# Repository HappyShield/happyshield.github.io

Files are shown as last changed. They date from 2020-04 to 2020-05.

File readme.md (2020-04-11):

# HappyShield.GitGub.io Contribution Guide

## Translations

### Introduction

Thank you so much for your help translating the HappyShield website and instructions!

We hope to translate the following files in this website (`XX` is the [ISO 639-1 code](https://en.wikipedia.org/wiki/List_of_ISO_639-1_codes) for the language): 

<pre>
* index_<b>XX</b>.md <i>(Homepage)</i>
* Instructions/HandCreasing/handCreasing_<b>XX</b>.md <i>(Hand creasing method instructions)</i>
* Instructions/LaserCut/laserCut_<b>XX</b>.md <i>(Laser-cut method instructions)</i>
* Instructions/LaserCutAndPressureCreasing/laserCutAndPressureCreasing_<b>XX</b>.md  <i>(Laser-cut and pressure-creasing method instructions) </i>
* Instructions/WaveShield/waveShield_<b>XX</b>.md <i>(WaveShield production method instructions) </i>
</pre>

### Instructions

Here's how to contribute translations!

### 1. Create a Free GitHub Account

1. If you don't have one already, [create a free GitHub account](https://github.com/join). (If you sign up using an academic email address you are eligible for a free 2-year upgrade to GitHub Pro, but this is not necessary for creating and editing translations to happyshield.github.io).
2. Navigate to [this repository](https://github.com/HappyShield/happyshield.github.io), making sure that you are viewing the main version of the repository: "HappyShield/happyshield.github.io" 

To translate (or edit an existing translation):

### 2. Create and Edit Translation Files

Watch [our video explaining how to create and edit translations files for HappyShield.Github.io here!](https://youtu.be/XLiHhSyrW8A)

The instructions are also shown below: 

##### If the translation file already exists:

1. Navigate to the relevant file in this repository.
2. Click "Edit this File"
3. Type any changes you would like to make to the text in the file. 
4. Add a description explaining the changes you have made.
5. Commit the changes ("Propose File Change")

You can also see this process explained nicely here! https://guides.github.com/activities/hello-world/#commit

##### If the translation file does not yet exist:

1. Navigate to the English version of the file (for example: `Instructions/HandCreasing/handCreasing_EN.md`) which you will be translating into another language. 
2. Click the edit button.
3. Select all of the text in the file and copy it.
4. Close the file. You should have made no changes, so no commit is necessary. 
5. Navigate to the folder where the file should exist.
6. Click create new file, and choose the appropriate name: `Instructions/HandCreasing/handCreasing_TR.md` for "Hand Creasing" instructions in Turkish (TR), for example.
7. Paste.
8. Edit this text, replacing English with your translated text.
7. If you want to save your progress at any point, commit the changes, and provide a description of the changes made since the previous commit.  

#### What should I translate? 

Please translate the following files from English (EN), into your language: 

(Please note that the English version of the homepage (`index.md`) has no `_EN` ending. When creating your translation for this page, please name your new, translated copy of the home page `index_XX.md` where `XX` is your languages's [ISO 639-1 code](https://en.wikipedia.org/wiki/List_of_ISO_639-1_codes).)

<pre>
* index_<b>XX</b>.md <i>(Homepage)</i>
* Instructions/HandCreasing/handCreasing_<b>XX</b>.md <i>(Hand creasing method instructions)</i>
* Instructions/LaserCut/laserCut_<b>XX</b>.md <i>(Laser-cut method instructions)</i>
* Instructions/LaserCutAndPressureCreasing/laserCutAndPressureCreasing_<b>XX</b>.md  <i>(Laser-cut and pressure-creasing method instructions) </i>
* Instructions/WaveShield/waveShield_<b>XX</b>.md <i>(WaveShield production method instructions) </i>
</pre>

When translating these files, please also modify the "header" of the file to correspond to your language:

**Translating Instructions Files**

For example, if we are translating `Instructions/HandCreasing/handCreasing_EN.md` the header we would see to begin with would be:

<pre>
---
layout: page
title: <b>Hand Creasing</b>
tagline: &nbsp <span class="instructionsTaglineEmojiLinks"> <a href="https://youtu.be/8RvlrtrebBE"><i class="em em-video_camera" aria-role="presentation" aria-label="VIDEO CAMERA"></i></a> <a href = "https://github.com/HappyShield/HappyShield/tree/master/Templates/HandCreasing" ><i class="em em-triangular_ruler" aria-role="presentation" aria-label="TRIANGULAR RULER"></i></a></span>
permalink: /hand-creasing/<b>en</b>/
language: <b>en</b>
---
</pre>

When translating instructions files please:

1. Translate the `title` field
2. Update the `permalink` field to the [ISO 639-1 code](https://en.wikipedia.org/wiki/List_of_ISO_639-1_codes) of your language.
3. Update the `language` field to the [ISO 639-1 code](https://en.wikipedia.org/wiki/List_of_ISO_639-1_codes) of your language.

For example, for Portguese ([ISO 639-1](https://en.wikipedia.org/wiki/List_of_ISO_639-1_codes)=`PT`), this would result in:

<pre>
---
layout: page
title: <b>Vincar Manualmente</b>
tagline: &nbsp <span class="instructionsTaglineEmojiLinks"> <a href="https://youtu.be/8RvlrtrebBE"><i class="em em-video_camera" aria-role="presentation" aria-label="VIDEO CAMERA"></i></a> <a href = "https://github.com/HappyShield/HappyShield/tree/master/Templates/HandCreasing" ><i class="em em-triangular_ruler" aria-role="presentation" aria-label="TRIANGULAR RULER"></i></a></span>
permalink: /hand-creasing/<b>pt</b>/
language: <b>pt</b>
---
</pre>

**Translating Homepage File**

When translating the header for `index_XX.md`, please:

1. Translate the `tagline` field.
2. Update the `permalink` field to the [ISO 639-1 code](https://en.wikipedia.org/wiki/List_of_ISO_639-1_codes) of your language.
3. Update the `language` field to the [ISO 639-1 code](https://en.wikipedia.org/wiki/List_of_ISO_639-1_codes) of your language.
3. Remove the `redirect_from` field. 

(No need to translate the title "HappyShield"!) : )

So for example, the header in the English version of the homepage (`index.md`) looks like this to begin with: 

<pre>
---
layout: page
title: HappyShield
tagline: <b>Curved Crease Origami Face Shield For Infection Control</b>
permalink: /<b>en</b>/
language: <b>en</b>
redirect_from: /
---
</pre>

After translating to Lithuanian (`LT`) for example, the header should look like this: 

<pre>
---
layout: page
title: HappyShield
tagline: <b>Origami Veido Skydai Infekcijos Kontrolei</b>
permalink: /<b>lt</b>/
language: <b>lt</b>
---
</pre>

### 3. Submit a Pull Request for Your Translation

When you are ready for your work to be incorporated into the main repository, you will submit a **"Pull request"**, which is a request to have these changes incorporated into the live website.

Watch [our video explaining how to submit a pull request for your translations files for HappyShield.Github.io here!](https://youtu.be/eBnob0MgYTU) 

The instructions are also shown below: 

1. Click **Pull Request**. 
2. Click **Create Pull Request**.
3. Add any helpful description along with your Pull Request to explain to others what you have added or changed to the text.
3. **Submit your Pull Request**. 

Auri (or whoever is managing the repository!) will review and approve the pull request, and then merge these into the main repository, where they should be rendered on the live website within 3-5 minutes. : )

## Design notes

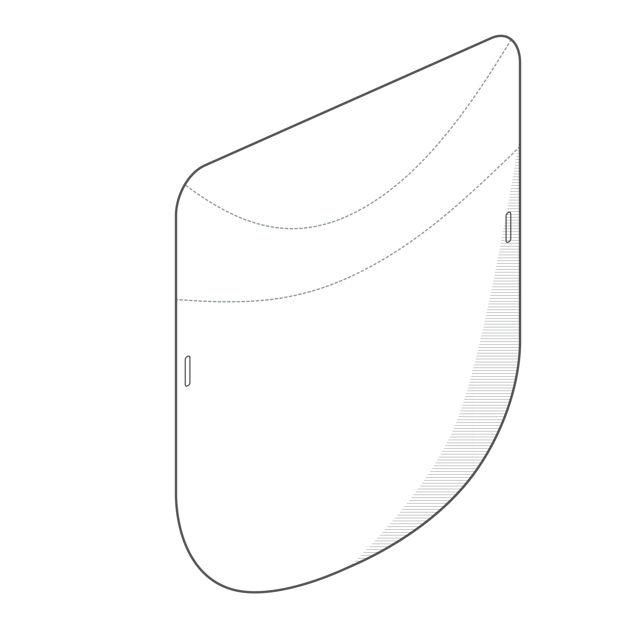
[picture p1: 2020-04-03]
assets/images/HS_Concept_00.gif

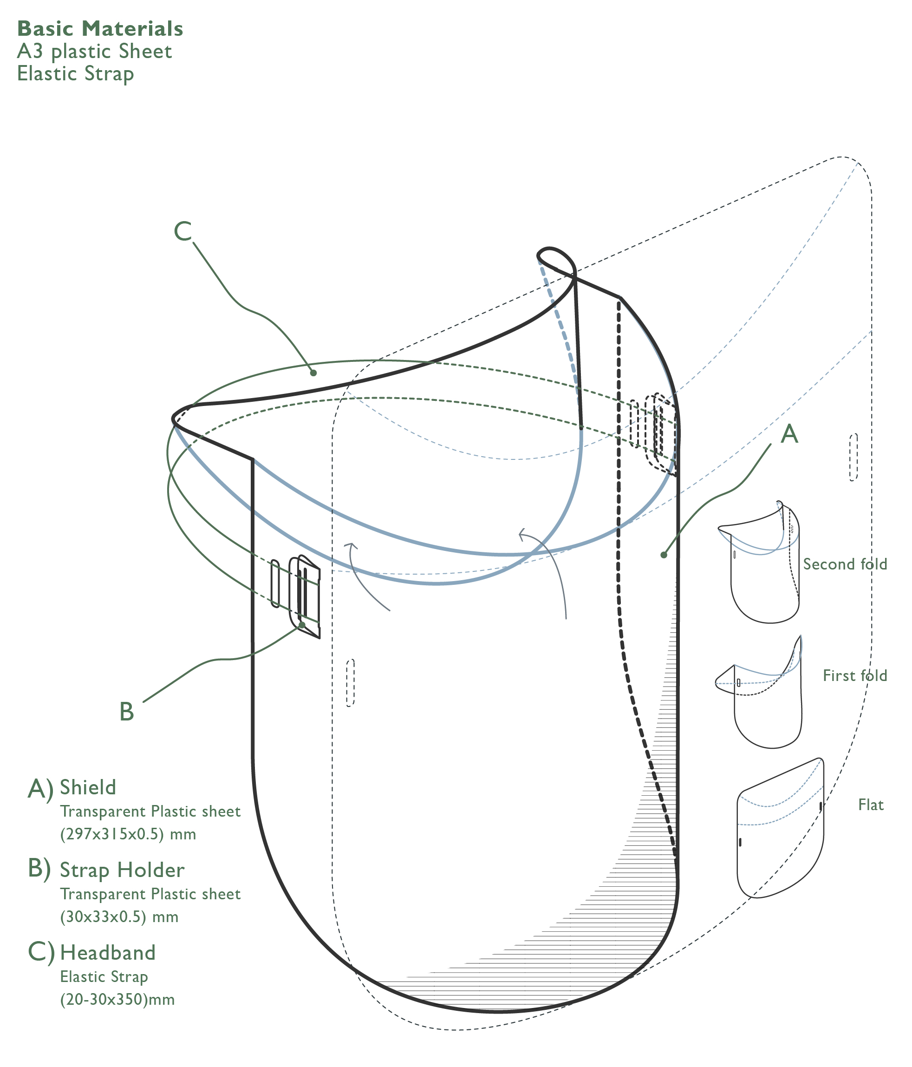
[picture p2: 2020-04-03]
assets/images/SFC_COVER_00.jpg

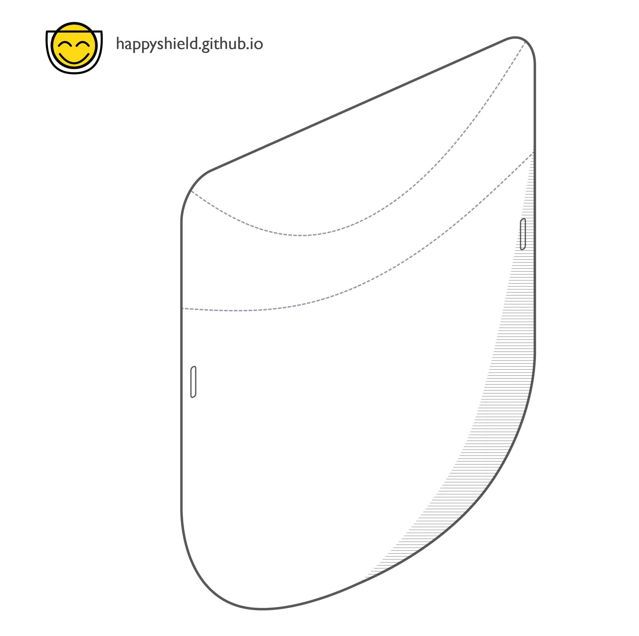
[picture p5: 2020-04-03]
assets/images/HS_GIF_01.gif

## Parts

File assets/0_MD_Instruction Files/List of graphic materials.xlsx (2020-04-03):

Priority Order | Category | Graphics | PDF | Text | Markdown Version | Templates | Video Footage Taken | Video Footage Put into folder | Selected Photos put into folder | Video Edited and Exported
1 | Main Promo Video |  |  |  |  |  | Yes, Auri has taken a fair bit of various movements with the shields, and we have some video and photos of antiopi wearing and doffing and donning the shield | yes auri put into Publicity videos folder | no - working on selecting photos from antiopi's photoshoot and will add these once done | No
2 | Factory Production (AKA laser cutting and pressing) | Done | yes | yes | No | yes | mostly? | auri has added some - apologies for poor quality of video of laser cutting and pressing steps! If completely unusable, could try to film some more today! Let me know @joe! : ) | no | no
3 | DIY (manual creasing) | Yes | Yes | yes | No | yes | yes | yes | no | no
4 | Cardboard and Sandwich Bag Method | No | No | No | No | No | yes | yes | no | no
5 | Laser Cutting - waiting for reply from Tom about fluids through gaps | yes | No | yes | No | No | no - not great, but some exists | yes

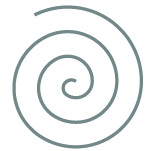
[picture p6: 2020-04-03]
Instructions/UniversalAssets/Materials/HS_FP_MetalWire.jpg

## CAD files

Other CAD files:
assets/0_MD_Instruction Files/HS_FP_Instructions/Template/3PartPressJigTemplate_400x400mm.dwg
assets/0_MD_Instruction Files/HS_FP_Instructions/Template/3PartPressJigTemplate_800x200mm.dwg
assets/0_MD_Instruction Files/HS_FP_Instructions/Template/ShieldsTemplate_620x645mm.dwg
assets/0_MD_Instruction Files/HS_FP_Instructions/Template/ShieldsTemplate_620x340mm.dwg

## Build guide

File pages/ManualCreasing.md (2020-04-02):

---
layout: page
title: "Method: Manual Soft Creasing"
permalink: /manual-soft-creasing/english/
---

## Materials

1. 1x A3 Acetate / PET Sheet
2. 

## Tools 

1. Ballpoint pen
2. Scissors 
3. 

## Instructions

1. Download your tracing template format ([A4 for A3 shields](https://github.com/smileyFaceShield/smileyfaceshield/raw/master/TemplatesAndCNCFilesForScoringFoldingCutting/ShieldScoringFoldingCutting/DIYFromHome/SmileyFaceShield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), Letter for Tabloid shields). If you do not have access to printers, you can draw your own template. Our tracing templates have dimensions!

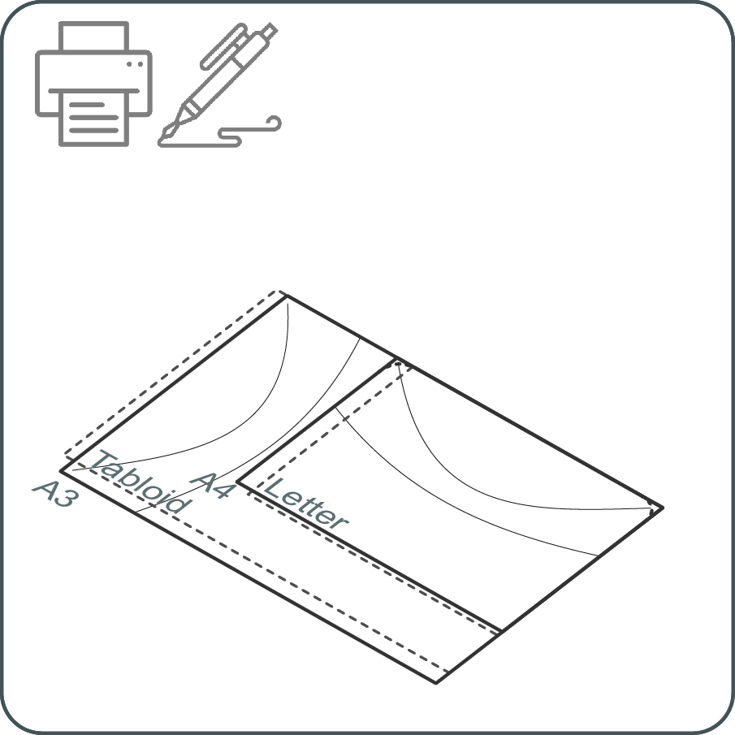
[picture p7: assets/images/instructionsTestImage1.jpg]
Instructions Image Test


2. Place your transparent sheet on the template. Mark the holes location with a ballpoint pen. Don’t worry about the ink, it can be removed with a cloth damped with alcohol.  

3. Mark strap holders and the lower and upper corner rounds for cutting. 

4.

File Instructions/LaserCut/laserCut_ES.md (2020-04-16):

---
layout: page
title: Laser-Cut 
tagline: &nbsp <span class="instructionsTaglineEmojiLinks"><a href = "https://github.com/HappyShield/HappyShield/tree/master/Templates/LaserCut" ><i class="em em-triangular_ruler" aria-role="presentation" aria-label="TRIANGULAR RULER"></i></a></span>
permalink: /laser-cut/es/
language: es
---

<script src="https://snapwidget.com/js/snapwidget.js"></script>
<iframe src="https://snapwidget.com/embed/811086" class="snapwidget-widget" allowtransparency="true" frameborder="0" scrolling="no" style="border:none; overflow:hidden;  width:100%; "></iframe>

---

## Disclaimer

---

The University of Cambridge (UC) and the University of Queensland (UQ) make no warranty of any kind, express or implied, about the design, characteristics, durability, proper use or performance of the HappyShield, including but not limited to implied warranties of merchantability and fitness for any particular purpose. The HappyShield is designed to minimise exposure to fluids and sprays, but UC and UQ do not warrant that HappyShield will protect users from COVID-19 infection or any other infectious disease. Nothing in this material constitutes medical advice, and users should seek their own medical advice about whether HappyShield is suitable for the use they intend, and whether they should use it in conjunction with any other medical or other strategies. To the fullest extent allowed by law, UC and UQ exclude all implied warranties, guarantees, terms and conditions. UC and UQ are not liable for any claims, demands, damages or injuries, including but not limited to property damage, bodily injury or illness, death, indirect, special or consequential damages (“the Claims”) arising out of using the HappyShield, and users of HappyShield release UC and UQ and their officers, employees, contractors and agents from all Claims.

---

--- 

## Tools

---

* Laser-cutter
* Scissors or razor blade

---

## Materials

---

**Shield**

* 0.5 mm thick Polyethylene terephthalate (PET) or Acetate sheet at least 
* 20 mm wide knit elastic strap (70% polyester 30% rubber)

---

---

# Instructions

---

# 1

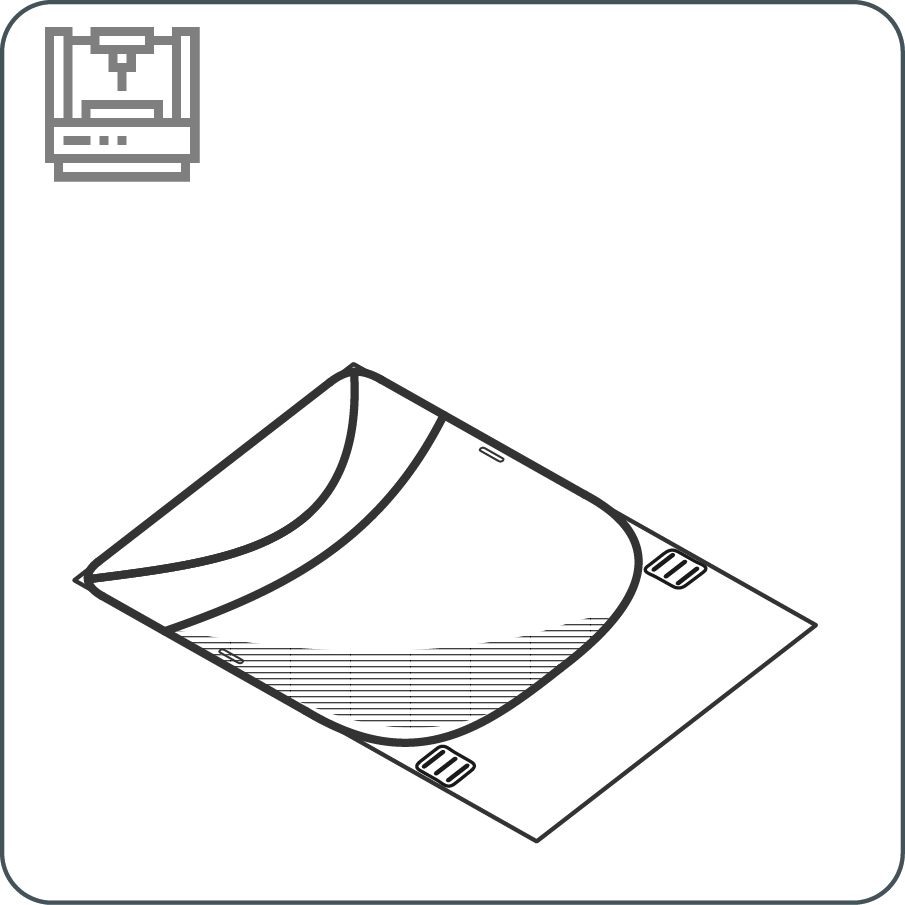
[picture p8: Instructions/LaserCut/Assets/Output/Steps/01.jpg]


Laser-cut the clear plastic sheet material using the template file, ensuring that your laser-cutter power and speed settings ensure a cut completely through the depth of the material.

---

# 2	

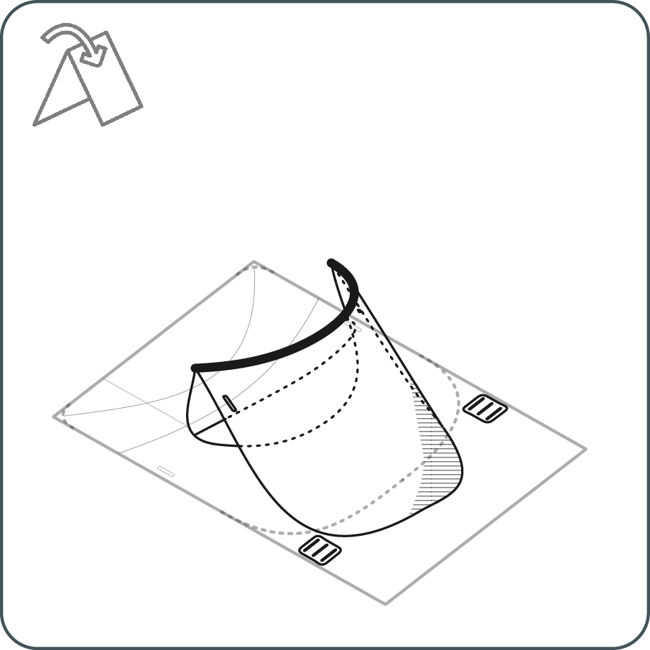
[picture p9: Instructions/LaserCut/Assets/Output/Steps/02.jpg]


Starting on end of one of the crease curves, and working your way to the other end of the curve, gently pinch the sheet to fold it along the curve. 

--- 

# 3 	

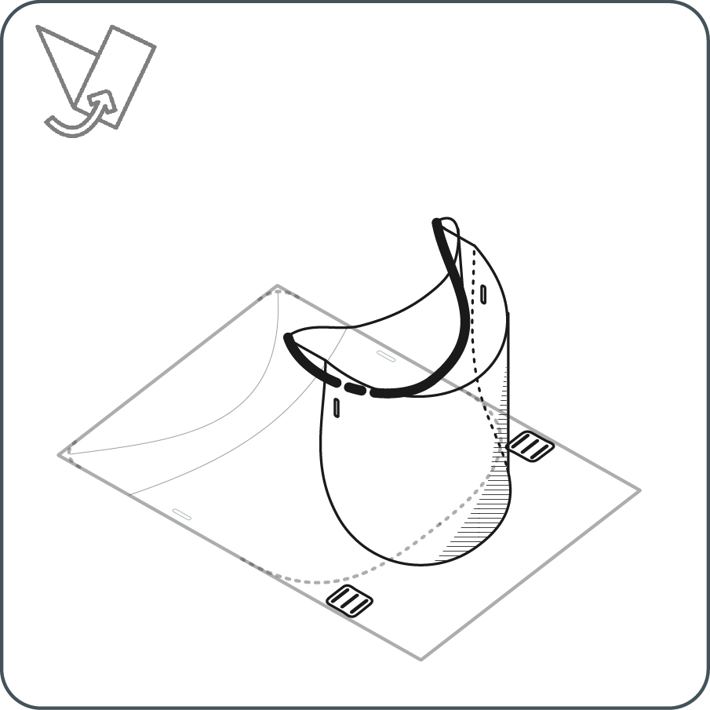
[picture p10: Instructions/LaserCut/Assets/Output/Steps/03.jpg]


Fold the second curve using the same procedure as in Step 2.

---

# 4	

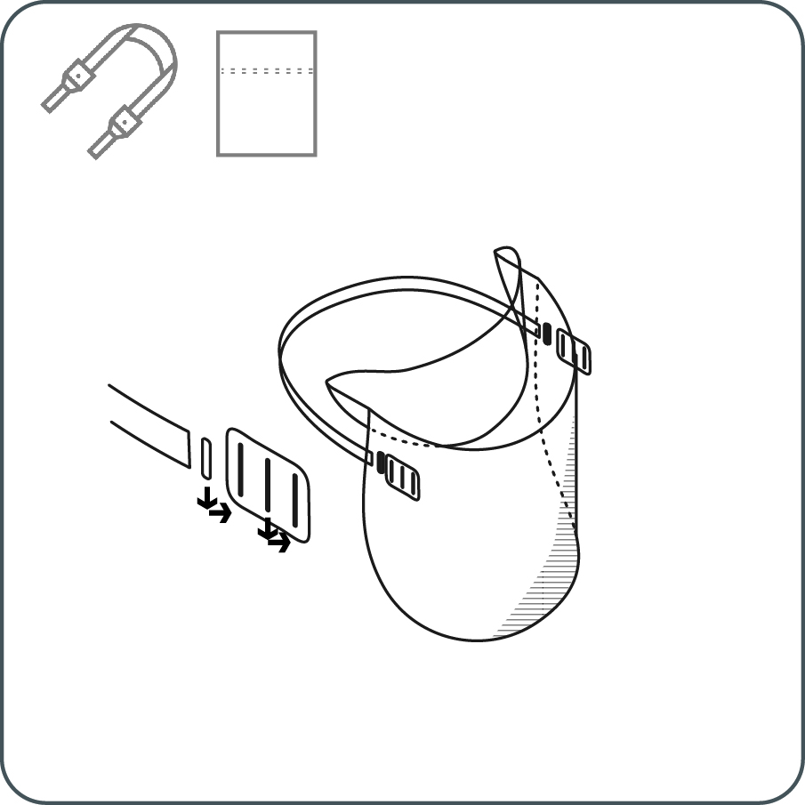
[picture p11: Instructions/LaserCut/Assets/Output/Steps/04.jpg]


Thread the strap through the friction clips. Pass the friction clips through the holes in the shield from the back side of the shield to the front.

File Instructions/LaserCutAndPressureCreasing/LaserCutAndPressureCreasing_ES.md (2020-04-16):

---
layout: page
title: Laser-cut and Pressure Creasing
tagline: &nbsp <span class="instructionsTaglineEmojiLinks"> <a href = "https://youtu.be/IPKiPi-Tne8"><i class="em em-video_camera" aria-role="presentation" aria-label="VIDEO CAMERA"></i></a> <a href = "https://github.com/HappyShield/HappyShield/tree/master/Templates/LaserCutAndPressureCreasing" ><i class="em em-triangular_ruler" aria-role="presentation" aria-label="TRIANGULAR RULER"></i></a></span>
permalink: /pressure-creasing/es/
language: es
---

<script src="https://snapwidget.com/js/snapwidget.js"></script>
<iframe src="https://snapwidget.com/embed/810066" class="snapwidget-widget" allowtransparency="true" frameborder="0" scrolling="no" style="border:none; overflow:hidden;  width:100%; "></iframe>

---

## Disclaimer

---

The University of Cambridge (UC) and the University of Queensland (UQ) make no warranty of any kind, express or implied, about the design, characteristics, durability, proper use or performance of the HappyShield, including but not limited to implied warranties of merchantability and fitness for any particular purpose. The HappyShield is designed to minimise exposure to fluids and sprays, but UC and UQ do not warrant that HappyShield will protect users from COVID-19 infection or any other infectious disease. Nothing in this material constitutes medical advice, and users should seek their own medical advice about whether HappyShield is suitable for the use they intend, and whether they should use it in conjunction with any other medical or other strategies. To the fullest extent allowed by law, UC and UQ exclude all implied warranties, guarantees, terms and conditions. UC and UQ are not liable for any claims, demands, damages or injuries, including but not limited to property damage, bodily injury or illness, death, indirect, special or consequential damages (“the Claims”) arising out of using the HappyShield, and users of HappyShield release UC and UQ and their officers, employees, contractors and agents from all Claims.

---

--- 

## Tools

---

* Laser-cutter
* 10-tonne press
* Pliers capable of cutting 1 mm steel wire rope
* Scissors or razor blade
* Drill or screw-driver

---

## Materials

---

**3-Part Press Jig**

* 4 mm MDF
* 1 mm steel wire rope   
* 6-20 mm wood screws
* Clear plastic tape

**Shield**

* 0.5 mm thick Polyethylene terephthalate (PET) or Acetate sheet
* 20 mm wide knit elastic strap (70% polyester 30% rubber)

---

---

# Instructions

---

## 3-Part Press Jig 

---

# 1 	

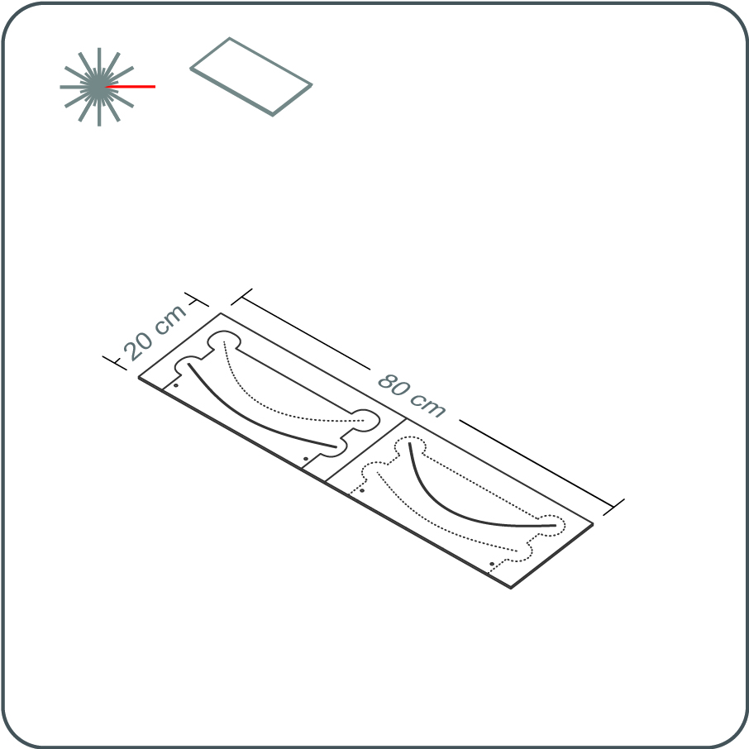
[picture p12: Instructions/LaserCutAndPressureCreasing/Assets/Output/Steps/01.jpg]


Download the laser-cutting template for the 3-part press jig which fits the bed of your laser-cutting machine. (The dimensions of the cutting templates are given in the filenames.) Laser-cut the MDF using the template file.

---

# 2

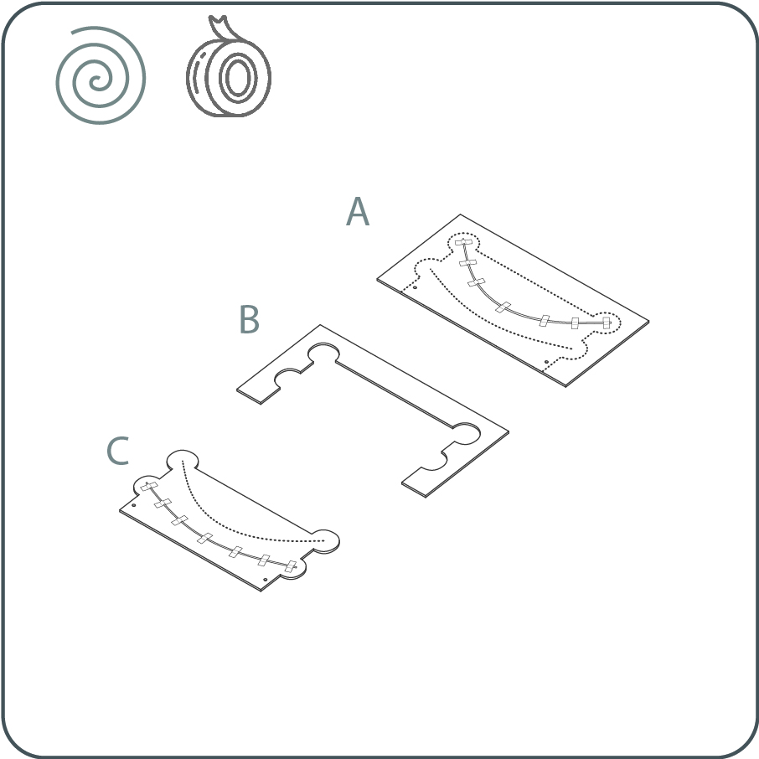
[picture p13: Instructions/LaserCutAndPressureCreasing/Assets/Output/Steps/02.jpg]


Remove the 3 parts of the press jig from the laser-cutter. Cut the wire rope to the length of the dashed curves in parts A and C of the template.
Tape the metal wire onto the dashed curve the groove of the parts A and C of the press jig, being sure not to deviate from the dashed curve, and not to extend beyond the ends of the dashed curve. 

---

# 3

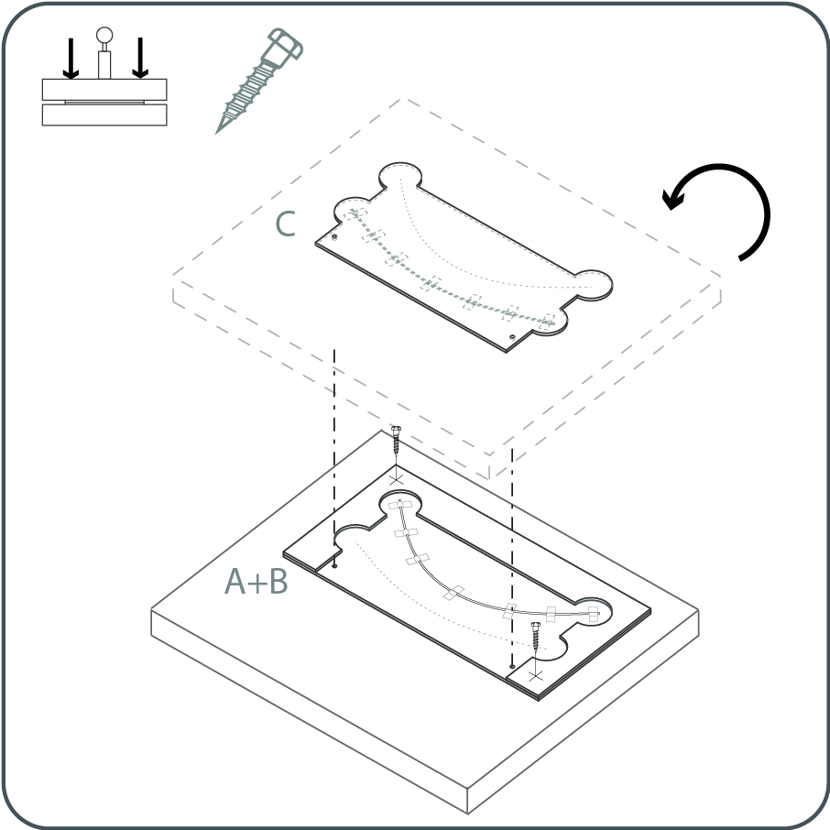
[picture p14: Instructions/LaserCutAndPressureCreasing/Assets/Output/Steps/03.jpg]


Attach Part B to top A using short wood screws. Attach the combined Part A and B to a block as needed to distribute pressure evenly across the jig surface. Do the same for Part C.

--- 

## Shield

---

# 1

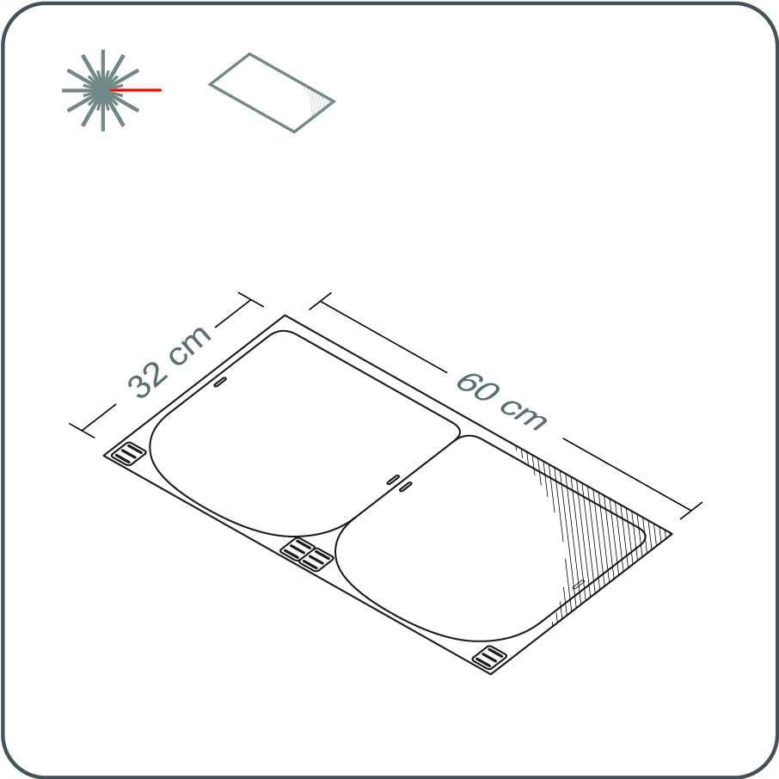
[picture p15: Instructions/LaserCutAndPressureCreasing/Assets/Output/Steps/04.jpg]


Download the HappyShield laser-cutting template which fits in the bed of your laser-cutting machine. (The dimensions of the cutting templates are given in the filenames.)

---

# 2	

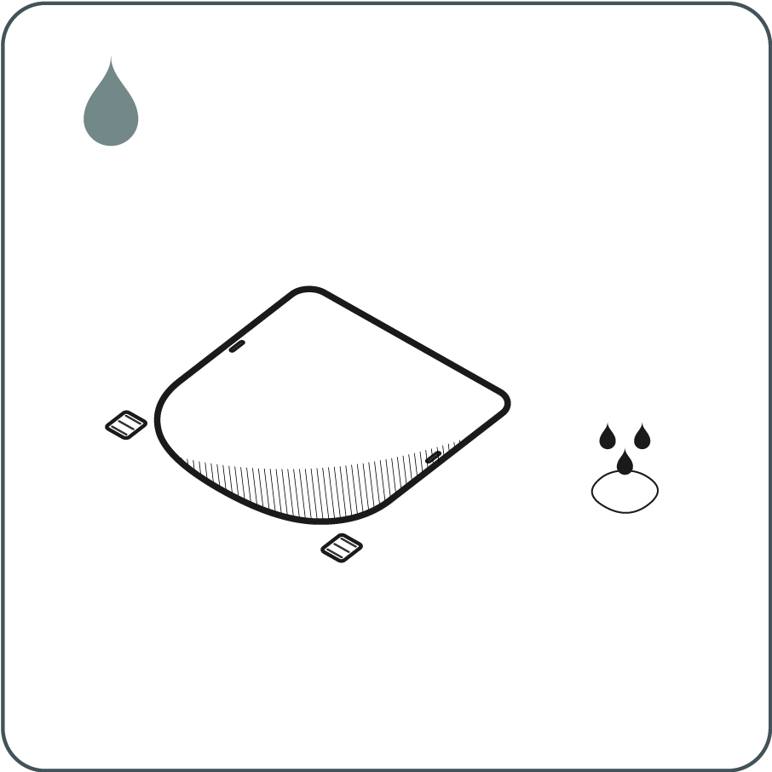
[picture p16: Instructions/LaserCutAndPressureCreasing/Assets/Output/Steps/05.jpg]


Laser-cut the clear plastic sheet material using the template file, ensuring that your laser-cutter power and speed settings ensure a cut completely through the depth of the material.

Once cut, remove the resulting shields and friction clips from the laser-cutter bed. If desired, wipe the edges of the shields and clips with alcohol, or wash with any soap to remove any laser-cutting residues from the sheet. 

--- 

# 3

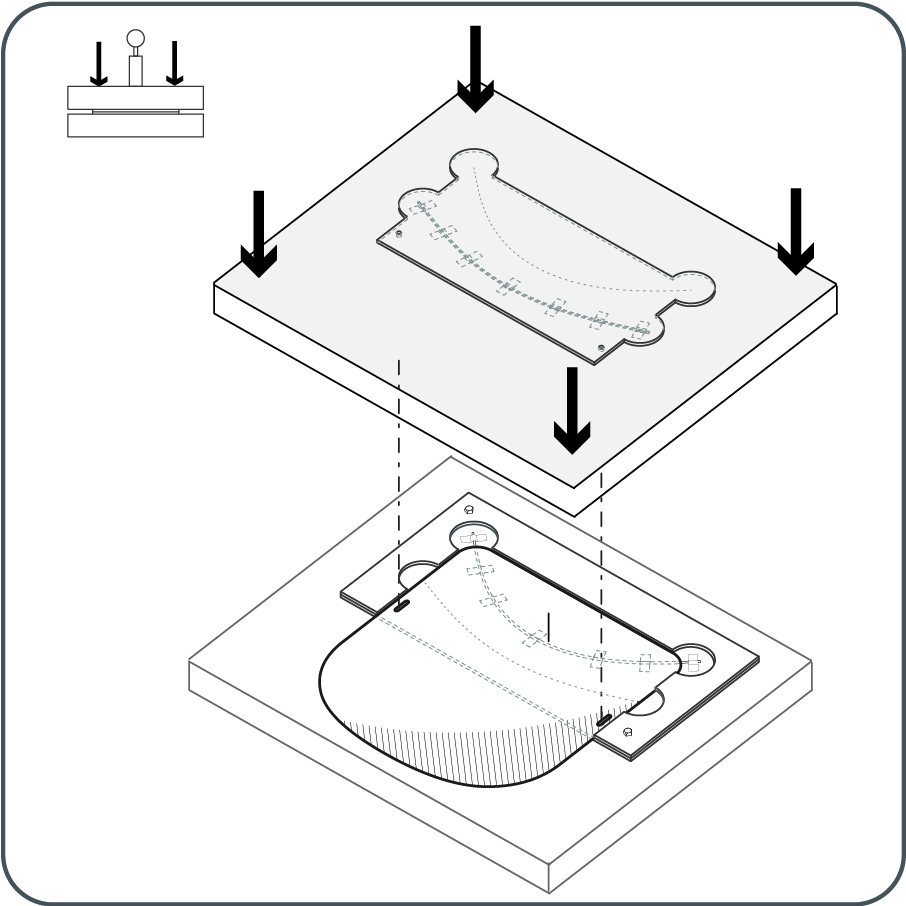
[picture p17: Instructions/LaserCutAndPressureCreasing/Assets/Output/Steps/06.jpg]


Insert shield into the 3-part press jig and press to create the curved creases.

---

# 4	

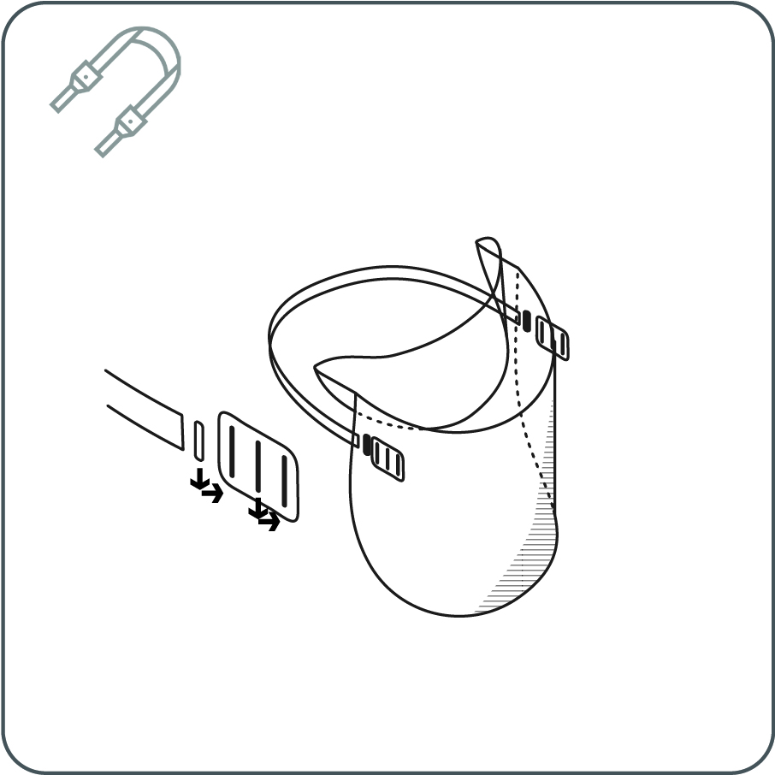
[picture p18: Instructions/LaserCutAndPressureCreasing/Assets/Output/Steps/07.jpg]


Cut a 400 mm length of elastic strap. Thread the strap through the friction clips on both ends.

---

# 5	

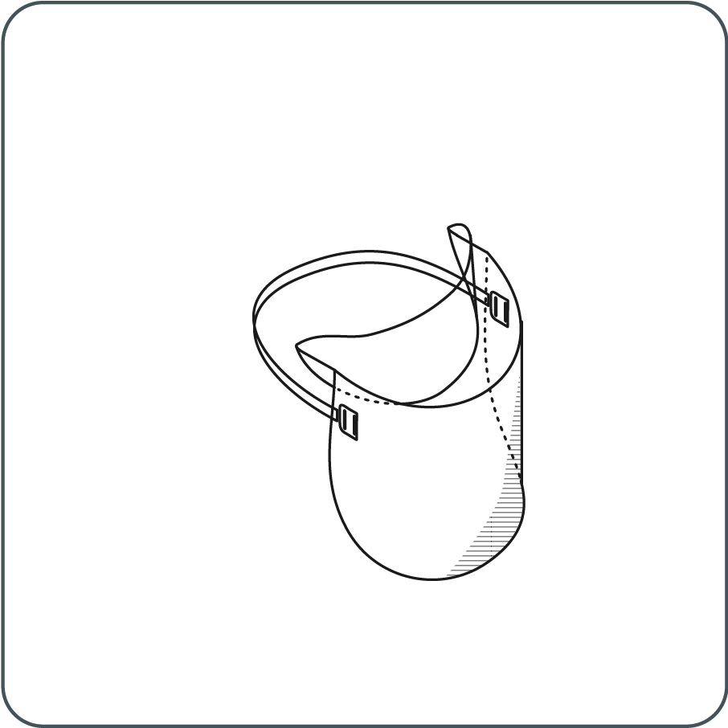
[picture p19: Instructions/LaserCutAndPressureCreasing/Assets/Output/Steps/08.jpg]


Pass the threaded friction clips through the holes in the shield from back to front.

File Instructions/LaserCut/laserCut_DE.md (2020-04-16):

---
layout: page
title: Laser-Cut 
tagline: &nbsp <span class="instructionsTaglineEmojiLinks"><a href = "https://github.com/HappyShield/HappyShield/tree/master/Templates/LaserCut" ><i class="em em-triangular_ruler" aria-role="presentation" aria-label="TRIANGULAR RULER"></i></a></span>
permalink: /laser-cut/de/
language: de
---

<script src="https://snapwidget.com/js/snapwidget.js"></script>
<iframe src="https://snapwidget.com/embed/811086" class="snapwidget-widget" allowtransparency="true" frameborder="0" scrolling="no" style="border:none; overflow:hidden;  width:100%; "></iframe>

---

## Disclaimer

---

Die University of Cambridge (UC) und die University of Queensland (UQ) übernehmen keinerlei ausdrückliche oder stillschweigende Garantie für das Design, die Eigenschaften, die Haltbarkeit, den ordnungsgemäßen Gebrauch oder die Leistung des HappyShield, einschließlich, aber nicht beschränkt auf stillschweigende Garantien der Marktgängigkeit und der Eignung für einen bestimmten Zweck. Das HappyShield ist so konzipiert, dass die Exposition gegenüber Flüssigkeiten und Sprays minimiert wird, aber UC und UQ garantieren nicht, dass das HappyShield die Benutzer vor einer COVID-19-Infektion oder einer anderen Infektionskrankheit schützt. Nichts in diesem Material stellt einen medizinischen Rat dar, und Benutzer sollten ihren eigenen medizinischen Rat darüber einholen, ob HappyShield für die beabsichtigte Anwendung geeignet ist und ob sie es in Verbindung mit anderen medizinischen oder anderen Strategien verwenden sollten. Soweit gesetzlich zulässig, schließen UC und UQ alle stillschweigenden Garantien, Gewährleistungen, Bestimmungen und Bedingungen in vollem Umfang aus. UC und UQ sind nicht haftbar für Ansprüche, Forderungen, Schäden oder Verletzungen, einschließlich, aber nicht beschränkt auf Sachschäden, Körperverletzung oder Krankheit, Tod, indirekte, besondere oder Folgeschäden ("die Ansprüche"), die sich aus der Verwendung von HappyShield ergeben, und die Benutzer von HappyShield entbinden UC und UQ und ihre leitenden Angestellten, Mitarbeiter, Auftragnehmer und Vertreter von allen Ansprüchen.

---

--- 

## Werkzeuge

---

* Laserschneider
* Schere oder Rasierklinge 

---

## Materialien

---

**Schild**

* 0.5 mm dickes Polyethylene terephthalate (PET) oder Acetat Blatt
* 20 mm breites Gummiband (70% Polyester 30% Gummi)

---

---

# Anleitung

---

# 1



Schneiden Sie das durchsichtige Kunststoffplattenmaterial mit Hilfe der Schablonendatei lasergeschnitten. Stellen Sie dabei sicher, dass Ihre Einstellungen für Leistung und Geschwindigkeit des Laserschneiders einen Schnitt durch die gesamte Tiefe des Materials gewährleisten.

---

# 2	



Beginnen Sie am Ende einer der Faltkurven und arbeiten Sie sich zum anderen Ende der Kurve vor, indem Sie das Blatt vorsichtig zusammendrücken, um es entlang der Kurve zu falten. 

--- 

# 3 	



Falten Sie die zweite Kurve nach dem gleichen Verfahren wie in Schritt 2.

---

# 4	



Fädeln Sie das Band durch die Reibungsklammern. Führen Sie die Reibungsklammern durch die Löcher im Schild von der Rückseite des Schildes nach vorne.

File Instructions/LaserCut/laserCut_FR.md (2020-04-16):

---
layout: page
title: Découpe au laser 
tagline: &nbsp <span class="instructionsTaglineEmojiLinks"><a href = "https://github.com/HappyShield/HappyShield/tree/master/Templates/LaserCut" ><i class="em em-triangular_ruler" aria-role="presentation" aria-label="TRIANGULAR RULER"></i></a></span>
permalink: /laser-cut/fr/
language: fr
---

<script src="https://snapwidget.com/js/snapwidget.js"></script>
<iframe src="https://snapwidget.com/embed/811086" class="snapwidget-widget" allowtransparency="true" frameborder="0" scrolling="no" style="border:none; overflow:hidden;  width:100%; "></iframe>

---

## Décharge de responsabilité

---

L'Université de Cambridge (UC) et l'Université du Queensland (UQ) ne donnent aucune garantie d'aucune sorte, expresse ou implicite, sur la conception, les caractéristiques, la durabilité, le bon usage ou les performances du HappyShield, y compris, mais sans s'y limiter, les garanties implicites de qualité marchande et d'adéquation à un usage particulier. Le HappyShield est conçu pour minimiser l'exposition aux liquides et aux sprays, mais l'UC et l'UQ ne garantissent pas que le HappyShield protégera les utilisateurs contre l'infection par COVID-19 ou toute autre maladie infectieuse. Rien dans ce matériel ne constitue un avis médical, et les utilisateurs doivent demander leur propre avis médical pour savoir si HappyShield est adapté à l'usage qu'ils en ont l'intention, et s'ils doivent l'utiliser en conjonction d'autres stratégies médicales ou autres. Dans toute la mesure permise par la loi, l'UC et l'UQ excluent toutes les garanties implicites, les garanties, les termes et les conditions. L'UC et l'UQ ne sont pas responsables des réclamations, demandes, dommages ou blessures, y compris, mais sans s'y limiter, les dommages matériels, les blessures ou maladies corporelles, la mort, les dommages indirects, spéciaux ou consécutifs ("les Réclamations") découlant de l'utilisation de HappyShield, et les utilisateurs de HappyShield libèrent l'UC et l'UQ et leurs dirigeants, employés, entrepreneurs et agents de toutes les Réclamations.

---

--- 

## Outils

---

* Découpeuse laser
* Ciseaux ou lame de rasoir

---

## Matériel

---

**Bouclier**

* Feuille de polyéthylène téréphtalate (PET) ou d'acétate d'au moins 0,5 mm d'épaisseur
* Bande élastique tricotée de 20 mm de large (70% polyester 30% caoutchouc)

---

---

# Instructions

---

# 1



Découpez au laser la feuille de plastique transparent à l'aide du fichier modèle, en vous assurant que les réglages de puissance et de vitesse de votre laser de découpe garantissent une découpe complète au travers du matériau.

---

# 2	



En commençant à l'extrémité de l'une des courbes de pliage, et en vous rendant à l'autre extrémité de la courbe, pincez doucement la feuille pour la plier le long de la courbe. 

--- 

# 3 	



Pliez la deuxième courbe en suivant la même procédure que celle de l'étape 2.

---

# 4	



Faites passer la sangle dans les clips à friction. Faites passer les clips à friction à travers les trous du bouclier, de l'arrière vers l'avant.

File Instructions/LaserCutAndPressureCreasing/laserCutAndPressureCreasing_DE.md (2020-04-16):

---
layout: page
title: Laserschneider und Druckfaltung
tagline: &nbsp <span class="instructionsTaglineEmojiLinks"> <a href = "https://youtu.be/IPKiPi-Tne8"><i class="em em-video_camera" aria-role="presentation" aria-label="VIDEO CAMERA"></i></a> <a href = "https://github.com/HappyShield/HappyShield/tree/master/Templates/LaserCutAndPressureCreasing" ><i class="em em-triangular_ruler" aria-role="presentation" aria-label="TRIANGULAR RULER"></i></a></span>
permalink: /pressure-creasing/de/
language: de
---

<script src="https://snapwidget.com/js/snapwidget.js"></script>
<iframe src="https://snapwidget.com/embed/810066" class="snapwidget-widget" allowtransparency="true" frameborder="0" scrolling="no" style="border:none; overflow:hidden;  width:100%; "></iframe>

---

## Disclaimer

---

Die University of Cambridge (UC) und die University of Queensland (UQ) übernehmen keinerlei ausdrückliche oder stillschweigende Garantie für das Design, die Eigenschaften, die Haltbarkeit, den ordnungsgemäßen Gebrauch oder die Leistung des HappyShield, einschließlich, aber nicht beschränkt auf stillschweigende Garantien der Marktgängigkeit und der Eignung für einen bestimmten Zweck. Das HappyShield ist so konzipiert, dass die Exposition gegenüber Flüssigkeiten und Sprays minimiert wird, aber UC und UQ garantieren nicht, dass das HappyShield die Benutzer vor einer COVID-19-Infektion oder einer anderen Infektionskrankheit schützt. Nichts in diesem Material stellt einen medizinischen Rat dar, und Benutzer sollten ihren eigenen medizinischen Rat darüber einholen, ob HappyShield für die beabsichtigte Anwendung geeignet ist und ob sie es in Verbindung mit anderen medizinischen oder anderen Strategien verwenden sollten. Soweit gesetzlich zulässig, schließen UC und UQ alle stillschweigenden Garantien, Gewährleistungen, Bestimmungen und Bedingungen in vollem Umfang aus. UC und UQ sind nicht haftbar für Ansprüche, Forderungen, Schäden oder Verletzungen, einschließlich, aber nicht beschränkt auf Sachschäden, Körperverletzung oder Krankheit, Tod, indirekte, besondere oder Folgeschäden ("die Ansprüche"), die sich aus der Verwendung von HappyShield ergeben, und die Benutzer von HappyShield entbinden UC und UQ und ihre leitenden Angestellten, Mitarbeiter, Auftragnehmer und Vertreter von allen Ansprüchen.

---

--- 

## Werkzeuge

---

* Laserschneider
* 10-Tonnen Presse
* Zange zum Schneiden von 1 mm Stahldrahtseilen
* Schere oder Rasierklinge
* Bohrer oder Schraubendreher

---

## Materialien

---

**3-teilige Presse-Vorrichtung**

* 4 mm MDF
* 1 mm Stahldrahtseil   
* 6-20 mm Holzschrauben
* Durchsichtiges Klebeband aus Kunststoff

**Schild**

* 0,5 mm dicke Polyethylenterephthalat- (PET) oder Acetat-Folie
* 20 mm breites elastisches Band (70% Polyester 30% Gummi)

---

---

# Anleitung

---

## 3-teilige Presse-Vorrichtung

---

# 1 	



Laden Sie die Laserschneideschablone für die 3-teilige Pressvorrichtung herunter, die auf das Bett Ihrer Laserschneidemaschine passt. (Die Abmessungen der Schneideschablonen sind in den Dateinamen angegeben.) Laserschneiden Sie das MDF mit Hilfe der Schablonendatei.

---

# 2



Entfernen Sie die drei Teile der Pressvorrichtung von der Laserschneidemaschine. Schneiden Sie das Drahtseil auf die Länge der gestrichelten Kurven in den Teilen A und C der Schablone ab.
Kleben Sie den Metalldraht auf die gestrichelte Kurve der Rille der Teile A und C der Pressvorrichtung und achten Sie darauf, dass er nicht von der gestrichelten Kurve abweicht und nicht über die Enden der gestrichelten Kurve hinausragt. 

---

# 3



Befestigen Sie Teil B mit kurzen Holzschrauben oben an Teil A. Befestigen Sie das kombinierte Teil A und B nach Bedarf an einem Block, um den Druck gleichmäßig über die Vorrichtungsfläche zu verteilen. Machen Sie dasselbe für Teil C.

--- 

## Schild

---

# 1



Laden Sie die HappyShield-Laserschneideschablone herunter, die in das Bett Ihrer Laserschneidemaschine passt. (Die Abmessungen der Schneideschablonen sind in den Dateinamen angegeben).

---

# 2	



Schneiden Sie das durchsichtige Kunststoffplattenmaterial mit Hilfe der Schablonendatei lasergeschnitten. Stellen Sie dabei sicher, dass Ihre Einstellungen für Leistung und Geschwindigkeit des Laserschneiders einen Schnitt durch die gesamte Tiefe des Materials gewährleisten.

Nach dem Schnitt entfernen Sie die entstandenen Schilder und Reibungsklammern vom Laserschneidbett. Falls gewünscht, wischen Sie die Ränder der Schilder und Klammern mit Alkohol ab oder waschen Sie sie mit Seife aus, um alle Laserschneidrückstände von der Folie zu entfernen. 
--- 

# 3



Schild in die 3-teilige Pressvorrichtung einlegen und pressen, um die gebogenen Falten zu erzeugen.

---

# 4	



Schneiden Sie ein elastisches Band von 400 mm Länge ab. Fädeln Sie das Band durch die Reibungsklammern an beiden Enden.

---

# 5	



Führen Sie die Reibungsklammern mit Gewinde von hinten nach vorne durch die Löcher in der Abschirmung.

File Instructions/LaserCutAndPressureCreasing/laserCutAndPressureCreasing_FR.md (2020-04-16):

---
layout: page
title: Découpe au laser et pliage sous pression
tagline: &nbsp <span class="instructionsTaglineEmojiLinks"> <a href = "https://youtu.be/IPKiPi-Tne8"><i class="em em-video_camera" aria-role="presentation" aria-label="VIDEO CAMERA"></i></a> <a href = "https://github.com/HappyShield/HappyShield/tree/master/Templates/LaserCutAndPressureCreasing" ><i class="em em-triangular_ruler" aria-role="presentation" aria-label="TRIANGULAR RULER"></i></a></span>
permalink: /pressure-creasing/fr/
language: fr
---

<script src="https://snapwidget.com/js/snapwidget.js"></script>
<iframe src="https://snapwidget.com/embed/810066" class="snapwidget-widget" allowtransparency="true" frameborder="0" scrolling="no" style="border:none; overflow:hidden;  width:100%; "></iframe>

---

## Décharge de responsabilité

---

L'Université de Cambridge (UC) et l'Université du Queensland (UQ) ne donnent aucune garantie d'aucune sorte, expresse ou implicite, sur la conception, les caractéristiques, la durabilité, le bon usage ou les performances du HappyShield, y compris, mais sans s'y limiter, les garanties implicites de qualité marchande et d'adéquation à un usage particulier. Le HappyShield est conçu pour minimiser l'exposition aux liquides et aux sprays, mais l'UC et l'UQ ne garantissent pas que le HappyShield protégera les utilisateurs contre l'infection par COVID-19 ou toute autre maladie infectieuse. Rien dans ce matériel ne constitue un avis médical, et les utilisateurs doivent demander leur propre avis médical pour savoir si HappyShield est adapté à l'usage qu'ils en ont l'intention, et s'ils doivent l'utiliser en conjonction avec d'autres stratégies médicales ou autres. Dans toute la mesure permise par la loi, l'UC et l'UQ excluent toutes les garanties implicites, les garanties, les termes et les conditions. L'UC et l'UQ ne sont pas responsables des réclamations, demandes, dommages ou blessures, y compris, mais sans s'y limiter, les dommages matériels, les blessures ou maladies corporelles, la mort, les dommages indirects, spéciaux ou consécutifs ("les Réclamations") découlant de l'utilisation de HappyShield, et les utilisateurs de HappyShield libèrent l'UC et l'UQ et leurs dirigeants, employés, entrepreneurs et agents de toutes les Réclamations.

---

--- 

## Outils

---

* Découpeuse laser
* Presse de 10 tonnes
* Pince capable de couper un câble d'acier de 1 mm
* Ciseaux ou lame de rasoir
* Perceuse ou tournevis

---

## Matériel

---

**Gabarit de presse en 3 parties**

* MDF (panneau de fibre à densité moyenne) 4 mm
* Câble d'acier de 1 mm   
* Vis à bois de 6-20 mm
* Ruban plastique transparent

**Bouclier**

* Feuille de polyéthylène téréphtalate (PET) ou d'acétate de 0,5 mm d'épaisseur
* Bande élastique tricotée de 20 mm de large (70% polyester 30% caoutchouc)

---

---

# Instructions

---

## Gabarit de presse en 3 parties 

---

# 1 	



Téléchargez le modèle de découpe laser pour le gabarit de presse en trois parties qui s'adapte au lit de votre machine de découpe laser. (Les dimensions des gabarits de découpe sont indiquées dans les noms de fichiers.) Découpez le MDF au laser à l'aide du modèle.

---

# 2



Retirez les 3 parties du gabarit de presse de la découpeuse laser. Coupez le câble métallique à la longueur des courbes en pointillés dans les parties A et C du modèle.
Collez le fil métallique sur la courbe en pointillés dans la rainure des parties A et C du gabarit de presse, en veillant à ne pas dévier de la courbe en pointillés, et à ne pas en dépasser les extrémités. 

---

# 3



Fixez la partie B au sommet A à l'aide de vis à bois courtes. Fixez les parties A et B combinées à un bloc selon les besoins pour répartir la pression de manière uniforme sur la surface du gabarit. Faites de même pour la partie C.

--- 

## Bouclier

---

# 1



Téléchargez le modèle de découpe laser HappyShield qui s'adapte au lit de votre machine de découpe laser. (Les dimensions des modèles de découpe sont indiquées dans les noms de fichiers).

---

# 2	



Découpez au laser la feuille de plastique transparent à l'aide du fichier modèle, en vous assurant que les réglages de puissance et de vitesse de votre laser de découpe garantissent une découpe complète au travers du matériau.

Une fois la découpe effectuée, retirez les boucliers et les clips de friction qui en résultent du lit de la découpeuse laser. Si vous le souhaitez, essuyez les bords des boucliers et des clips avec de l'alcool, ou lavez-les avec du savon pour éliminer les résidus de découpe au laser. 

--- 

# 3



Insérez le bouclier dans le gabarit de presse en trois parties et appuyez pour créer les plis courbés.

---

# 4	



Coupez une bande élastique de 400 mm de long. Faites passer la sangle dans les pinces à friction des deux extrémités.

---

# 5	



Faites passer les clips à friction filetés dans les trous du bouclier, de l'arrière vers l'avant.

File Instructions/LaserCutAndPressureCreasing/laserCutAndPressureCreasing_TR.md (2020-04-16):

---
layout: page
title: Laser Kesim ve Basınçlı Katlama
tagline: &nbsp <span class="instructionsTaglineEmojiLinks"> <a href = "https://youtu.be/IPKiPi-Tne8"><i class="em em-video_camera" aria-role="presentation" aria-label="VIDEO CAMERA"></i></a> <a href = "https://github.com/HappyShield/HappyShield/tree/master/Templates/LaserCutAndPressureCreasing" ><i class="em em-triangular_ruler" aria-role="presentation" aria-label="TRIANGULAR RULER"></i></a></span>
permalink: /pressure-creasing/tr/
---

<script src="https://snapwidget.com/js/snapwidget.js"></script>
<iframe src="https://snapwidget.com/embed/810066" class="snapwidget-widget" allowtransparency="true" frameborder="0" scrolling="no" style="border:none; overflow:hidden;  width:100%; "></iframe>

---

##  Sorumluluk Reddi

---

Cambridge Üniversitesi (UC) ve Queensland Üniversitesi (UQ), HappyShield'ın tasarımı, özellikleri, dayanıklılığı, uygun kullanımı veya performansı hakkında, satılabilirlik ve belirli bir amaca uygunluk hakkındaki zımni garantiyle sınırlı kalmamak üzere, açık veya zımni hiçbir garanti vermemektedir. HappyShield, sıvılara ve spreylere maruz kalmayı en aza indirecek şekilde tasarlanmıştır, ancak UC ve UQ, HappyShield'ın kullanıcıları COVID-19 enfeksiyonundan veya başka bulaşıcı hastalıklardan koruyacağını garanti etmez. Bu materyaldeki hiçbir şey tıbbi tavsiye oluşturmaz ve kullanıcılar HappyShield'in amaçladıkları kullanıma uygun olup olmadığı ve diğer tıbbi veya başka türden stratejilerle birlikte kullanmaları gerekip gerekmediği konusunda kendi tıbbi tavsiyelerini takip etmelidirler. Yasaların izin verdiği azami ölçüde, UC ve UQ tüm zımni garantileri, güvenceleri, şartları ve koşulları hariç tutar. UC ve UQ, HappyShield'ın kullanımından kaynaklanan mülki hasar, bedensel yaralanma veya hastalık, ölüm, dolaylı, özel veya buna bağlı zararlar (“Talepler”) dahil ancak bunlarla sınırlı olmamak üzere herhangi bir hak, talep, hasar veya yaralanmadan sorumlu değildir, ve HappyShield kullanıcıları UC ve UQ'yu ve memurlarını, çalışanlarını, yüklenicilerini ve temsilcilerini tüm taleplerden muaf tutar.

---

--- 

## Aletler

---

* Lazer kesici
* 10 tonluk baskı makinesi
* 1mm'lik çelik tel kabloyu kesebilecek pense
* Makas veya maket bıçağı
* Matkap veya tornavida

---

## Malzemeler

---

**3-Parçalı Baskı Şablonu**

* 4 mm MDF
* 1 mm çelik tel kablo
* 6-20 mm ahşap vida
* Şeffaf plastik bant

**Siperlik**

* 0.5 mm kalınlığında Polyethylene terephthalate (PET) veya Asetat Sayfa
* 20 mm genişliğinde elastik bant (70% polyester 30% lastik)

---

---

# Açıklamalar

---

## 3-Parçalı Baskı Şablonu

---

# 1 	



Lazer kesicinizin yatağına uyacak 3 parçalı baskı şablonunu sitemizden indirin. (Baskı şablonlarının ölçüleri dosya isimlerinde belirtilmiştir.) MDF'yi şablonu kullanarak kesin.

---
# 2



Baskı şablonunun 3 parçasını lazer kesiciden çıkarın. Çelik kabloyu şablonun A ve C kısımlarındaki kesikli çizgili eğrilerin uzunluğunda kesin. Çelik kabloyu baskı şablonunun A ve C kısımlarındaki çizgili eğrilerin olukları boyunca bantlayın. Çizgili eğrinin hizasından taşmadığınızdan ve eğrinin bittiği yerde bitirdiğinizden emin olun.

---
# 3



B parçasını A parçasının üstüne gelecek şekilde ahşap vidalarla birleştirin. Birleştirilmiş A ve B parçalarını şablon yüzeyinde basıncı eşit yayması için bir bloğa ekleyin. C parçası için de aynısını yapın.

--- 
## Siperlik

---

# 1



Lazer kesicinizin yatağına uyacak şablonu sitemizden indirin. (Baskı şablonlarının ölçüleri dosya isimlerinde belirtilmiştir.)

---

# 2	



Şeffaf plastik levhayı şablonu kullanarak lazer kesiciyle kesin. Lazer kesici güç ve hız ayarlarının malzemeyi derinliğince tamamen kesecek şekilde ayarlandığından emin olun. 

Kesilmiş siperlikleri ve sıkıştırma klipslerini lazer kesicinin yatağından çıkarın. Isterseniz, lazer kesim artıklarını gidermek için siperliklerin ve klipslerin köşelerini alkolle silebilir ya da sabunla yıkayabilirsiniz. 

--- 

# 3



Siperliği 3 parçalı baskı şablonuna yerleştirin ve eğrili katlamaları oluşturmak için bastırın.

---

# 4	



400 mm uzunluğunda bir elastik bant kesin. Bantın 2 ucunu sıkıştırma klipslerinden geçirin.

---

# 5	



Dişli klipsleri sperliğin üzerindeki deliklerden arkadan öne doğru geçirin.

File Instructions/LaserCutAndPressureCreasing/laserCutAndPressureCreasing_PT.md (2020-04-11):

---
layout: page
title: Corte a Laser e Prensa
tagline: &nbsp <span class="instructionsTaglineEmojiLinks"> <a href = "https://youtu.be/IPKiPi-Tne8"><i class="em em-video_camera" aria-role="presentation" aria-label="VIDEO CAMERA"></i></a> <a href = "https://github.com/HappyShield/HappyShield/tree/master/Templates/LaserCutAndPressureCreasing" ><i class="em em-triangular_ruler" aria-role="presentation" aria-label="TRIANGULAR RULER"></i></a></span>
permalink: /pressure-creasing/pt/
language: pt
---

<script src="https://snapwidget.com/js/snapwidget.js"></script>
<iframe src="https://snapwidget.com/embed/810066" class="snapwidget-widget" allowtransparency="true" frameborder="0" scrolling="no" style="border:none; overflow:hidden;  width:100%; "></iframe>

---

## Aviso Legal (Disclaimer)

---

The University of Cambridge (UC) and the University of Queensland (UQ) make no warranty of any kind, express or implied, about the design, characteristics, durability, proper use or performance of the HappyShield, including but not limited to implied warranties of merchantability and fitness for any particular purpose. The HappyShield is designed to minimise exposure to fluids and sprays, but UC and UQ do not warrant that HappyShield will protect users from COVID-19 infection or any other infectious disease. Nothing in this material constitutes medical advice, and users should seek their own medical advice about whether HappyShield is suitable for the use they intend, and whether they should use it in conjunction with any other medical or other strategies. To the fullest extent allowed by law, UC and UQ exclude all implied warranties, guarantees, terms and conditions. UC and UQ are not liable for any claims, demands, damages or injuries, including but not limited to property damage, bodily injury or illness, death, indirect, special or consequential damages (“the Claims”) arising out of using the HappyShield, and users of HappyShield release UC and UQ and their officers, employees, contractors and agents from all Claims.

---

--- 

## Ferramentas

---

* Cortador a laser
* Prensa de 10 toneladas
* Alicate capaz de cortar cabo de aço com 1 mm
* Tesoura ou lâmina de corte
* Berbequim ou chave de fendas

---

## Materiais

---

**Estrutura de 3 partes para a prensa**

* MDF de 4 mm
* Cabo de aço com 1 mm   
* Parafusos de madeira de 6-20 mm
* Fita adesiva transparente

**Viseira**

* Polietileno tereftalato (PET) com 0,5 mm de espessura ou como alternativa uma folha de acetato
* Fita elástica larga de 20 mm (70% poliéster 30% borracha)

---

---

# Instruções

---

## Estrutura de 3 peças para a prensa

---

# 1 	



Descarregue o modelo da estrutura de 3 peças para a prensa com as dimensões apropriadas para a o seu cortador a laser. (As dimensões dos modelos de corte estão descritas no nome do ficheiro.) Corte a laser o MDF usando o modelo do ficheiro.

---

# 2



Remova a estrutura de 3 peças para a prensa do cortador a laser. Corte o cabo de aço com o comprimento das curvas dobráveis das partes A e C do modelo.
Com a fita adesiva, prenda o cabo de aço na ranhura da curva dobrável das partes A e C da estrutura da prensa, garantindo que o cabo de aço não se desvia da curva dobrável, nem se estende para além da mesma. 

---

# 3



Junte a parte B ao topo da parte A usando parafusos de madeira curtos. Junte a combinação das partes A e B a um bloco distribuindo a pressão uniformemente pela superfície da estrutura. Faça o mesmo para a parte C.

--- 

## Viseira

---

# 1



Descarregue o modelo da viseira com as dimensões apropriadas para a o seu cortador a laser. (As dimensões dos modelos de corte estão descritas no mome do ficheiro.)

---

# 2	



Corte a laser a folha transparente usando o modelo do ficheiro, assegurando que as configurações da potência e velocidade do cortador a laser são as indicadas para cortar completamente o material na sua profundidade. 

Uma vez cortado, remova a viseira e os clipes de fricção do cortador a laser. Se desejar, limpe as margens da viseira e dos clipes de fricção com álcool, ou lave com água e sabão para remover quaisquer resíduos do cortador a laser. 

--- 

# 3



Insira a viseira na estrutura de três partes da prensa e prense para criar as curvas dobráveis. 

---

# 4	



Corte 400 mm de comprimento de fita elástica. Passe as duas pontas do elástico pelos clipes de fricção.

---

# 5	



Passe os clipes de fricção pelos orifícios na viseira de trás para a frente

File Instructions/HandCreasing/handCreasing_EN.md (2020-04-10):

---
layout: page
title: Hand Creasing
tagline: &nbsp <span class="instructionsTaglineEmojiLinks"> <a href="https://youtu.be/8RvlrtrebBE"><i class="em em-video_camera" aria-role="presentation" aria-label="VIDEO CAMERA"></i></a> <a href = "https://github.com/HappyShield/HappyShield/tree/master/Templates/HandCreasing" ><i class="em em-triangular_ruler" aria-role="presentation" aria-label="TRIANGULAR RULER"></i></a></span>
permalink: /hand-creasing/en/
language: en
---

<i class="em em-timer_clock" aria-role="presentation" aria-label=""></i>: 10-15′

---

<script src="https://snapwidget.com/js/snapwidget.js"></script>
<iframe src="https://snapwidget.com/embed/810064" class="snapwidget-widget" allowtransparency="true" frameborder="0" scrolling="no" style="border:none; overflow:hidden;  width:100%; "></iframe>

---

---

## Disclaimer

---

The University of Cambridge (UC) and the University of Queensland (UQ) make no warranty of any kind, express or implied, about the design, characteristics, durability, proper use or performance of the HappyShield, including but not limited to implied warranties of merchantability and fitness for any particular purpose. The HappyShield is designed to minimise exposure to fluids and sprays, but UC and UQ do not warrant that HappyShield will protect users from COVID-19 infection or any other infectious disease. Nothing in this material constitutes medical advice, and users should seek their own medical advice about whether HappyShield is suitable for the use they intend, and whether they should use it in conjunction with any other medical or other strategies. To the fullest extent allowed by law, UC and UQ exclude all implied warranties, guarantees, terms and conditions. UC and UQ are not liable for any claims, demands, damages or injuries, including but not limited to property damage, bodily injury or illness, death, indirect, special or consequential damages (“the Claims”) arising out of using the HappyShield, and users of HappyShield release UC and UQ and their officers, employees, contractors and agents from all Claims.

---

--- 

## Tools

---

* Scissors or razor blade
* Ballpoint pen
* Ruler
* Butter Knife
* Printer

---

## Materials

---

**Shield**

* 0.5 mm thick Polyethylene terephthalate (PET) or Acetate sheet at least 
* 20 mm wide knit elastic strap (70% polyester 30% rubber)
* Tape

---

---

# Instructions

---

# 1 



Download your tracing template. A4-sized templates are available for A3-sized shields. Letter-sized templates are available for Tabloid-sized shields. If you do not have access to a printer, you can draw your own template using the dimensions shown on the template.

---

# 2

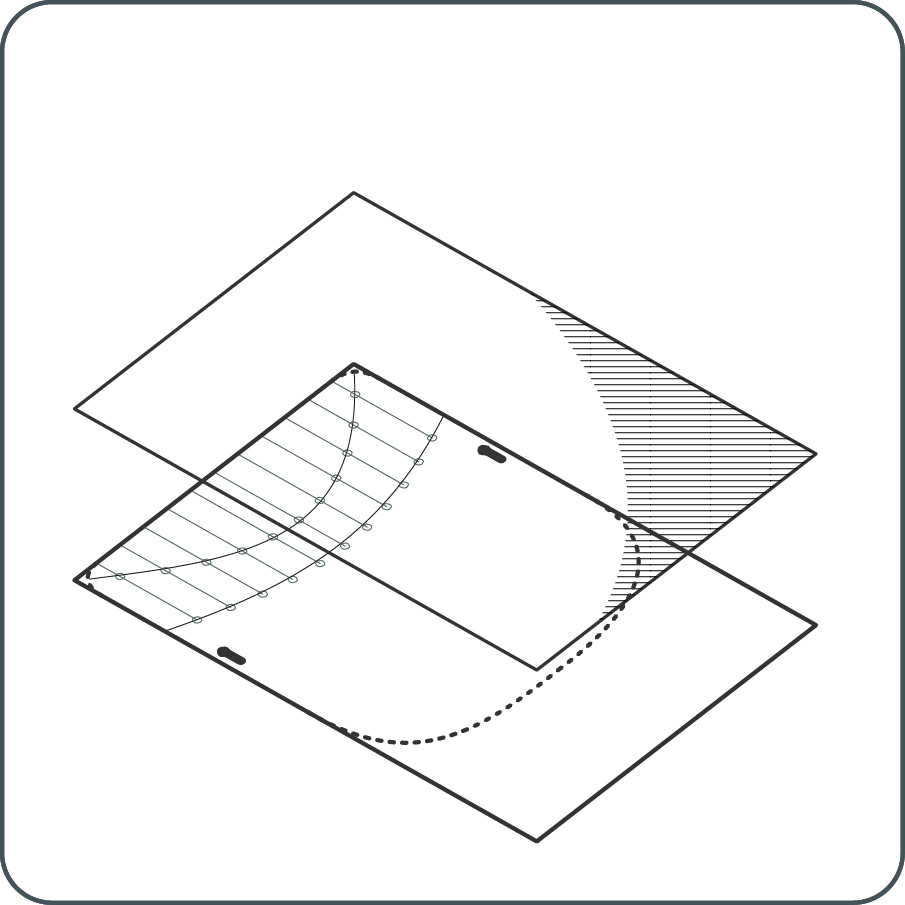
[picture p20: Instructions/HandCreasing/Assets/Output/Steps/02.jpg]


Place your transparent sheet on the template. Mark the location of the strap holes with your pen or marker. Don’t worry about the ink, it can be removed with a cloth damped with alcohol. 

---

# 3

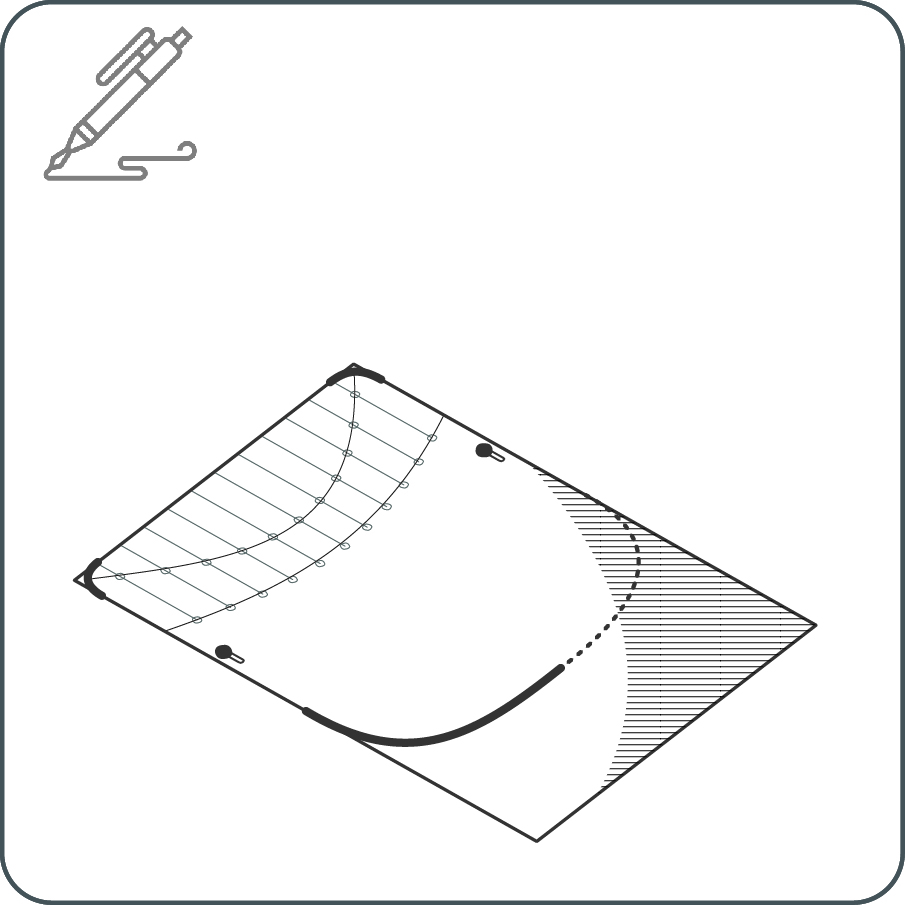
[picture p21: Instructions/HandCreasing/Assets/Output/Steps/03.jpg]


Trace out the boundary of the shield for cutting out. 

---

# 4

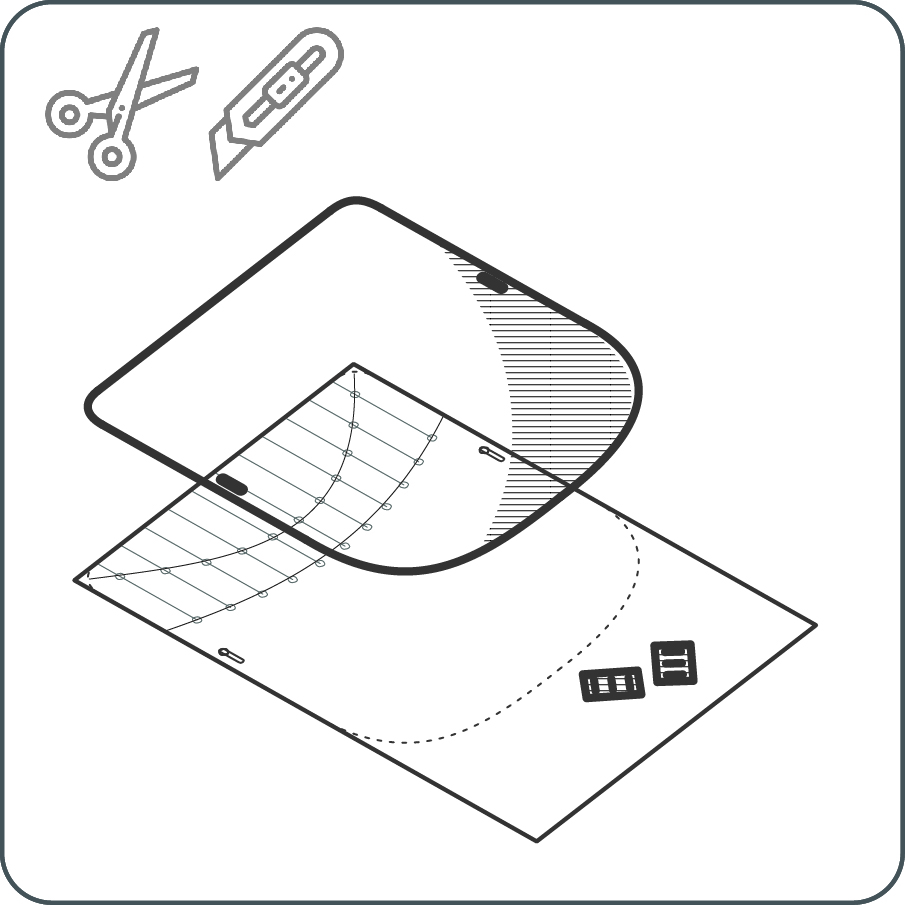
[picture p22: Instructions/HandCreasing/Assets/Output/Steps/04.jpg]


Cut the boundary shape of the shield out using scissors or a razor blade. Cut out the strap holes. You can use a hole-puncher as well to make these holes. 

Next, cut out the friction clips using a razor blade.

Now, let’s score a smile on that face!

---

## Creasing Method A

---

# 5A

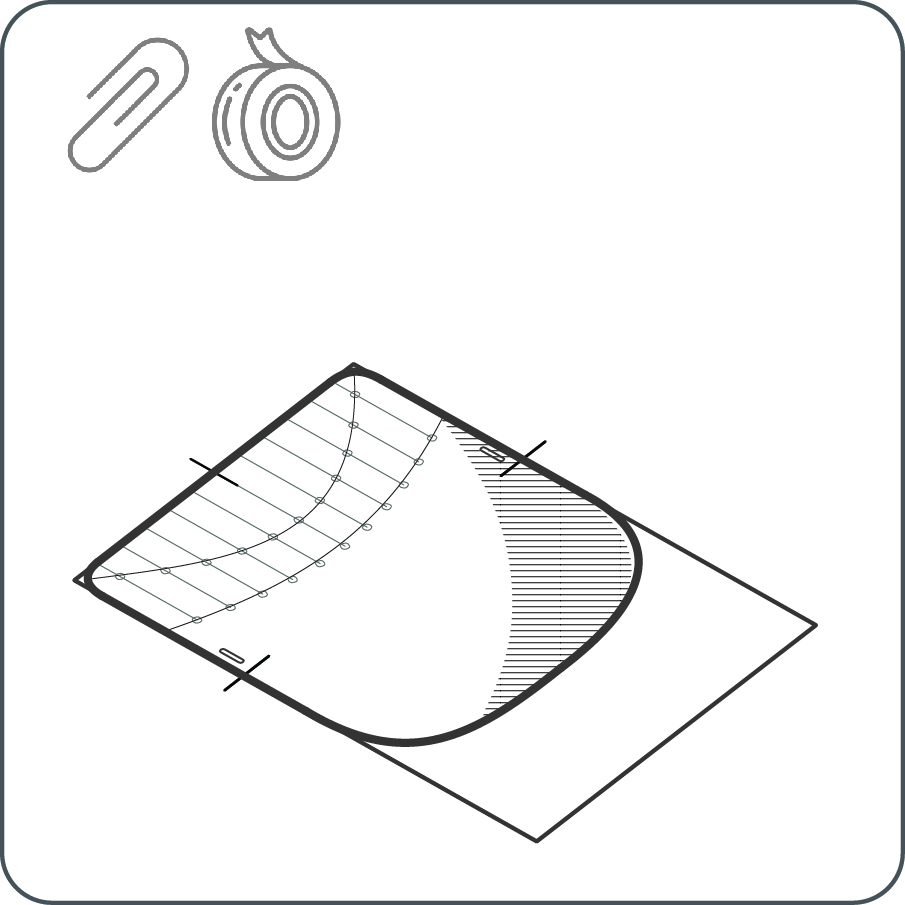
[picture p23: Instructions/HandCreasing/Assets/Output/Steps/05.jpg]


Place your transparent sheet on the template. Fix with clips or tape for precise tracing.

---

# 6A

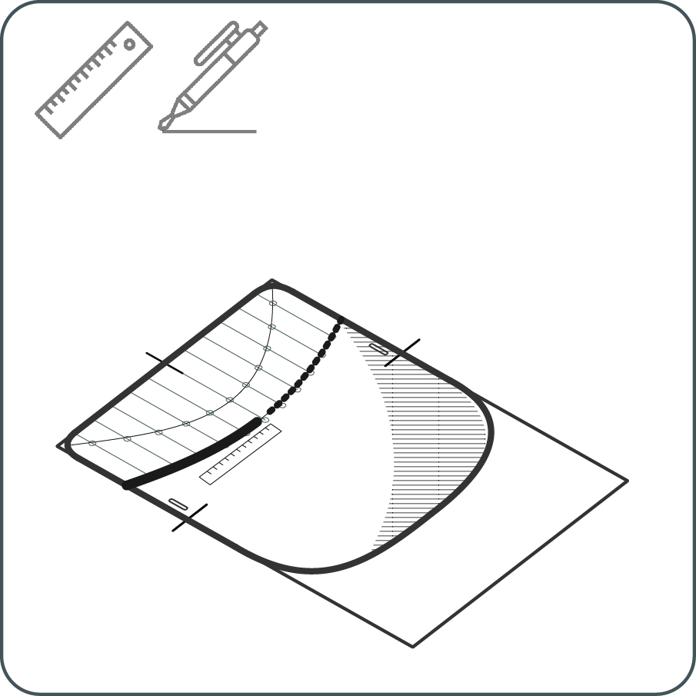
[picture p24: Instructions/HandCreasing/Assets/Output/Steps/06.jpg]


Using a ruler, and applying pressure, trace the straight segments between each consecutive point, using 2-3 strokes as needed until you see a visible indentation in the sheet.

---

# 7A

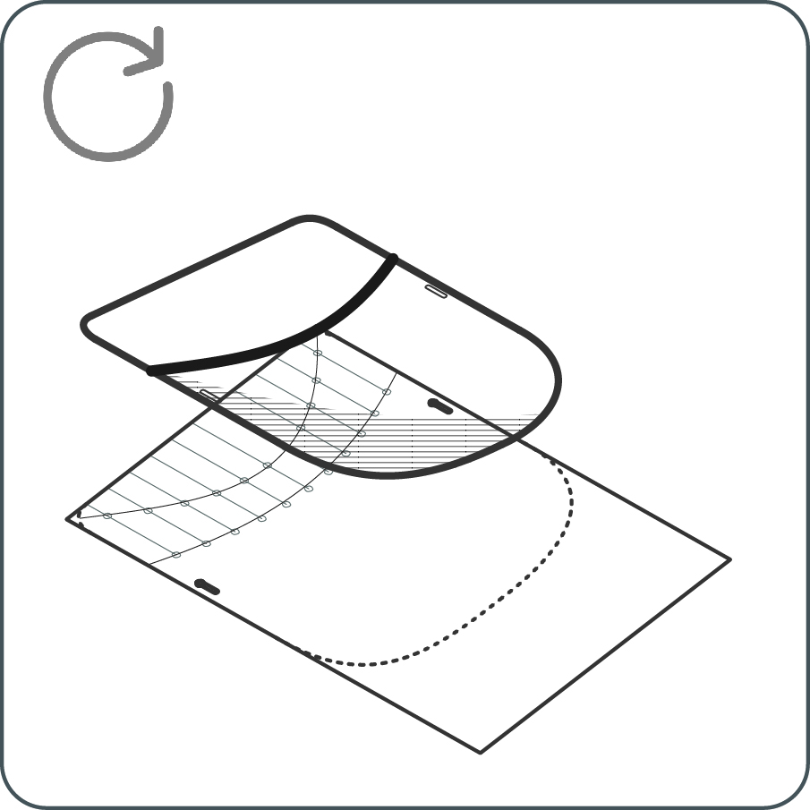
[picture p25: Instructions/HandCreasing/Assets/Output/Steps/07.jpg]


Flip the transparent sheet.  Fix the sheet and the template again.

---

# 8A

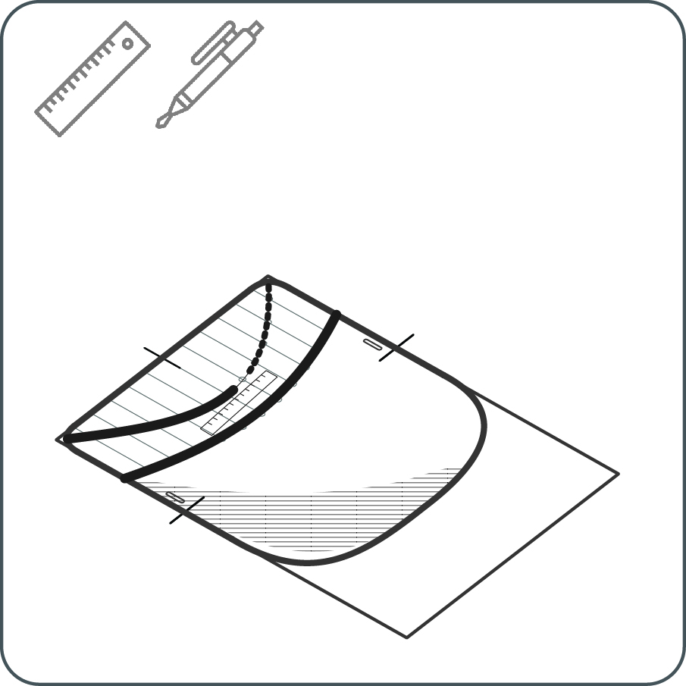
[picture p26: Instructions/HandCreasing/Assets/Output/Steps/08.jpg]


Trace the second curve in the same way as in step **6A**.

---

## Creasing Method B

---

# 5B	

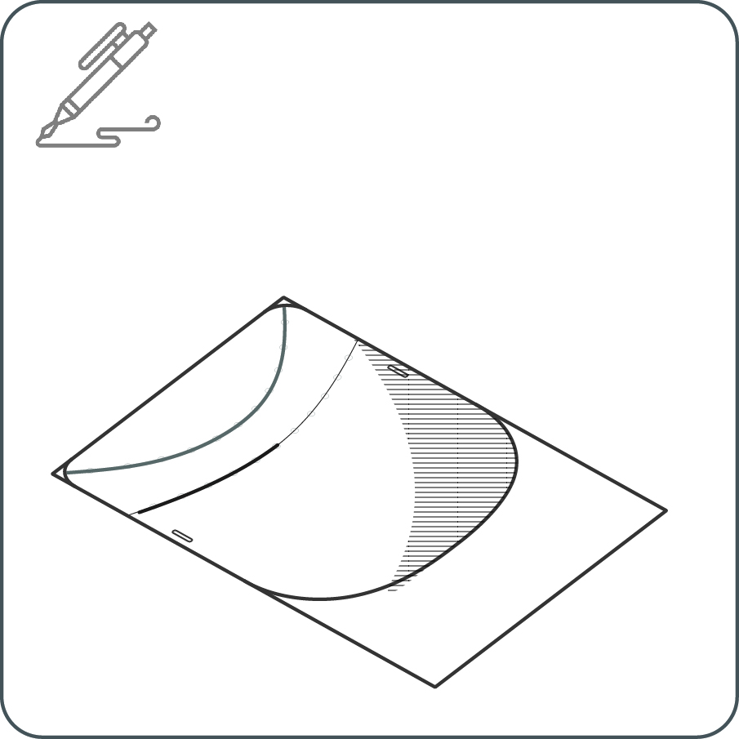
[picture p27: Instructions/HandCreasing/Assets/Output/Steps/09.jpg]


Trace the folding curves with a pen (no additional pressure is required here). If desired, fix the sheet to the template with clips or tape for more precise tracing.

---

# 6B

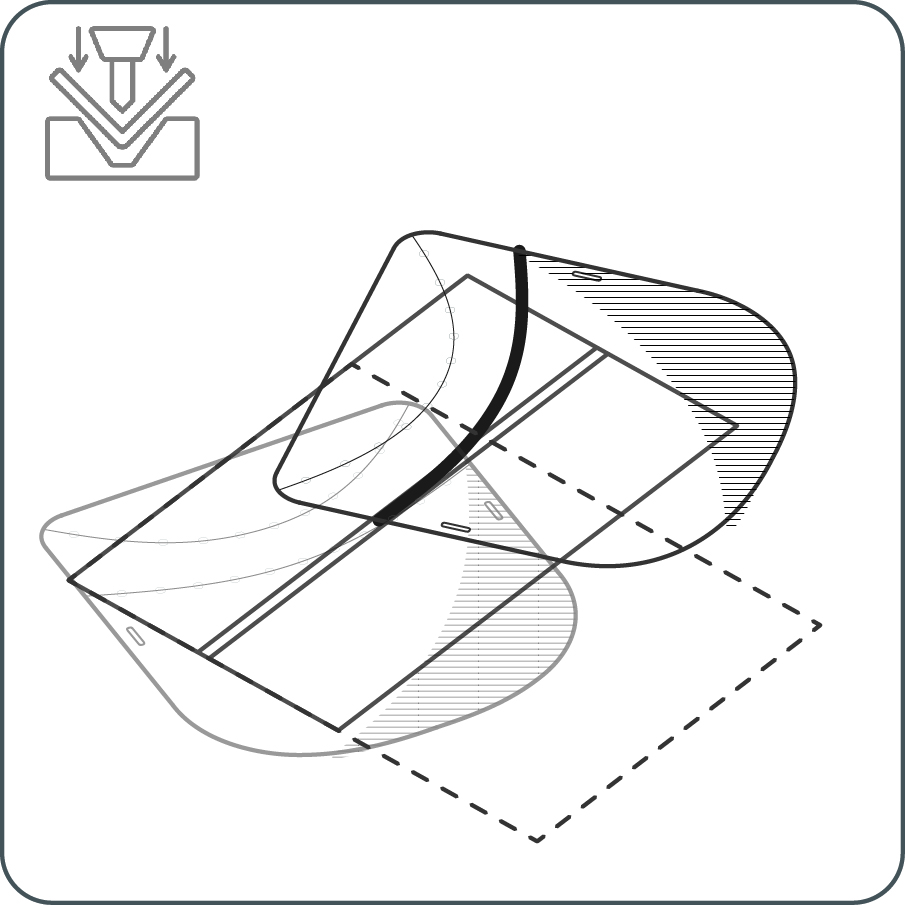
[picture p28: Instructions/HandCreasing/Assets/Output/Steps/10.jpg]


Find a 2-5 mm wide 2-3 mm deep channel at least 5 cm long on an immobile work surface or workpiece. Gaps between floorboards, segments of a dining table or kitchen countertop work well for this. Alternatively, make your own channel in a piece of wood or other material. Next, find a ballpoint pen or any other tool with a relatively dull end (any dull part of a butter knife, spoon, or chopstick can work here as well). 

Using one hand to move the sheet as you might a piece of fabric through a sewing machine, use the other hand to repeatedly run the tool over the surface of the material over the channel, following one of the crease curves you have traced.

---

# 7B

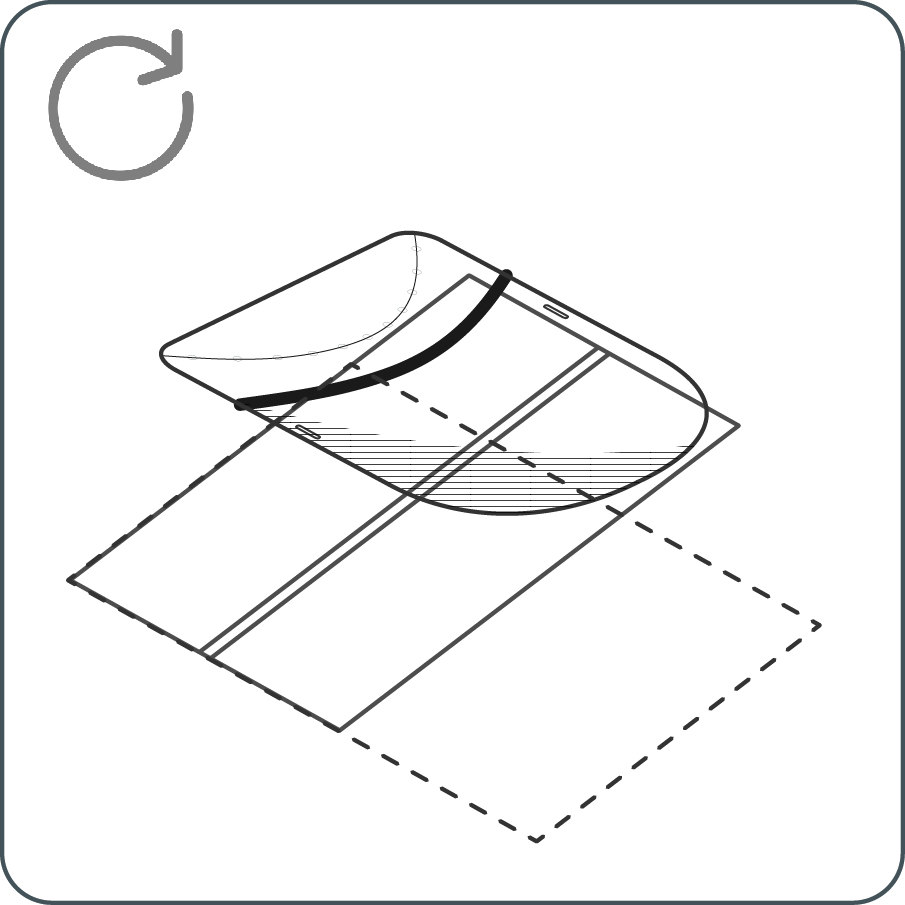
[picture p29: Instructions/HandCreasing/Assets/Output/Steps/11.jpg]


Flip the shield over.

---

# 8B

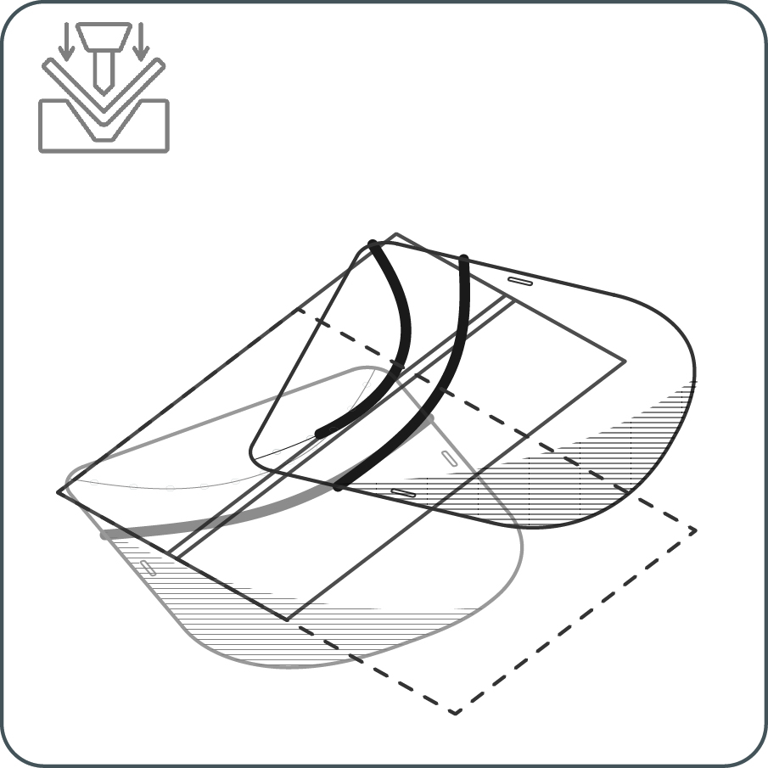
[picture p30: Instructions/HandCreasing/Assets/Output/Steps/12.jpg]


Repeat step 6B for the other crease curve.

---

# 9

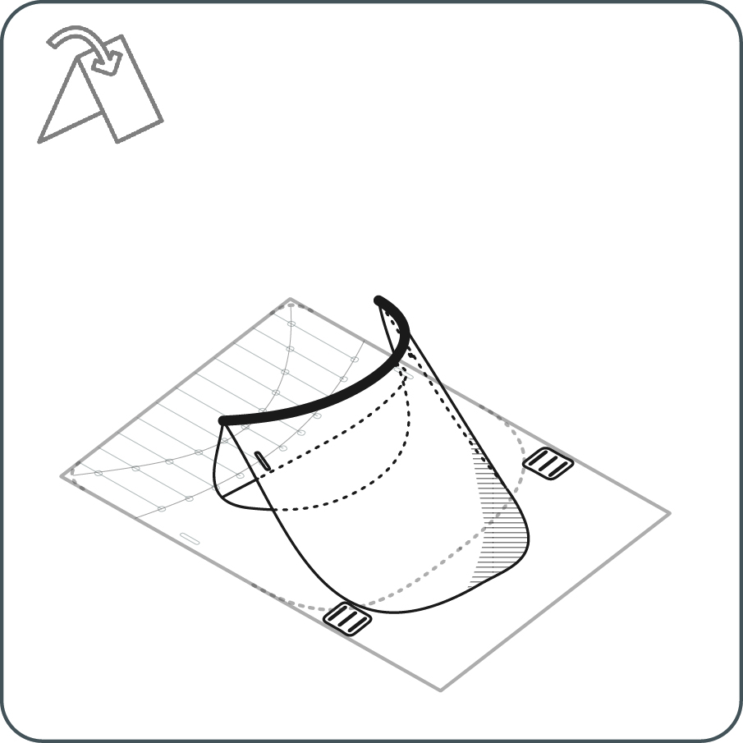
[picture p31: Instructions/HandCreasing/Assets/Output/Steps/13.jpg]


Starting on end of the crease curve, and working your way to the other end of the curve, gently pinch the sheet to fold it along the curve. If some segments do not fold easily, repeat the creasing procedure. 

---

# 10

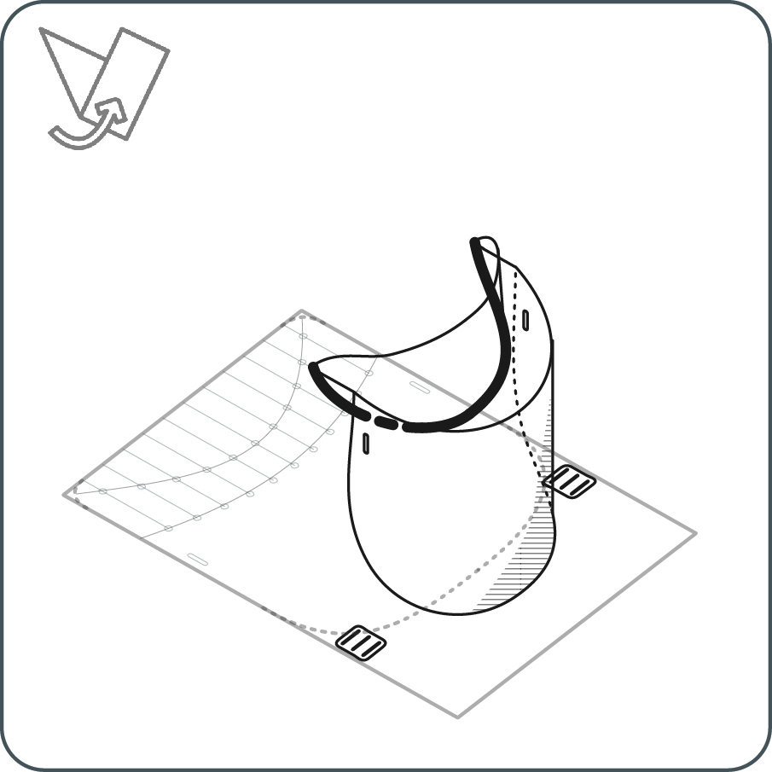
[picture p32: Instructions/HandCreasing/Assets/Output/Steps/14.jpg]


Repeat step 9 for the other curve, but this time, fold the sheet in the other direction. 

---

# 11	

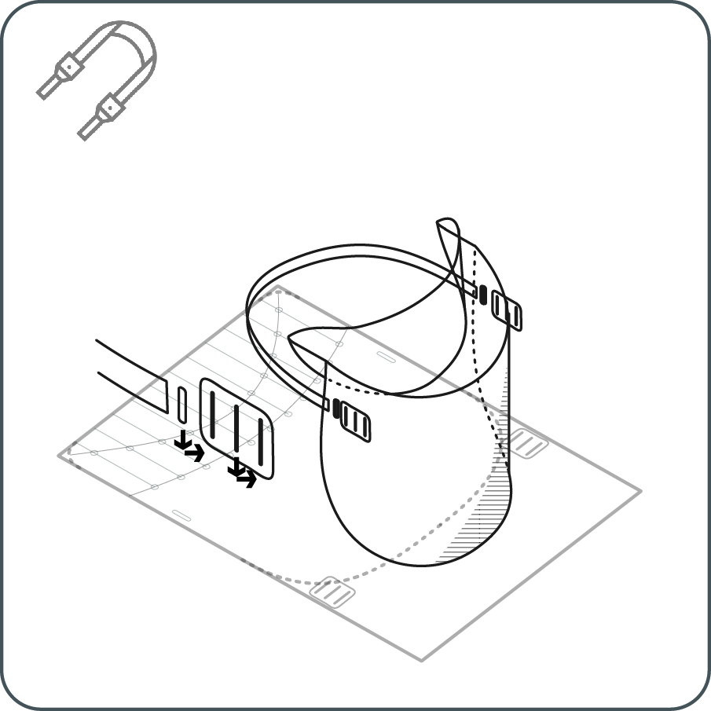
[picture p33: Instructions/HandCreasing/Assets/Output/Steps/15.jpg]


Thread the strap through the friction clips. Pass the friction clips through the holes in the shield from the back side of the shield to the front.

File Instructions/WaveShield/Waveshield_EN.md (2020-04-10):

---
layout: page
title: WaveSHIELD
tagline: &nbsp <span class="instructionsTaglineEmojiLinks"> <a href = "https://github.com/HappyShield/HappyShield/tree/master/Templates/Waveshield" ><i class="em em-triangular_ruler" aria-role="presentation" aria-label="TRIANGULAR RULER"></i></a></span>
permalink: /wave-shield/en/
language: en
---

<i class="em em-timer_clock" aria-role="presentation" aria-label=""></i>: 10-15′

---

<script src="https://snapwidget.com/js/snapwidget.js"></script>
<iframe src="https://snapwidget.com/embed/812110" class="snapwidget-widget" allowtransparency="true" frameborder="0" scrolling="no" style="border:none; overflow:hidden;  width:100%; "></iframe>

---

---

## Disclaimer

---

The University of Cambridge (UC) and the University of Queensland (UQ) make no warranty of any kind, express or implied, about the design, characteristics, durability, proper use or performance of the HappyShield, including but not limited to implied warranties of merchantability and fitness for any particular purpose. The HappyShield is designed to minimise exposure to fluids and sprays, but UC and UQ do not warrant that HappyShield will protect users from COVID-19 infection or any other infectious disease. Nothing in this material constitutes medical advice, and users should seek their own medical advice about whether HappyShield is suitable for the use they intend, and whether they should use it in conjunction with any other medical or other strategies. To the fullest extent allowed by law, UC and UQ exclude all implied warranties, guarantees, terms and conditions. UC and UQ are not liable for any claims, demands, damages or injuries, including but not limited to property damage, bodily injury or illness, death, indirect, special or consequential damages (“the Claims”) arising out of using the HappyShield, and users of HappyShield release UC and UQ and their officers, employees, contractors and agents from all Claims.

---

--- 

## Tools

---

* Scissors or razor blade
* Ballpoint pen

---

## Materials

---

**Shield**

* 0.5 mm thick Polyethylene terephthalate (PET) or Acetate sheet at least 
* 20 mm wide knit elastic strap (70% polyester 30% rubber)
* Tape

---

---

# Instructions

---

# 1 

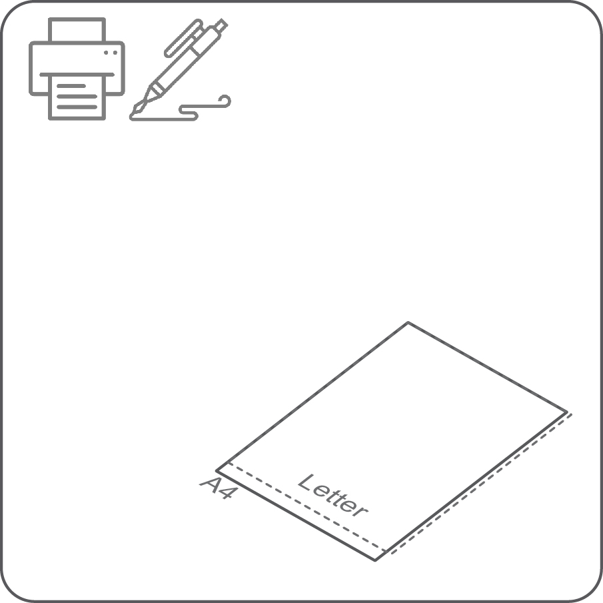
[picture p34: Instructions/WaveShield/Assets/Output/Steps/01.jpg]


Download your tracing template format (A4 for A3 shields, Letter for Tabloid shields). If you do not have access to printers, you can draw your own template. Our tracing templates have dimensions!

---

# 2

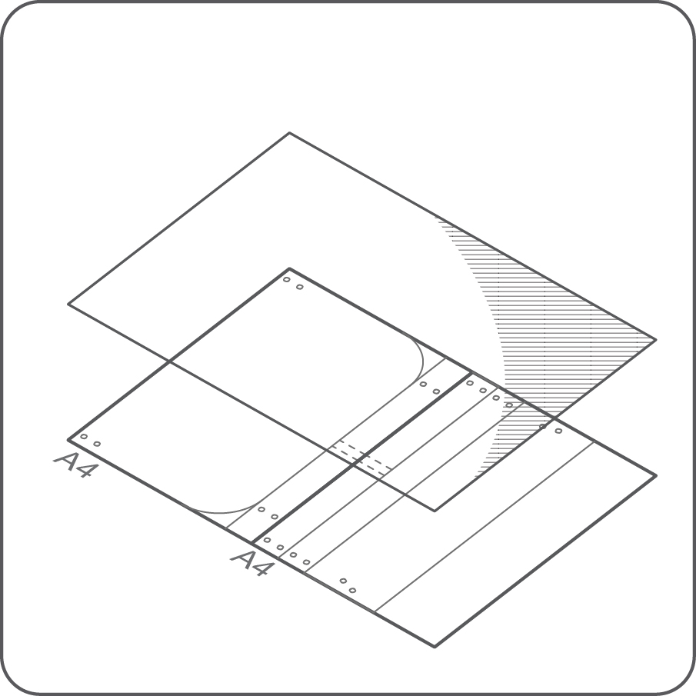
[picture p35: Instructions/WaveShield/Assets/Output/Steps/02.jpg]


Place your transparent sheet on the template. 

---

# 3

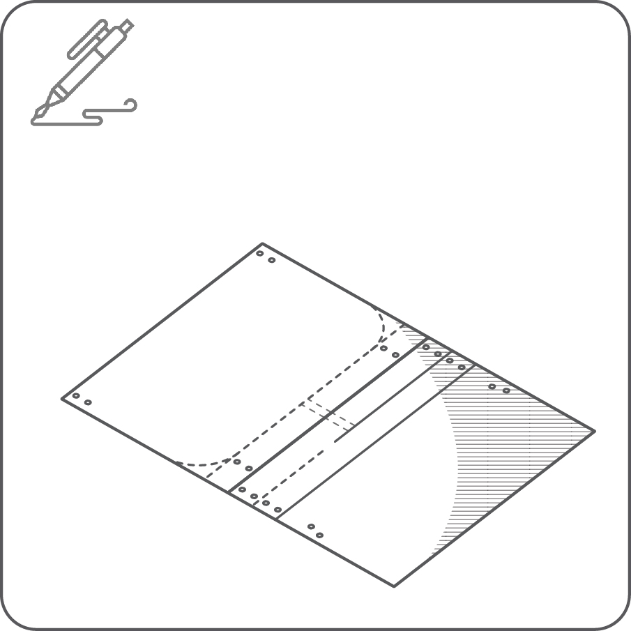
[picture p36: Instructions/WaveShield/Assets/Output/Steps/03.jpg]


Mark the holes’ location with a ballpoint pen. Don’t worry about the ink, it can be removed with a cloth damped with alcohol. Mark the lines and the lower round corners for cutting. 

---

# 4

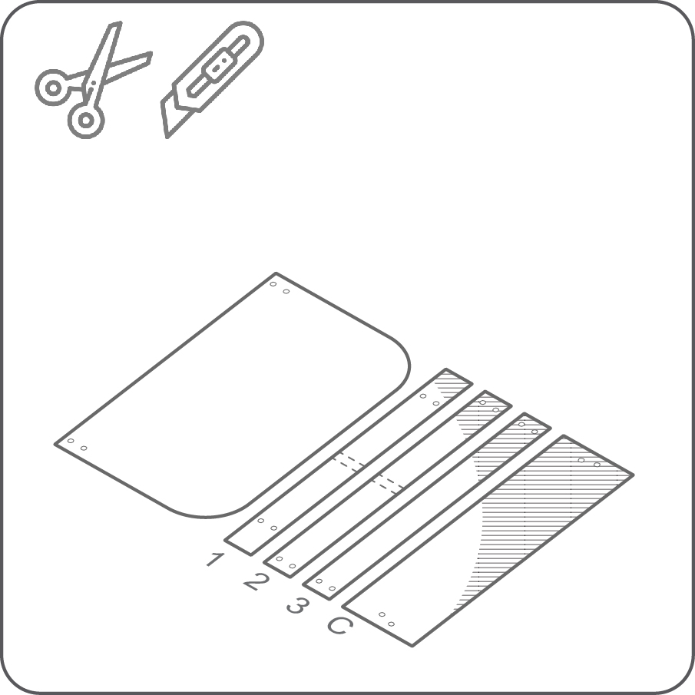
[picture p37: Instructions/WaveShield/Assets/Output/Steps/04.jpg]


With scissors or a cutter cut the sheets and trim the corners of the shield.

---

# 5

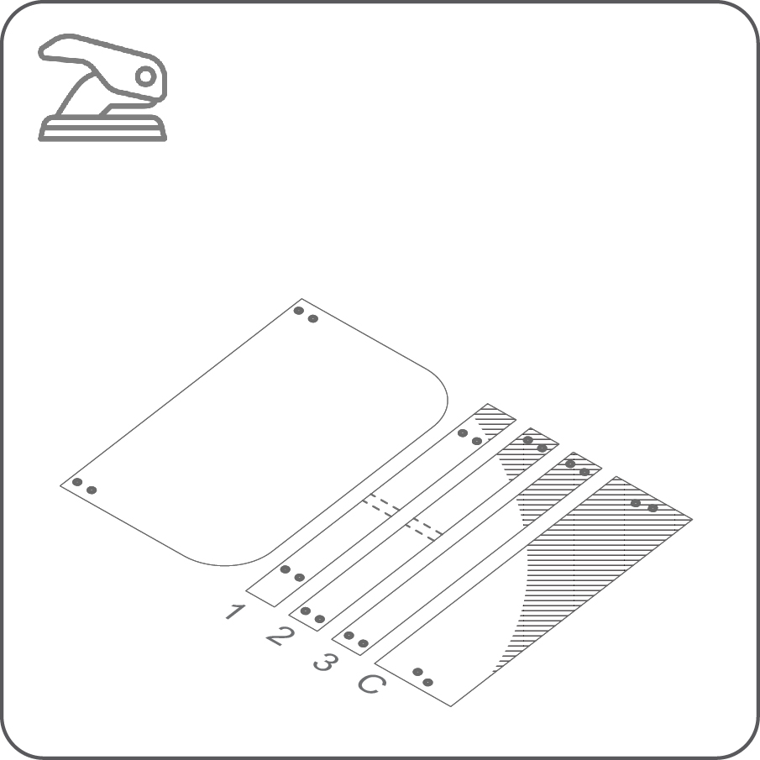
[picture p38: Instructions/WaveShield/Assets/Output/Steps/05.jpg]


Cut the holes. You can use a paper or leather punch¬er if you have.

---

# 6

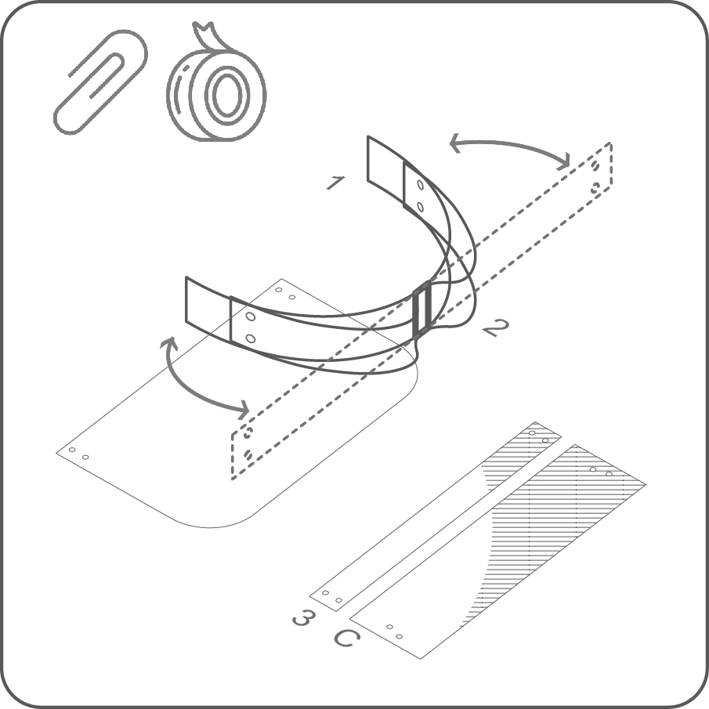
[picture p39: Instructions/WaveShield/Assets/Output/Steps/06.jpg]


Tape the middle of strip 1 and 2, check the M shape the two strips made when the holes are aligned. It should be symmetrical.

---

# 7

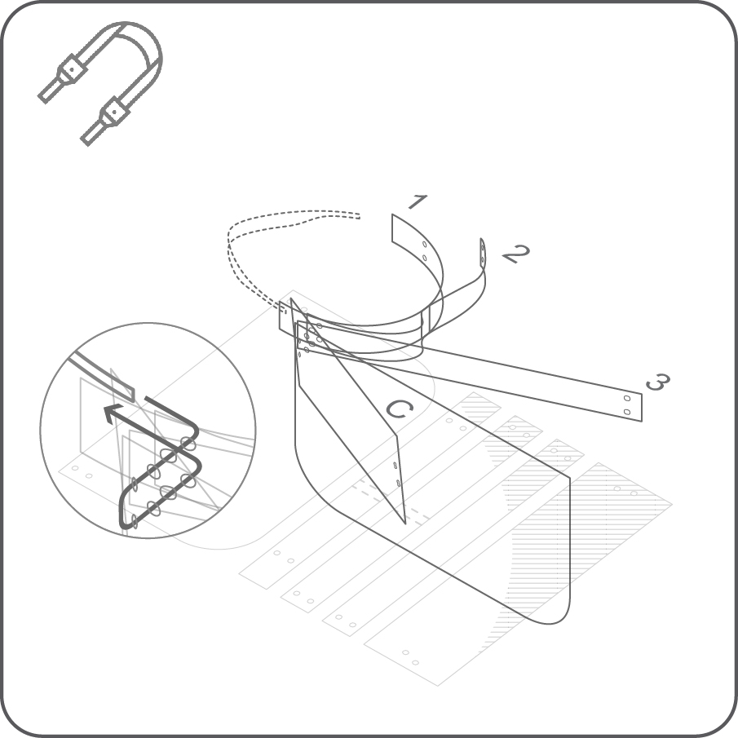
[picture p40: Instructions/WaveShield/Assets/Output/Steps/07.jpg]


Align the holes together strips. The order from inside to outside is: 1,2,3, face-shield, and top cover. Tie the sheets with the elastic band. It should come out from upper hole and go in the lower hole.

---

# 8

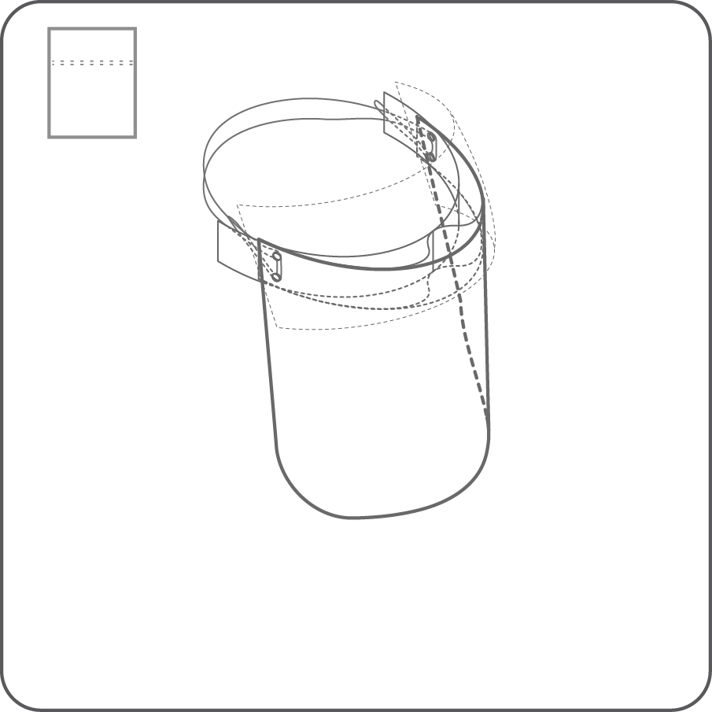
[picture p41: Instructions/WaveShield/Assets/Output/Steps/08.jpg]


Your mask is ready now.

---

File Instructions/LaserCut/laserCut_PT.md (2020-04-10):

---
layout: page
title: Corte a Laser
tagline: &nbsp <span class="instructionsTaglineEmojiLinks"><a href = "https://github.com/HappyShield/HappyShield/tree/master/Templates/LaserCut" ><i class="em em-triangular_ruler" aria-role="presentation" aria-label="TRIANGULAR RULER"></i></a></span>
permalink: /laser-cut/pt/
language: pt
---

<script src="https://snapwidget.com/js/snapwidget.js"></script>
<iframe src="https://snapwidget.com/embed/811086" class="snapwidget-widget" allowtransparency="true" frameborder="0" scrolling="no" style="border:none; overflow:hidden;  width:100%; "></iframe>

---

## Aviso Legal (Disclaimer)

---

The University of Cambridge (UC) and the University of Queensland (UQ) make no warranty of any kind, express or implied, about the design, characteristics, durability, proper use or performance of the HappyShield, including but not limited to implied warranties of merchantability and fitness for any particular purpose. The HappyShield is designed to minimise exposure to fluids and sprays, but UC and UQ do not warrant that HappyShield will protect users from COVID-19 infection or any other infectious disease. Nothing in this material constitutes medical advice, and users should seek their own medical advice about whether HappyShield is suitable for the use they intend, and whether they should use it in conjunction with any other medical or other strategies. To the fullest extent allowed by law, UC and UQ exclude all implied warranties, guarantees, terms and conditions. UC and UQ are not liable for any claims, demands, damages or injuries, including but not limited to property damage, bodily injury or illness, death, indirect, special or consequential damages (“the Claims”) arising out of using the HappyShield, and users of HappyShield release UC and UQ and their officers, employees, contractors and agents from all Claims.

---

--- 

## Ferramentas

---

* Cortador a laser
* Tesoura ou lâmina de corte

---

## Materiais

---

**Viseira**

* Polietileno tereftalato (PET) com 0,5 mm de espessura ou como alternativa uma folha de acetato 
* Fita elástica larga de 20 mm (70% poliéster 30% borracha)

---

---

# Instruções

---

# 1



Corte a laser a folha de plástico transparente usando o modelo, assegurando que as configurações do cortador a laser proporcionam a potência e velocidade necessárias para cortar o material na totalidade da sua espessura.

---

# 2	



Começando numa ponta da curva dobrável, e lentamente até à outra ponta, aperte gentilmente a folha para a dobrar ao longo da curva. 

--- 

# 3 	



Dobre a segunda curva usando o mesmo procedimento que no passo 2.

---

# 4	



Passe o elástico pelos clipes de fricção. Passe os clipes de fricção pelos orifícios na viseira de trás para a frente.

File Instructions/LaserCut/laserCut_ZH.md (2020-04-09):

---
layout: page
title: Laser-Cut 
tagline: &nbsp <span class="instructionsTaglineEmojiLinks"><a href = "https://github.com/HappyShield/HappyShield/tree/master/Templates/LaserCut" ><i class="em em-triangular_ruler" aria-role="presentation" aria-label="TRIANGULAR RULER"></i></a></span>
permalink: /laser-cut/zh/
language: zh
---

<script src="https://snapwidget.com/js/snapwidget.js"></script>
<iframe src="https://snapwidget.com/embed/811086" class="snapwidget-widget" allowtransparency="true" frameborder="0" scrolling="no" style="border:none; overflow:hidden;  width:100%; "></iframe>

---

## 免责声明（Disclaimer）

---

The University of Cambridge (UC) and the University of Queensland (UQ) make no warranty of any kind, express or implied, about the design, characteristics, durability, proper use or performance of the HappyShield, including but not limited to implied warranties of merchantability and fitness for any particular purpose. The HappyShield is designed to minimise exposure to fluids and sprays, but UC and UQ do not warrant that HappyShield will protect users from COVID-19 infection or any other infectious disease. Nothing in this material constitutes medical advice, and users should seek their own medical advice about whether HappyShield is suitable for the use they intend, and whether they should use it in conjunction with any other medical or other strategies. To the fullest extent allowed by law, UC and UQ exclude all implied warranties, guarantees, terms and conditions. UC and UQ are not liable for any claims, demands, damages or injuries, including but not limited to property damage, bodily injury or illness, death, indirect, special or consequential damages (“the Claims”) arising out of using the HappyShield, and users of HappyShield release UC and UQ and their officers, employees, contractors and agents from all Claims.

---

--- 

## 工具

---

* 激光切割机
* 剪刀 或 刻刀

---

## 材料

---

**护罩**

* 0.5 毫米厚的PET聚酯塑片 或者至少是 醋酸纤维塑片 (Acetate sheet) 
* 20 毫米宽的针织松紧带(70%聚酯，30%橡胶)

---

---

# 制作步骤

---

# 1



按照模板文件激光切割透明塑片。注意调整激光切割机的功率和速度设定，确保其能够切穿整个塑片材料。

---

# 2	



沿褶线从一边向另一边轻轻地捏折直到塑片完全弯折到一侧。

--- 

# 3 	



沿另外一条褶线重复步骤2，不过这次是将它向相反方向弯折。

---

# 4	



将松紧带与两个防滑固定夹连接。将连接好的防滑夹从护罩带孔向前穿出。

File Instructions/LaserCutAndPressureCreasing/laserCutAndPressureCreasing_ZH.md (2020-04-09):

---
layout: page
title: Laser-cut and Pressure Creasing
tagline: &nbsp <span class="instructionsTaglineEmojiLinks"> <a href = "https://youtu.be/IPKiPi-Tne8"><i class="em em-video_camera" aria-role="presentation" aria-label="VIDEO CAMERA"></i></a> <a href = "https://github.com/HappyShield/HappyShield/tree/master/Templates/LaserCutAndPressureCreasing" ><i class="em em-triangular_ruler" aria-role="presentation" aria-label="TRIANGULAR RULER"></i></a></span>
permalink: /pressure-creasing/zh/
language: zh
---

<script src="https://snapwidget.com/js/snapwidget.js"></script>
<iframe src="https://snapwidget.com/embed/810066" class="snapwidget-widget" allowtransparency="true" frameborder="0" scrolling="no" style="border:none; overflow:hidden;  width:100%; "></iframe>

---

## 免责声明（Disclaimer）

---

The University of Cambridge (UC) and the University of Queensland (UQ) make no warranty of any kind, express or implied, about the design, characteristics, durability, proper use or performance of the HappyShield, including but not limited to implied warranties of merchantability and fitness for any particular purpose. The HappyShield is designed to minimise exposure to fluids and sprays, but UC and UQ do not warrant that HappyShield will protect users from COVID-19 infection or any other infectious disease. Nothing in this material constitutes medical advice, and users should seek their own medical advice about whether HappyShield is suitable for the use they intend, and whether they should use it in conjunction with any other medical or other strategies. To the fullest extent allowed by law, UC and UQ exclude all implied warranties, guarantees, terms and conditions. UC and UQ are not liable for any claims, demands, damages or injuries, including but not limited to property damage, bodily injury or illness, death, indirect, special or consequential damages (“the Claims”) arising out of using the HappyShield, and users of HappyShield release UC and UQ and their officers, employees, contractors and agents from all Claims.

---

--- 

## 工具

---

* 激光切割机
* 10吨压机
* 能够切割1毫米钢丝绳的钳子
* 剪刀 或 刻刀
* 钻头 或 螺丝刀

---

## 材料

---

**三件式冲压夹具**

* 4毫米 中密度纤维板（MDF）
* 1毫米 钢丝绳   
* 6-20毫米 木螺钉
* 透明胶带

**护罩**

* 0.5 毫米厚的PET聚酯塑片 或者至少是 醋酸纤维塑片 (Acetate sheet) 
* 20 毫米宽的针织松紧带(70%聚酯，30%橡胶)

---

---

# 制作步骤

---

## 三件式冲压夹具 

---

# 1 	



下载适用于您的激光切割机底座的三件式压模夹具的激光切割模板。（切割模板的尺寸显示在文件名中。）根据模板文件对MDF进行激光切割。

---

# 2



从激光切割机上卸下冲压夹具的3个部分。将钢丝绳切成模板A和C部分中虚线的长度。将金属线用胶带贴压力夹具A和C凹槽中的虚线上，确保不要偏离虚线，也不要超出虚线的两端。

---

# 3



用短木螺钉将B部分装到顶部A上。将组合起来的A和B部分连接到一个基板上，以保证压力均匀分配在夹具表面上。对C部分执行相同的操作。

--- 

## 护罩

---

# 1



下载适合您激光切割机床身的HappyShield激光切割模板。 （切割模板的尺寸显示在文件名中。）

---

# 2	



按照模板文件激光切割透明塑片。注意调整激光切割机的功率和速度设定，确保其能够切穿整个塑片材料。

切割后，从激光切割机上卸下得到的防护罩和防滑夹。如果需要，用酒精擦拭护罩和夹子的边缘，或用任何肥皂清洗，以除去塑片上的激光切割残留物。

--- 

# 3



将塑片插入三件式冲压夹具中，按压形成弯曲的褶痕。
Insert shield into the 3-part press jig and press to create the curved creases.

---

# 4	



切下400毫米长的松紧带。将穿过两端的摩擦夹。将松紧带两边与两个防滑固定夹连接。

---

# 5	



将连接好的防滑夹从护罩带孔向前穿出。

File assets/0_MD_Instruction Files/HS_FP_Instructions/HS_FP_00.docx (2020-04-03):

1. Download the laser-cutting template for the shield that fits in the bed of your laser-cutting machine – dimensions are described in the file names! Use a flexible transparent material.
2. Wipe the edges of the shields and clips with alcohol.
3. Download the laser-cutting template for the 3-part press jig according to the bed-size of your laser-cutting machine – dimensions are described in the file names! Use a hard material, such as mdf or plywood.
4. Tape the metal wire along the groove of the parts A and C of the press jig.
5. Attach part A on the bottom surface of the press and place the transparent shield on it, using the band slots for alignment. Interlock parts B+C and attach them on the top surface of the press. Use the slots again to make sure it is aligned to part A!
6. Press the shield between the 3-part press jig to create the curved creases.
7. Fix the strap using the laser-cut clips.
8. Insert the clips in the slots of the curved shield.

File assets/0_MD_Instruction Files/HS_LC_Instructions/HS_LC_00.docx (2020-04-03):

1. Download and use our laser cutting template. Place the plastic sheet and laser cut. The mask cutting area is 297x320mm, You can use A3 sheets if large plastic sheets are not available.
2. To fold the first curve, start with one corner, if some segments does not fold, score again with a pen and ruler.
3. Fold the second curve.
4. Fix the strap using the holders you cut from the template. Clean and use or clean and place in a ziploc bag for shipping.

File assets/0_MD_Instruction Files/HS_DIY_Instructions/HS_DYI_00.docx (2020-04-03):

1. Download your tracing template format (A4 for A3 shields, Letter for Tabloid shields). If you do not have access to printers, you can draw your own template. Our tracing templates have dimensions!
2. Place your transparent sheet on the template. Mark the holes’ location with a ballpoint pen. Don’t worry about the ink, it can be removed with a cloth damped with alcohol.
3. Mark the strap holders and the lower and upper round corners for cutting.
4. With scissors or a cutter trim the corners. Cut the strap holders and make the holes, you can use a paper puncher if you have. Now, let’s score a smile on that face!

SCORING OPTION 1

5. Place your transparent sheet on the template. Fix with clips or tape for precise tracing.
6. With a ruler and the ballpoint pen, trace the straight segments of the first curve with multiple strokes until scored.
7. Flip the transparent sheet. Fix the sheet and the template again
8. Trace the second curve with the ruler and the pen

SCORING OPTION 2

9. Trace the folding curves with a pen
10. Make a 2-5 mm gap in a wooden piece. You can also use the gaps between floorboards, kitchen top, dining table. Use the gap as a channel and crease with the dull side of a butter knife.
11. Flip the mask
12. Do the second curve on the other side.
13. To fold the first curve, start with one corner, if some segments does not fold, score again with the pen and ruler.
14. Fold the second curve.
15. Fix the strap using the holders you cut from the template.
16. Clean and use, clean and place in zip bag for shipping

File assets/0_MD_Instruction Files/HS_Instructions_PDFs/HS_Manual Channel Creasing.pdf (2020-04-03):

# HAPPYSHIELD

## Manual Channel Creasing

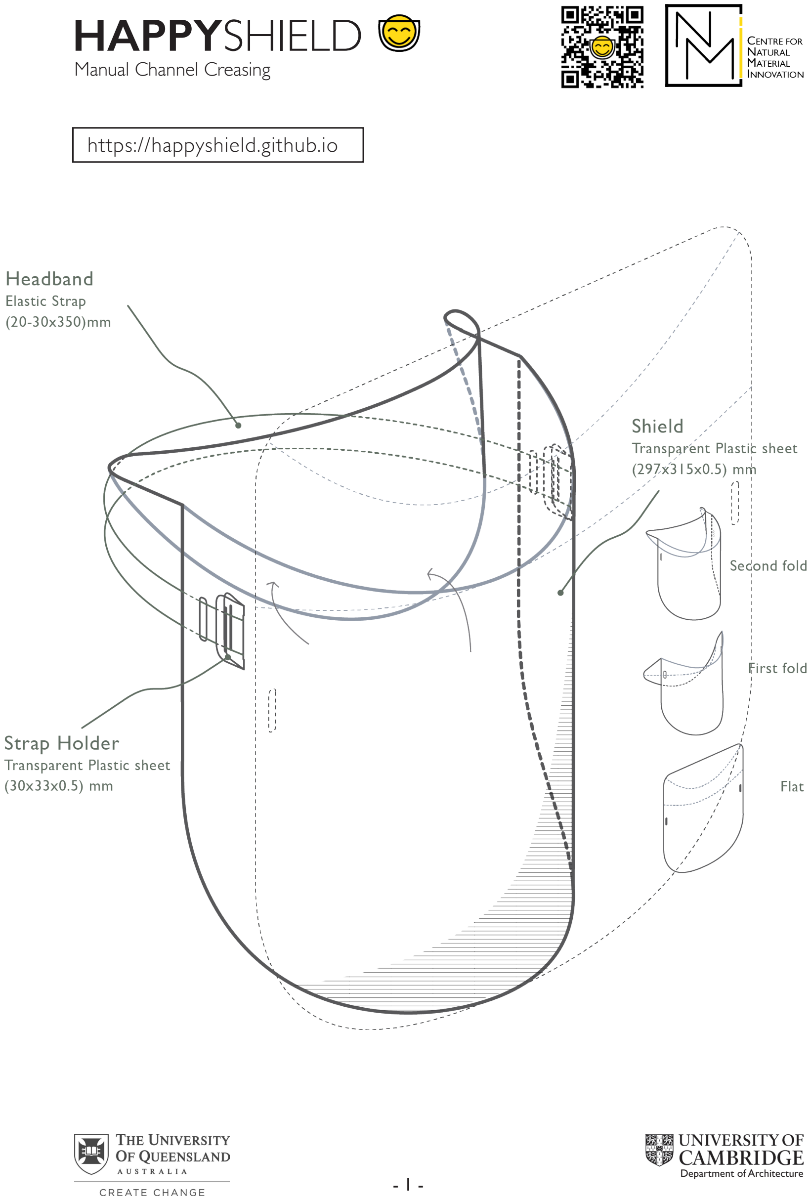
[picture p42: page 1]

Department of Architecture
- 1 -

# https://happyshield.github.io

# HAPPYSHIELD

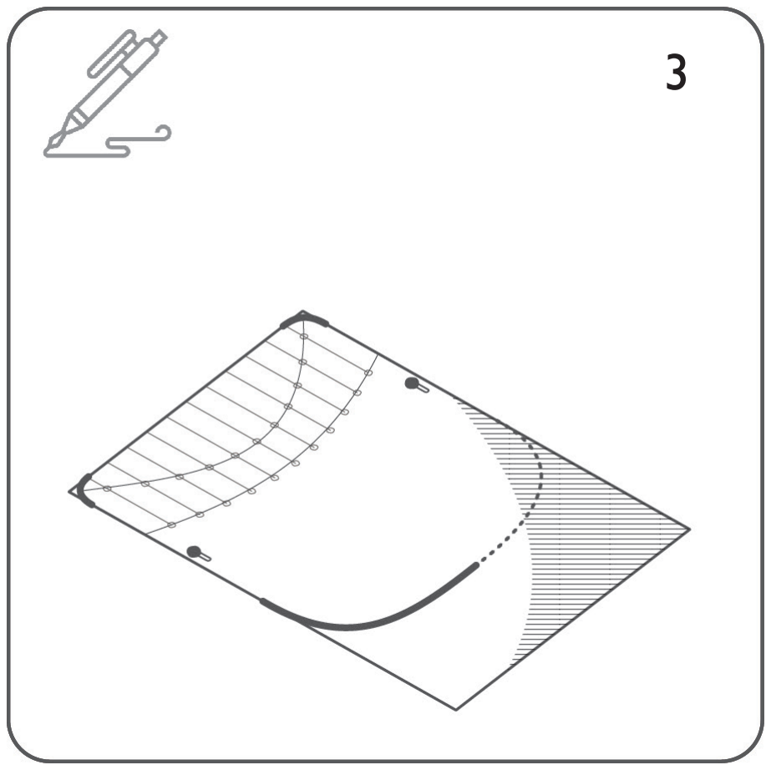
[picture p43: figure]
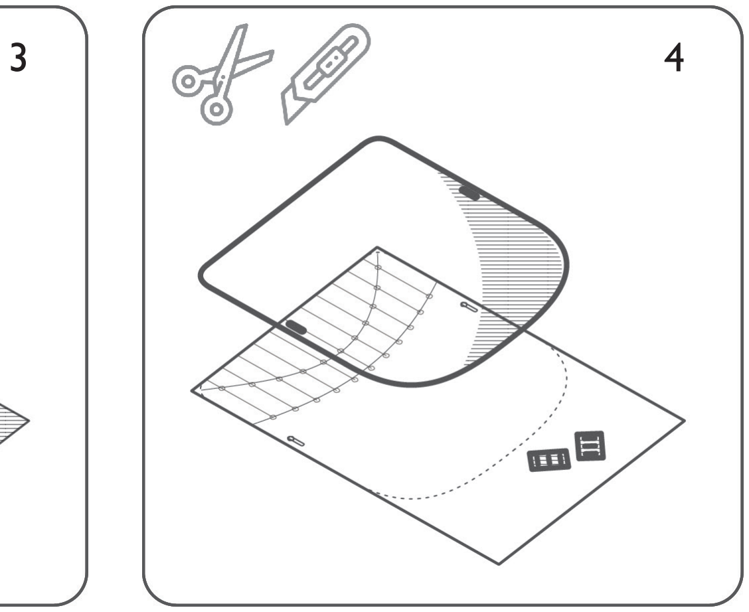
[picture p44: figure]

- 2 -

## Manual Channel Creasing

# https://happyshield.github.io

Download your tracing template format (A4 for A3 shields, Letter for Tabloid shields). If you do not have access to printers, you can draw your own template. Our tracing templates have dimensions!

Mark the strap holders and the lower and upper round corners for cutting.

Place your transparent sheet on the template. Mark the holes’ location with a ballpoint pen. Don’t worry about the ink, it can be removed with a cloth damped with alcohol.

With scissors or a cutter trim the corners. Cut the strap holders and make the holes. You can use a paper puncher if you have.

Now, let’s score a smile on that face!

1 | 2

# HAPPYSHIELD

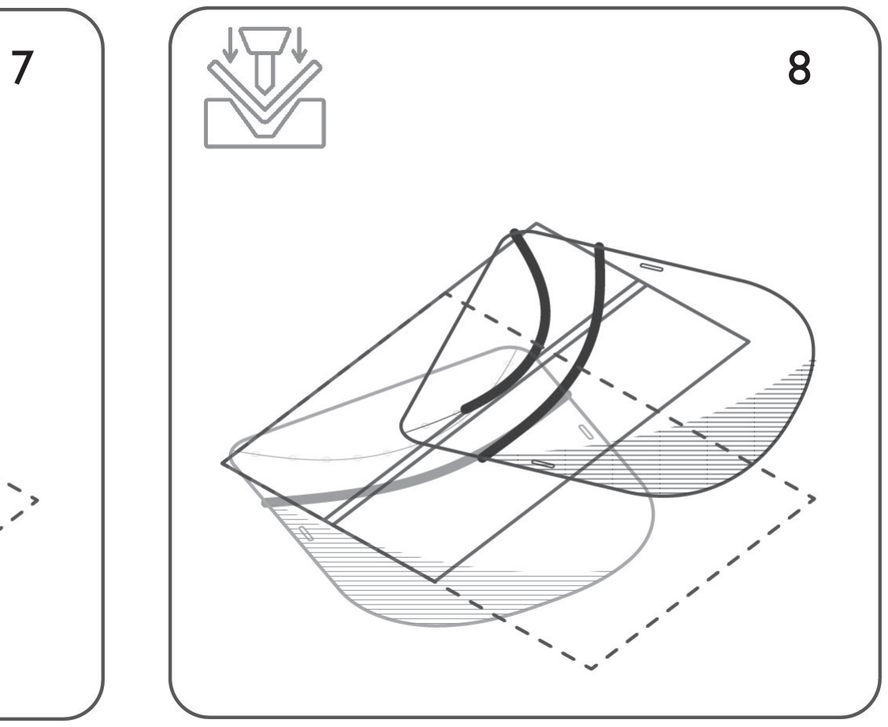
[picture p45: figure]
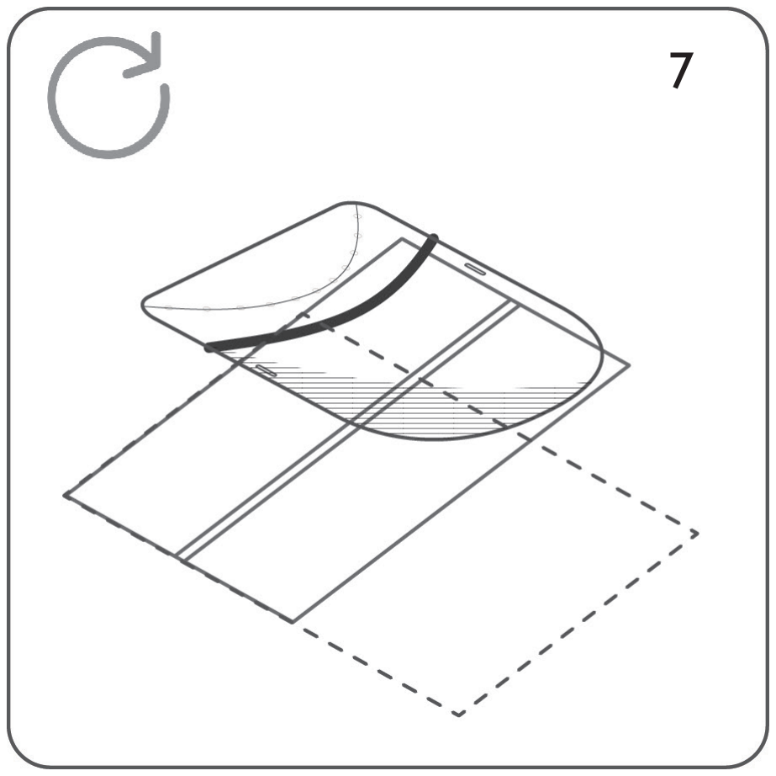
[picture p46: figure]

- 3 -

## Manual Channel Creasing

# https://happyshield.github.io

Trace the folding curves with a pen

Flip the mask

Make a 2-5 mm gap in a wooden piece. You can also use the gaps between floorboards, kitchen top, dining table. Use the gap as a channel and crease with the dull side of a butter knife.

Do the second curve on the other side

5 | 6

# HAPPYSHIELD


- 4 -

## Manual Channel Creasing

# https://happyshield.github.io

To fold the first curve, start with one corner, if some segments do not fold, score again with the pen and ruler.

Fix the strap using the holders you cut from the template.

Fold the second curve.

Clean and use. Clean and place in zip bag for shipping

9 | 10

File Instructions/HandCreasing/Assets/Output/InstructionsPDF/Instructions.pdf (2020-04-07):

# HAPPYSHIELD

Materials:; Acetate sheet at least; Tape; Tools: Pen Printer Ruler Scissors or cutter; Disclaimer:

- 1 -

# Hand Creasing

## https://happyshield.github.io

## 0.5 mm thick Polyethylene terephthalate (PET) or 20 mm wide Knit elastic strap (70% polyester 30% rubber)

The University of Cambridge (UC) and the University of Queensland (UQ) make no warranty of any kind, express or implied, about the design, characteristics, durability, proper use or performance of the HappyShield, including but not limited to implied warranties of merchantability and fitness for any particular purpose. The HappyShield is designed to minimise exposure to fluids and sprays, but UC and UQ do not warrant that HappyShield will protect users from COVID-19 infection or any other infectious disease. Nothing in this material constitutes medical advice, and users should seek their own medical advice about whether HappyShield is suitable for the use they intend, and whether they should use it in conjunction with any other medical or other strategies. To the fullest extent allowed by law, UC and UQ exclude all implied warranties, guarantees, terms and conditions. UC and UQ are not liable for any claims, demands, damages or injuries, including but not limited to property damage, bodily injury or illness, death, indirect, special or consequential damages (“the Claims”) arising out of using the HappyShield, and users of HappyShield release UC and UQ and their officers, employees, contractors and agents from all Claims.

This document is current as of 2020 04 07 13:00. Please refer to the latest version of the documentation at happyshield.github.io.

# HAPPYSHIELD


- 2 -

# Hand Creasing

## https://happyshield.github.io

Download your tracing template. A4-sized templates are available for A3-sized shields. Letter-sized templates are available for Tabloid-sized shields. If you do not have access to a printer, you can draw your own template using the dimensions shown on the template.

Trace out the boundary of the shield for cutting out.

Place your transparent sheet on the template. Mark the location of the strap holes with your pen or marker. Don’t worry about the ink, it can be removed with a cloth damped with alcohol.

Cut the boundary shape of the shield out using scissors or a razor blade. Cut out the strap holes. You can use a hole-puncher as well to make these holes. Next, cut out the friction clips using a razor blade. Now, let’s score a smile on that face!

# HAPPYSHIELD

# Hand Creasing


- 3 -

## https://happyshield.github.io

Place your transparent sheet on the template. Fix with clips or tape for precise tracing.

Flip the transparent sheet. Fix the sheet and the template again.

Using a ruler, and applying pressure, trace the straight segments between each consecutive point, using 2-3 strokes as needed until you see a visible indentation in the sheet.

Trace the second curve in the same way as in step 6A.

5A | 6A
7A | 8A

## CREASING METHOD A With pen and a ruller

# HAPPYSHIELD


- 4 -

# Hand Creasing

## https://happyshield.github.io

Trace the folding curves with a pen (no additional pressure is required here). If desired, fix the sheet to the template with clips or tape for more precise tracing.

Flip the shield over.

Find a 2-5 mm wide 2-3 mm deep channel at least 5 cm long on an immobile work surface or workpiece. Gaps between floorboards, segments of a dining table or kitchen countertop work well for this. Alternatively, make your own channel in a piece of wood or other material. Next, find a ballpoint pen or any other tool with a relatively dull end (any dull part of a butter knife, spoon, or chopstick can work here as well).
Using one hand to move the sheet as you might a piece of fabric through a sewing machine, use the other hand to repeatedly run the tool over the surface of the material over the channel, following one of the crease curves you have traced.

Repeat step 6B for the other crease curve.

## CREASING METHOD B With channel

# HAPPYSHIELD


- 5 -

# Hand Creasing

## https://happyshield.github.io

Starting on end of the crease curve, and working your way to the other end of the curve, gently pinch the sheet to fold it along the curve. If some segments do not fold easily, repeat the creasing procedure.

Thread the strap through the friction clips. Pass the friction clips through the holes in the shield from the back side of the shield to the front.

Repeat step 9 for the other curve, but this time, fold the sheet in the other direction.

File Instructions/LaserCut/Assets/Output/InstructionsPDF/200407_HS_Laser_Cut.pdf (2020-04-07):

# HAPPYSHIELD

Materials:; Acetate sheet at least; Tools: Laser-cutter Scissors or razor blade; Disclaimer:

- 1 -

## Laser-Cut

## https://happyshield.github.io

### 0.5 mm thick Polyethylene terephthalate (PET) or 20 mm wide knit elastic strap (70% polyester 30% rubber)

The University of Cambridge (UC) and the University of Queensland (UQ) make no warranty of any kind, express or implied, about the design, characteristics, durability, proper use or performance of the HappyShield, including but not limited to implied warranties of merchantability and fitness for any particular purpose. The HappyShield is designed to minimise exposure to fluids and sprays, but UC and UQ do not warrant that HappyShield will protect users from COVID-19 infection or any other infectious disease. Nothing in this material constitutes medical advice, and users should seek their own medical advice about whether HappyShield is suitable for the use they intend, and whether they should use it in conjunction with any other medical or other strategies. To the fullest extent allowed by law, UC and UQ exclude all implied warranties, guarantees, terms and conditions. UC and UQ are not liable for any claims, demands, damages or injuries, including but not limited to property damage, bodily injury or illness, death, indirect, special or consequential damages (“the Claims”) arising out of using the HappyShield, and users of HappyShield release UC and UQ and their officers, employees, contractors and agents from all Claims.

This document is current as of 2020 04 07 13:00. Please refer to the latest version of the documentation at happyshield.github.io.

# HAPPYSHIELD


- 2 -

## Laser-Cut

## https://happyshield.github.io

Laser-cut the clear plastic sheet material using the template file, ensuring that your laser-cutter power and speed settings ensure a cut completely through the depth of the material.

Fold the second curve using the same procedure as in
Step 2.

Starting on end of one of the crease curves, and working your way to the other end of the curve, gently pinch the sheet to fold it along the curve.

Thread the strap through the friction clips. Pass the friction clips through the holes in the shield from the back side of the shield to the front.

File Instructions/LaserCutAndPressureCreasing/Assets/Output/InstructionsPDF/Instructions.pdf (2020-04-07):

# HAPPYSHIELD

Materials: 3-Part Press Jig 4 mm MDF 1 mm steel wire rope 6-20 mm wood screws Clear plastic tape Shield; Tools: Laser-cutter 10-tonne press Pliers capable of cutting 1 mm steel wire rope Scissors or razor blade Drill or screw-driver; Disclaimer:

- 1 -

# Laser-cut and Pressure Creasing

## https://happyshield.github.io

## 0.5 mm thick Polyethylene terephthalate (PET) or Acetate sheet 20 mm wide knit elastic strap (70% polyester 30% rubber)

The University of Cambridge (UC) and the University of Queensland (UQ) make no warranty of any kind, express or implied, about the design, characteristics, durability, proper use or performance of the HappyShield, including but not limited to implied warranties of merchantability and fitness for any particular purpose. The HappyShield is designed to minimise exposure to fluids and sprays, but UC and UQ do not warrant that HappyShield will protect users from COVID-19 infection or any other infectious disease. Nothing in this material constitutes medical advice, and users should seek their own medical advice about whether HappyShield is suitable for the use they intend, and whether they should use it in conjunction with any other medical or other strategies. To the fullest extent allowed by law, UC and UQ exclude all implied warranties, guarantees, terms and conditions. UC and UQ are not liable for any claims, demands, damages or injuries, including but not limited to property damage, bodily injury or illness, death, indirect, special or consequential damages (“the Claims”) arising out of using the HappyShield, and users of HappyShield release UC and UQ and their officers, employees, contractors and agents from all Claims.

This document is current as of 2020 04 07 13:00. Please refer to the latest version of the documentation at happyshield.github.io.

# HAPPYSHIELD


- 2 -

# Laser-cut and Pressure Creasing

## https://happyshield.github.io

Download the laser-cutting template for the 3-part press jig which fits the bed of your laser-cutting machine. (The dimensions of the cutting templates are given in the filenames.) Laser-cut the MDF using the template file.

Attach Part B to top A using short wood screws. Attach the combined Part A and B to a block as needed to distribute pressure evenly across the jig surface. Do the same for Part C.

Remove the 3 parts of the press jig from the la-ser-cutter. Cut the wire rope to the length of the dashed curves in parts A and C of the template. Tape the metal wire onto the dashed curve the groove of the parts A and C of the press jig, being sure not to deviate from the dashed curve, and not to extend beyond the ends of the dashed curve.

Download the HappyShield laser-cutting template which fits in the bed of your laser-cutting machine. (The dimensions of the cutting templates are given in the filenames.)

# 3-PART PRESS JIG

# SHIELD

# HAPPYSHIELD


- 3 -

# Laser-cut and Pressure Creasing

## https://happyshield.github.io

Laser-cut the clear plastic sheet material using the template file, ensuring that your laser-cutter power and speed settings ensure a cut completely through the depth of the material.

Once cut, remove the resulting shields and friction clips from the laser-cutter bed. If desired, wipe the edges of the shields and clips with alcohol, or wash with any soap to remove any laser-cutting residues from the sheet.

Cut a 400 mm length of elastic strap. Thread the strap through the friction clips on both ends.

Insert shield into the 3-part press jig and press to create the curved creases.

Pass the threaded friction clips through the holes in the shield from back to front.

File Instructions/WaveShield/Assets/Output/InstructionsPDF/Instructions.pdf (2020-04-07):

# WAVESHIELD


- 1 -

## DIY Shield

## https://happyshield.github.io

Disclaimer:
The University of Cambridge (UC) and the University of Queensland (UQ) make no warranty of any kind, express or implied, about the design, characteristics, durability, proper use or performance of the HappyShield, including but not limited to implied warranties of merchantability and fitness for any particular purpose. The HappyShield is designed to minimise exposure to fluids and sprays, but UC and UQ do not warrant that HappyShield will protect users from COVID-19 infection or any other infectious disease. Nothing in this material constitutes medical advice, and users should seek their own medical advice about whether HappyShield is suitable for the use they intend, and whether they should use it in conjunction with any other medical or other strategies. To the fullest extent allowed by law, UC and UQ exclude all implied warranties, guarantees, terms and conditions. UC and UQ are not liable for any claims, demands, damages or injuries, including but not limited to property damage, bodily injury or illness, death, indirect, special or consequential damages (“the Claims”) arising out of using the HappyShield, and users of HappyShield release UC and UQ and their officers, employees, contractors and agents from all Claims.

This document is current as of 2020 04 07 13:00. Please refer to the latest version of the documentation at happyshield.github.io.

# WAVESHIELD

## DIY Shield


- 2 -

## https://happyshield.github.io

Download your tracing template format (A4 for A3 shields, Letter for Tabloid shields). If you do not have access to printers, you can draw your own template. Our tracing templates have dimensions!

Mark the holes’ location with a ballpoint pen. Don’t worry about the ink, it can be removed with a cloth damped with alcohol. Mark the lines and the lower round corners for cutting.

Place your transparent sheet on the template.

With scissors or a cutter cut the sheets and trim the corners of the shield.

# WAVESHIELD

## DIY Shield


- 3 -

## https://happyshield.github.io

Cut the holes. You can use a paper or leather puncher if you have.

Align the holes together strips. The order from inside to outside is: 1,2,3, face-shield, and top cover. Tie the sheets with the elastic band. It should come out from upper hole and go in the lower hole.

Tape the middle of strip 1 and 2, check the M shape the two strips made when the holes are aligned. It should be symmetrical.

Clean and use. Clean and place in ziploc bag for shipping

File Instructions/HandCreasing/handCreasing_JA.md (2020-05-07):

---
layout: page
title: 手で折る方法
tagline: &nbsp <span class="instructionsTaglineEmojiLinks"> <a href="https://youtu.be/8RvlrtrebBE"><i class="em em-video_camera" aria-role="presentation" aria-label="VIDEO CAMERA"></i></a> <a href = "https://github.com/HappyShield/HappyShield/tree/master/Templates/HandCreasing" ><i class="em em-triangular_ruler" aria-role="presentation" aria-label="TRIANGULAR RULER"></i></a></span>
permalink: /hand-creasing/ja/
language: ja
---

<i class="em em-timer_clock" aria-role="presentation" aria-label=""></i>: 10-15′

---

<script src="https://snapwidget.com/js/snapwidget.js"></script>
<iframe src="https://snapwidget.com/embed/810064" class="snapwidget-widget" allowtransparency="true" frameborder="0" scrolling="no" style="border:none; overflow:hidden;  width:100%; "></iframe>

---

---

## 免責事項 (Disclaimer)

---

The University of Cambridge (UC) and the University of Queensland (UQ) make no warranty of any kind, express or implied, about the design, characteristics, durability, proper use or performance of the HappyShield, including but not limited to implied warranties of merchantability and fitness for any particular purpose. The HappyShield is designed to minimise exposure to fluids and sprays, but UC and UQ do not warrant that HappyShield will protect users from COVID-19 infection or any other infectious disease. Nothing in this material constitutes medical advice, and users should seek their own medical advice about whether HappyShield is suitable for the use they intend, and whether they should use it in conjunction with any other medical or other strategies. To the fullest extent allowed by law, UC and UQ exclude all implied warranties, guarantees, terms and conditions. UC and UQ are not liable for any claims, demands, damages or injuries, including but not limited to property damage, bodily injury or illness, death, indirect, special or consequential damages (“the Claims”) arising out of using the HappyShield, and users of HappyShield release UC and UQ and their officers, employees, contractors and agents from all Claims.

---

--- 

## ツール

---

* ハサミまたはカッター
* ボールペン
* 定規
* バターナイフ
* プリンター

---

## 材料

---

**シールド**

* 厚さ0.5 mmのPETまたはアセテートの板
* 幅20 mmのゴムバンド (70% ポリエステル 30% ゴム)
* 接着用のテープ

---

---

# 制作手順

---

# 1 



テンプレートをプラ板に書き写すために、まず紙にパターンを印刷します。はじめにテンプレートをダウンロードしましょう。A3サイズのシールドを作りたいときはA4のテンプレート、タブロイドサイズのシールドを作りたいときはレターサイズのテンプレートを使います（日本で作る場合はA4のテンプレートをおすすめします）。プリンターがなければ、テンプレートに記載された通りにパターンを手描きします。

---

# 2



透明なプラ板をパターンの描かれた紙の上に置きます。ストラップホールになる部分を油性マジックペンなどで塗っておきましょう。インクは後でアルコールで拭き取ることができます。

---

# 3



パターンをプラ板に書き写します。

---

# 4



ハサミかカッターを使い、書き写したパターンに沿ってシールドのふちを切り出していきます。また、ストラップホールも切り抜きます。切り抜き部分には穴あけパンチなどを使っても大丈夫です。

次に、バンドを固定するためのクリップをカッターで切り出します。

---

## 折り目をつける方法 (A)

---

# 5A



正確に折り目のパターンを書き写すために、切り出したプラバンをテンプレートの上に置き、クリップやテープで正確に固定します。
---

# 6A



まず、2つの線のうちどちらか1つに折り目をつけます。1つの折り線の中に点がたくさんあるので、点と点を定規で結んで、ボールペンなどを強く押し当てて折り目をつけましょう。はっきりとした折り線が見えるようになるまで、1つの折り目につき2,3回線を引くのがいいでしょう。

---

# 7A



シートをテンプレートから取り外して裏返します。裏返した状態でまたテンプレートに固定します。

---

# 8A



ステップ**6A**と同じ用にして2つ目の線にも折り目をつけます。

---

## 折り目をつける方法 (B)

---

# 5B	



ペンでプラ板に折り線を書き写します（力を書けて折り線をつける必要はありません）。この時、必要であればクリップやテープを使ってプラ板をテンプレートの紙に固定しておくと書き写すのが簡単です。

---

# 6B



幅2~5 mm、深さ2~3 mm、長さが最低で5 cmくらいの溝がついた動かない台や安定した板の上を探します。床板の隙間やテーブルの切れ目、キッチンカウンターの上にそのような溝があることが多いです。もちろん、木材や他の材料に自分で切れ目を入れて使ってもいいです。次に、ボールペンのように先が丸い道具を準備します（バターナイフやスプーン、お箸でもいいです）。

まず、2つの折り線のうち1つに折り目をつけます。ミシンで布を動かしていくように、片方の手でシートをずらしていきます。もう一方の手で先の丸い道具を持って、書き写したパターンにそってシートを溝に押し付けます。

---

# 7B



シールドをひっくり返します。

---

# 8B



ステップ6Bと同じようにして、もう1つの折り目をつけていきます。

---

# 9



折り目の端からプラ板をつまんでいき、丁寧に反対側まで折っていきます。もしもある場所がうまく折れないようなら、前のステップに戻って折り目をつけ直しましょう。

---

# 10



もう1つの折り目を折りましょう。ただし、最初の線と山・谷が逆なことに注意しましょう。

---

# 11	



長さ400 mmのゴムバンドを切り、クリップに装着します。シールドの穴に対して後ろから前にクリップを通します。

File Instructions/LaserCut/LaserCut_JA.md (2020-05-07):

---
layout: page
title: レーザーカッターを使う方法
tagline: &nbsp <span class="instructionsTaglineEmojiLinks"><a href = "https://github.com/HappyShield/HappyShield/tree/master/Templates/LaserCut" ><i class="em em-triangular_ruler" aria-role="presentation" aria-label="TRIANGULAR RULER"></i></a></span>
permalink: /laser-cut/ja/
language: ja
---

<script src="https://snapwidget.com/js/snapwidget.js"></script>
<iframe src="https://snapwidget.com/embed/811086" class="snapwidget-widget" allowtransparency="true" frameborder="0" scrolling="no" style="border:none; overflow:hidden;  width:100%; "></iframe>

---

## 免責事項 (Disclaimer)

---

The University of Cambridge (UC) and the University of Queensland (UQ) make no warranty of any kind, express or implied, about the design, characteristics, durability, proper use or performance of the HappyShield, including but not limited to implied warranties of merchantability and fitness for any particular purpose. The HappyShield is designed to minimise exposure to fluids and sprays, but UC and UQ do not warrant that HappyShield will protect users from COVID-19 infection or any other infectious disease. Nothing in this material constitutes medical advice, and users should seek their own medical advice about whether HappyShield is suitable for the use they intend, and whether they should use it in conjunction with any other medical or other strategies. To the fullest extent allowed by law, UC and UQ exclude all implied warranties, guarantees, terms and conditions. UC and UQ are not liable for any claims, demands, damages or injuries, including but not limited to property damage, bodily injury or illness, death, indirect, special or consequential damages (“the Claims”) arising out of using the HappyShield, and users of HappyShield release UC and UQ and their officers, employees, contractors and agents from all Claims.

---

--- 

## ツール

---

* レーザーカッター
* ハサミまたはカッター

---

## 材料

---

**シールド**

* 厚さ0.5 mmのPETまたはアセテートの板
* 幅20 mmのゴムバンド (70% ポリエステル 30% ゴム)

---

---

# 制作手順

---

# 1



テンプレートファイルを使って透明なプラ板をレーザーカットします。この時、レーザーカッターのパワーとスピードが、板をきっちりと切れるような値になるように気をつけましょう。

---

# 2	



折り線を手で折ります。線の端から丁寧につまんでいき、折り目にそって反対側まで進んでいきます。

--- 

# 3 	



ステップ2と同様に、2つめの折り線を折ります。

---

# 4	



長さ400 mmのゴムバンドを切り、クリップに装着します。シールドの穴に対して後ろから前にクリップを通します。

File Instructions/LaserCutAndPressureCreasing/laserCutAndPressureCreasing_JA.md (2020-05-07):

---
layout: page
title: レーザーカットとプレス整形を使う方法
tagline: &nbsp <span class="instructionsTaglineEmojiLinks"> <a href = "https://youtu.be/IPKiPi-Tne8"><i class="em em-video_camera" aria-role="presentation" aria-label="VIDEO CAMERA"></i></a> <a href = "https://github.com/HappyShield/HappyShield/tree/master/Templates/LaserCutAndPressureCreasing" ><i class="em em-triangular_ruler" aria-role="presentation" aria-label="TRIANGULAR RULER"></i></a></span>
permalink: /pressure-creasing/ja/
language: ja
---

<script src="https://snapwidget.com/js/snapwidget.js"></script>
<iframe src="https://snapwidget.com/embed/810066" class="snapwidget-widget" allowtransparency="true" frameborder="0" scrolling="no" style="border:none; overflow:hidden;  width:100%; "></iframe>

---

## 免責事項 (Disclaimer)

---

The University of Cambridge (UC) and the University of Queensland (UQ) make no warranty of any kind, express or implied, about the design, characteristics, durability, proper use or performance of the HappyShield, including but not limited to implied warranties of merchantability and fitness for any particular purpose. The HappyShield is designed to minimise exposure to fluids and sprays, but UC and UQ do not warrant that HappyShield will protect users from COVID-19 infection or any other infectious disease. Nothing in this material constitutes medical advice, and users should seek their own medical advice about whether HappyShield is suitable for the use they intend, and whether they should use it in conjunction with any other medical or other strategies. To the fullest extent allowed by law, UC and UQ exclude all implied warranties, guarantees, terms and conditions. UC and UQ are not liable for any claims, demands, damages or injuries, including but not limited to property damage, bodily injury or illness, death, indirect, special or consequential damages (“the Claims”) arising out of using the HappyShield, and users of HappyShield release UC and UQ and their officers, employees, contractors and agents from all Claims.

---

--- 

## ツール

---

* レーザーカッター
* 10トンのプレス機
* 直径1 mmのワイヤーを切れるペンチ
* ハサミまたはカッター
* ドリルまたはドライバー

---

## 材料

---

**プレス整形に使う3つのパーツ**

* 厚さ4 mmのMDF板
* 直径1 mmのワイヤー 
* 長さ6~20 mmの木ネジ
* 透明なテープ（セロテープなど）

**シールド**

* 厚さ0.5 mmのPETまたはアセテートの板
* 幅20 mmのゴムバンド (70% ポリエステル 30% ゴム)

---

---

# 制作手順

---

## プレス整形に使う3つのパーツ

---

# 1 	



プレス機で押す「型」のパーツを3つ作るために、テンプレートをダウンロードします。使っているレーザーカッターに入るサイズのテンプレートを選びましょう（ファイル名にテンプレートのサイズが書いてあります）。このテンプレートを使ってMDF板を切ります。

---

# 2



レーザーカッターから3つのパーツを取り出します。次に、パーツAとパーツCの点線部の長さになるようにワイヤーを切断します。ワイヤーを点線部に沿うように配置して、テープで固定します。ワイヤーが点線からズレたりはみ出したりしないように気をつけましょう。

---

# 3



パーツAの上にパーツBを乗せて、短い木ネジで固定します。必要であればパーツAとパーツBの下に大きな板などを敷いておきます。これは、プレス成形の圧力を均一に伝えるためのものです。パーツCの上にも必要であれば大きめの板を入れましょう。

--- 

## シールド

---

# 1



HappyShield laser-cutting templateをダウンロードします。使っているレーザーカッターに入るサイズのテンプレートを選びましょう（ファイル名にテンプレートのサイズが書いてあります）。

---

# 2	



テンプレートを使って透明なプラ板をレーザーカットします。この時、レーザーカッターのパワーとスピードが、板をきっちりと切れるような値になるように気をつけましょう。

レーザーカットしたシールド本体と、バンドを固定するためのクリップを取り出します。必要であればシールドとクリップの端をアルコールや石鹸で磨いて、汚れを取り除きます。

--- 

# 3



シールドをプレス整形のためのパーツに挟んで押し、曲線を折ります。

---

# 4	



長さ400 mmのゴムバンドを切り、クリップに装着します。

---

# 5	



シールドの穴に対して後ろから前にクリップを通します。

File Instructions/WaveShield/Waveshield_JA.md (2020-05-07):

---
layout: page
title: なみなみシールド
tagline: &nbsp <span class="instructionsTaglineEmojiLinks"> <a href = "https://github.com/HappyShield/HappyShield/tree/master/Templates/Waveshield" ><i class="em em-triangular_ruler" aria-role="presentation" aria-label="TRIANGULAR RULER"></i></a></span>
permalink: /wave-shield/ja/
language: ja
---

<i class="em em-timer_clock" aria-role="presentation" aria-label=""></i>: 10-15′

---

<script src="https://snapwidget.com/js/snapwidget.js"></script>
<iframe src="https://snapwidget.com/embed/812110" class="snapwidget-widget" allowtransparency="true" frameborder="0" scrolling="no" style="border:none; overflow:hidden;  width:100%; "></iframe>

---

---

## Disclaimer

---

The University of Cambridge (UC) and the University of Queensland (UQ) make no warranty of any kind, express or implied, about the design, characteristics, durability, proper use or performance of the HappyShield, including but not limited to implied warranties of merchantability and fitness for any particular purpose. The HappyShield is designed to minimise exposure to fluids and sprays, but UC and UQ do not warrant that HappyShield will protect users from COVID-19 infection or any other infectious disease. Nothing in this material constitutes medical advice, and users should seek their own medical advice about whether HappyShield is suitable for the use they intend, and whether they should use it in conjunction with any other medical or other strategies. To the fullest extent allowed by law, UC and UQ exclude all implied warranties, guarantees, terms and conditions. UC and UQ are not liable for any claims, demands, damages or injuries, including but not limited to property damage, bodily injury or illness, death, indirect, special or consequential damages (“the Claims”) arising out of using the HappyShield, and users of HappyShield release UC and UQ and their officers, employees, contractors and agents from all Claims.

---

--- 

## ツール

---

* ハサミまたはカッター
* ボールペン

---

## 材料

---

**シールド**

* 厚さ0.5 mmのPETまたはアセテートの板
* 幅20 mmのゴムバンド (70% ポリエステル 30% ゴム)
* 接着用のテープ

---

---

# 制作手順

---

# 1 



テンプレートをプラ板に書き写すために、まず紙にパターンを印刷します。はじめにテンプレートをダウンロードしましょう。A3サイズのシールドを作りたいときはA4のテンプレート、タブロイドサイズのシールドを作りたいときはレターサイズのテンプレートを使います（日本で作る場合はA4のテンプレートをおすすめします）。プリンターがなければ、テンプレートに記載された通りにパターンを手描きします（テンプレートには各部の長さが記入されています）。

---

# 2



透明なプラ板をパターンの描かれた紙の上に置きます。

---

# 3



ボールペンで穴の場所を書き写していきましょう。インクは最後にアルコールで拭けば消せるので、木にしなくて大丈夫です。ハサミを入れるために直線とまるいコーナーも書き写します。

---

# 4



ハサミかカッターを使ってシールドのふちを切り出していきます。

---

# 5



穴を開けます。穴あけパンチを使うと簡単ですが、カッターでもできます。

---

# 6



短冊型のパーツ1と2の真ん中をテープでとめます。うまくできていれば、2つのパーツの穴を同じ位置に揃えた時に、全体が左右対称のM字に曲がります。

---

# 7



短冊型のパーツ1,2,3,大きなフェイスシールドのパーツ、Cが内側から外側に並ぶように配置します。穴の中にゴムバンドを通して固定します。上の穴からゴムバンドが外に出て、下の穴からゴムバンドが内側に戻るようにします。

---

# 8



シールドの完成です！

---

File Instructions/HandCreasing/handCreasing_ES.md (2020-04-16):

---
layout: page
title: Hand Creasing
tagline: &nbsp <span class="instructionsTaglineEmojiLinks"> <a href="https://youtu.be/8RvlrtrebBE"><i class="em em-video_camera" aria-role="presentation" aria-label="VIDEO CAMERA"></i></a> <a href = "https://github.com/HappyShield/HappyShield/tree/master/Templates/HandCreasing" ><i class="em em-triangular_ruler" aria-role="presentation" aria-label="TRIANGULAR RULER"></i></a></span>
permalink: /hand-creasing/es/
language: es
---

<i class="em em-timer_clock" aria-role="presentation" aria-label=""></i>: 10-15′

---

<script src="https://snapwidget.com/js/snapwidget.js"></script>
<iframe src="https://snapwidget.com/embed/810064" class="snapwidget-widget" allowtransparency="true" frameborder="0" scrolling="no" style="border:none; overflow:hidden;  width:100%; "></iframe>

---

---

## Aviso Legal

---

La Universidad de Cambridge (UC) y la Universidad de Queensland (UQ) no ofrecen garantía de ningún tipo, de manera explícita o implícita, sobre el diseño, características y durabilidad, uso o desempeño apropiado del HappyShield, incluido, pero no limitado a las garantías tácitas de comercialización y adaptabilidad para cualquier propósito particular. El HappyShield fue diseñado para minimizar la exposición a fluidos y aerosoles, pero la UC y la UQ no garantizan que el HappyShield proteja a los usuarios frente a infecciones por COVID-19 o cualquier otra enfermedad infecciosa. Este texto no constituye asesoramiento médico, y los usuarios deberán obtener asesoramiento médico por sus propios medios para definir si el uso del HappyShield es apropiado para sus fines, y, o si es necesario utilizarlo conjuntamente con otras estrategias médicas o de cualquier tipo. En la máxima medida permitida por la ley, la UC y la UQ excluyen todas las garantías, términos y condiciones, ya sean explícitos o implícitos. La UC y la UQ no se responsabilizan por reclamaciones, demandas, daños o perjuicios, incluyendo, pero no limitando a daños a la propiedad, lesiones corporales o enfermedad, muerte, daños indirectos, especiales o resultantes (“las Reclamaciones”) que surjan por el uso del HappyShield, y los usuarios del HappyShield liberan a la UC, a la UQ y a sus oficiales, empleados, proveedores y agentes de cualquier Reclamación.

---

--- 

## Herramientas

---

* Tijeras o cuchilla
* Bolígrafo
* Regla
* Cuchillo de mantequilla
* Impresora

---

## Materiales

---

**Escudo**

* Hoja de 0.5mm de grosor de Tereftalato de Polietileno (PET) o, por lo menos, Acetato
* Banda de tejido elástico de 20 mm (70% poliéster 30% goma)
* Cinta adhesiva

---

---

# Instrucciones

---

# 1 



Descarga la plantilla de trazado. Las plantillas en formato A4 están disponibles para escudos tamaño A3. Las plantillas en tamaño Carta están disponibles para escudos tamaño Tabloide. Si no tienes acceso a una impresora, puedes dibujar tu propia platilla usando las dimensiones mostradas en la plantilla.

---

# 2



Coloca la hoja transparente sobre la plantilla. Marca la posición de los orificios donde irá la correa con un bolígrafo o marcador. No te preocupes por la tinta, puede ser eliminada con un paño empapado en alcohol. 

---

# 3



Delinea el perímetro del escudo para cortarlo. 

---

# 4



Corta a lo largo del perímetro del escudo usando tijeras o una cuchilla. Corta los orificios de la correa. También puedes usar una perforadora de papel para hacer estos orificios. 

Posteriormente, corta los clips de fricción usando una cuchilla.

¡Ahora, dibujemos una sonrisa en esa cara!

---

## Método de Plegado A

---

# 5A



Coloca la hoja transparente sobre la plantilla. Fíjala con clips o cinta adhesiva para un trazado preciso.

---

# 6A



Usando una regla y aplicando presión, traza los segmentos rectos entre cada punto consecutivo, usando 2-3 trazos según sea necesario hasta que perciba una hendidura en la hoja.

---

# 7A



Dale la vuelta a la hoja transparente. Fija la hoja y la plantilla de nuevo.

---

# 8A



Traza la segunda curva del mismo modo que hiciste en el paso **6A**.

---

## Creasing Method B

---

# 5B	



Traza las curvas de plegado con un bolígrafo (no precisa presión adicional en este paso). Si lo deseas, fija la hoja a la plantilla con clips o cinta adhesiva para un trazado más preciso.

---

# 6B



Encuentra una hendidura de 2-5 mm de ancho y al menos 5 cm de largo en una superficie o pieza de trabajo fija. El espacio entre las tarimas del suelo, los segmentos de una mesa de comedor o la encimera de la cocina son buenas opciones. Como alternativa haz tu propia hendidura en una pieza de madera u otro material. Posteriormente toma un bolígrafo o cualquier otra herramienta con una punta relativamente redondeada (cualquier parte redondeada de un cuchillo de mantequilla, cuchara o palillo pueden funcionar).

Usando una mano para mover la hoja como lo harías con una pieza de tela a través de una máquina de coser, usa la otra mano para pasar de manera repetida la herramienta sobre la superficie del material sobre la hendidura, siguiendo una de las curvas de plegado que has trazado.

---

# 7B



Dale la vuelta al escudo.

---

# 8B



Repite el paso 6B para la otra curva de plegado.

---

# 9



Comenzando por un extremo de la curva de plegado, y trabajando hacia el otro extremo de la curva, dobla cuidadosamente la hoja para plegarla a lo largo de la curva. Si alguno de los segmentos no se pliega fácilmente, repite el procedimiento de plegado. 

---

# 10



Repite el paso 9 para la otra curva, pero en esta ocasión, dobla la hoja en la dirección opuesta. 

---

# 11	



Entrelaza la correa a través de los clips de fricción. Pasa los clips de fricción a través de los orificios en el escudo por la parte trasera del escudo hacia la parte delantera.

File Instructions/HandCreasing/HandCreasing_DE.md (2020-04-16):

---
layout: page
title: Faltung per Hand
tagline: &nbsp <span class="instructionsTaglineEmojiLinks"> <a href="https://youtu.be/8RvlrtrebBE"><i class="em em-video_camera" aria-role="presentation" aria-label="VIDEO CAMERA"></i></a> <a href = "https://github.com/HappyShield/HappyShield/tree/master/Templates/HandCreasing" ><i class="em em-triangular_ruler" aria-role="presentation" aria-label="TRIANGULAR RULER"></i></a></span>
permalink: /hand-creasing/de/
language: de
---

<i class="em em-timer_clock" aria-role="presentation" aria-label=""></i>: 10-15′

---

<script src="https://snapwidget.com/js/snapwidget.js"></script>
<iframe src="https://snapwidget.com/embed/810064" class="snapwidget-widget" allowtransparency="true" frameborder="0" scrolling="no" style="border:none; overflow:hidden;  width:100%; "></iframe>

---

---

## Disclaimer

---

Die University of Cambridge (UC) und die University of Queensland (UQ) übernehmen keinerlei ausdrückliche oder stillschweigende Garantie für das Design, die Eigenschaften, die Haltbarkeit, den ordnungsgemäßen Gebrauch oder die Leistung des HappyShield, einschließlich, aber nicht beschränkt auf stillschweigende Garantien der Marktgängigkeit und der Eignung für einen bestimmten Zweck. Das HappyShield ist so konzipiert, dass die Exposition gegenüber Flüssigkeiten und Sprays minimiert wird, aber UC und UQ garantieren nicht, dass das HappyShield die Benutzer vor einer COVID-19-Infektion oder einer anderen Infektionskrankheit schützt. Nichts in diesem Material stellt einen medizinischen Rat dar, und Benutzer sollten ihren eigenen medizinischen Rat darüber einholen, ob HappyShield für die beabsichtigte Anwendung geeignet ist und ob sie es in Verbindung mit anderen medizinischen oder anderen Strategien verwenden sollten. Soweit gesetzlich zulässig, schließen UC und UQ alle stillschweigenden Garantien, Gewährleistungen, Bestimmungen und Bedingungen in vollem Umfang aus. UC und UQ sind nicht haftbar für Ansprüche, Forderungen, Schäden oder Verletzungen, einschließlich, aber nicht beschränkt auf Sachschäden, Körperverletzung oder Krankheit, Tod, indirekte, besondere oder Folgeschäden ("die Ansprüche"), die sich aus der Verwendung von HappyShield ergeben, und die Benutzer von HappyShield entbinden UC und UQ und ihre leitenden Angestellten, Mitarbeiter, Auftragnehmer und Vertreter von allen Ansprüchen.

---

--- 

## Werkzeuge

---

* Schere oder Rasierklinge
* Kugelschreiber
* Lineal
* Brotmesser 
* Drucker

---

## Materalien

---

**Schild**

* 0,5 mm dickes Polyethylene terephthalate (PET) oder ein Acetat Blatt 
* 20 mm breites Gummiband (70% Polyester 30% Gummi)
* Klebeband

---

---

# Anleitung

---

# 1 



Laden Sie Ihre Suchvorlage herunter. Für Schilder im A3-Format stehen A4-Vorlagen zur Verfügung. Für Schilder im Tabloid-Format sind Vorlagen in Letter-Größe verfügbar. Wenn Sie keinen Zugang zu einem Drucker haben, können Sie Ihre eigene Vorlage mit den auf der Vorlage angegebenen Abmessungen zeichnen.

---

# 2



Legen Sie Ihr transparentes Blatt auf die Schablone. Markieren Sie die Position der Riemenlöcher mit Ihrem Stift oder Marker. Machen Sie sich keine Sorgen wegen der Tinte, sie kann mit einem mit Alkohol befeuchteten Tuch entfernt werden. 

---

# 3



Zeichnen Sie die Grenze des Schildes zum Ausschneiden nach. 

---

# 4



Schneiden Sie die Umrissform des Schildes mit einer Schere oder einer Rasierklinge aus. Schneiden Sie die Riemenlöcher aus. Sie können auch einen Locher verwenden, um diese Löcher zu stanzen. 

Schneiden Sie als nächstes die Reibungsklammern mit einer Rasierklinge aus.

Jetzt wollen wir ein Lächeln auf das Gesicht zaubern!

---

## Faltmethode A

---

# 5A



Legen Sie Ihr transparentes Blatt auf die Vorlage. Fixieren Sie es mit Klammern oder Klebeband für eine präzise Nachzeichnung.

---

# 6A



Zeichnen Sie mit einem Lineal und unter Anwendung von Druck die geraden Segmente zwischen jedem aufeinanderfolgenden Punkt nach und verwenden Sie dabei je nach Bedarf 2-3 Striche, bis Sie eine sichtbare Einbuchtung im Blatt sehen.

---

# 7A



Drehen Sie das transparente Blatt um.  Fixieren Sie das Blatt und die Schablone wieder.

---

# 8A



Zeichnen Sie die zweite Kurve auf die gleiche Weise wie in Schritt **6A** nach.

---

## Faltmethode B

---

# 5B	



Zeichnen Sie die Faltkurven mit einem Stift nach (hier ist kein zusätzlicher Druck erforderlich). Falls erwünscht, befestigen Sie das Blatt mit Klammern oder Klebeband an der Schablone, um ein genaueres Nachzeichnen zu ermöglichen.

---

# 6B



Suchen Sie einen 2-5 mm breiten und 2-3 mm tiefen Kanal von mindestens 5 cm Länge auf einer unbeweglichen Arbeitsfläche oder einem Werkstück. Lücken zwischen Dielenbrettern, Segmenten eines Esstisches oder einer Küchenarbeitsplatte eignen sich hierfür gut. Alternativ können Sie Ihre eigene Rinne aus einem Stück Holz oder einem anderen Material herstellen. Suchen Sie als nächstes einen Kugelschreiber oder ein anderes Werkzeug mit einem relativ stumpfen Ende (jeder stumpfe Teil eines Buttermessers, Löffels oder Stäbchens kann hier ebenfalls funktionieren). 

Benutzen Sie eine Hand, um das Blatt wie ein Stück Stoff durch eine Nähmaschine zu bewegen, und fahren Sie mit der anderen Hand wiederholt mit dem Werkzeug über die Oberfläche des Materials über den Kanal und folgen Sie dabei einer der Knickkurven, die Sie nachgezeichnet haben.

---

# 7B



Drehen Sie den Schild um.

---

# 8B



Wiederholen Sie Schritt 6B für die andere Falzkurve.

---

# 9



Beginnen Sie am Ende der Faltkurve und arbeiten Sie sich zum anderen Ende der Kurve vor, indem Sie das Blatt vorsichtig zusammendrücken, um es entlang der Kurve zu falten. Wenn sich einige Segmente nicht leicht falten lassen, wiederholen Sie den Faltvorgang. 

---

# 10



Wiederholen Sie Schritt 9 für die andere Kurve, aber falten Sie das Blatt diesmal in die andere Richtung. 

---

# 11	



Fädeln Sie das Band durch die Reibungsklammern. Führen Sie die Reibungsklammern durch die Löcher im Schild von der Rückseite des Schildes nach vorne.

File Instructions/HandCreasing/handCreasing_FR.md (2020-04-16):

---
layout: page
title: Pliage à main
tagline: &nbsp <span class="instructionsTaglineEmojiLinks"> <a href="https://youtu.be/8RvlrtrebBE"><i class="em em-video_camera" aria-role="presentation" aria-label="VIDEO CAMERA"></i></a> <a href = "https://github.com/HappyShield/HappyShield/tree/master/Templates/HandCreasing" ><i class="em em-triangular_ruler" aria-role="presentation" aria-label="TRIANGULAR RULER"></i></a></span>
permalink: /hand-creasing/fr/
language: fr
---

<i class="em em-timer_clock" aria-role="presentation" aria-label=""></i>: 10-15′

---

<script src="https://snapwidget.com/js/snapwidget.js"></script>
<iframe src="https://snapwidget.com/embed/810064" class="snapwidget-widget" allowtransparency="true" frameborder="0" scrolling="no" style="border:none; overflow:hidden;  width:100%; "></iframe>

---

---

## Clause de non-responsabilité

---

L'Université de Cambridge (UC) et l'Université du Queensland (UQ) ne donnent aucune garantie d'aucune sorte, expresse ou implicite, sur la conception, les caractéristiques, la durabilité, le bon usage ou les performances du HappyShield, y compris, mais sans s'y limiter, les garanties implicites de qualité marchande et d'adéquation à un usage particulier. Le HappyShield est conçu pour minimiser l'exposition aux liquides et aux sprays, mais l'UC et l'UQ ne garantissent pas que le HappyShield protégera les utilisateurs contre l'infection par COVID-19 ou toute autre maladie infectieuse. Rien dans ce matériel ne constitue un avis médical, et les utilisateurs doivent demander leur propre avis médical pour savoir si HappyShield est adapté à l'usage qu'ils en ont l'intention, et s'ils doivent l'utiliser en conjonction d'autres stratégies médicales ou autres. Dans toute la mesure permise par la loi, l'UC et l'UQ excluent toutes les garanties implicites, les garanties, les termes et les conditions. L'UC et l'UQ ne sont pas responsables des réclamations, demandes, dommages ou blessures, y compris, mais sans s'y limiter, les dommages matériels, les blessures ou maladies corporelles, la mort, les dommages indirects, spéciaux ou consécutifs ("les Réclamations") découlant de l'utilisation de HappyShield, et les utilisateurs de HappyShield libèrent l'UC et l'UQ et leurs dirigeants, employés, entrepreneurs et agents de toutes les Réclamations.

---

--- 

## Outils

---

* Ciseaux ou lame de rasoir
* Stylo à bille
* Règle
* Couteau à beurre
* Imprimante

---

## Matériel

---

**Bouclier**

* 0,5 mm d'épaisseur de Feuille de polyéthylène téréphtalate (PET) ou d'acétate au moins 
* Bande élastique tricotée de 20 mm de large (70% polyester 30% caoutchouc)
* Scotch

---

---

# Instructions

---

# 1 



Téléchargez votre modèle de traçage. Des gabarits au format A4 sont disponibles pour les boucliers au format A3. Des modèles au format lettre sont disponibles pour les boucliers au format tabloïd. Si vous n'avez pas accès à une imprimante, vous pouvez dessiner votre propre modèle en utilisant les dimensions indiquées sur le modèle.

---

# 2



Placez votre feuille transparente sur le modèle. Marquez l'emplacement des trous de sangle avec votre stylo ou votre marqueur. Ne vous inquiétez pas pour l'encre, elle peut être enlevée avec un chiffon imbibé d'alcool. 

---

# 3



Tracez les contours du bouclier pour le découpage.  

---

# 4



Découpez la forme des contours du bouclier à l'aide de ciseaux ou d'une lame de rasoir. Découpez les trous des sangles. Vous pouvez également utiliser un perforateur pour faire ces trous. 

Ensuite, découpez les clips de friction à l'aide d'une lame de rasoir.

Et maintenant, souriez!

---

## Méthode de pliage A

---

# 5A



Placez votre feuille transparente sur le modèle. Fixez avec des clips ou du ruban adhésif pour un traçage précis.

---

# 6A



À l'aide d'une règle, et en exerçant une pression, tracez les segments droits entre chaque point consécutif, en utilisant 2 ou 3 coups au besoin jusqu'à ce que vous voyiez une indentation visible sur la feuille.

---

# 7A



Retournez la feuille transparente.  Fixez à nouveau la feuille et le modèle.

---

# 8A



Tracez la deuxième courbe de la même manière qu'à l'étape **6A**.

---

## Méthode de pliage B

---

# 5B	



Tracez les courbes de pliage avec un stylo (aucune pression supplémentaire n'est nécessaire ici). Si vous le souhaitez, fixez la feuille au gabarit à l'aide de clips ou de ruban adhésif pour un traçage plus précis.

---

# 6B



Trouvez un canal de 2-5 mm de large et 2-3 mm de profondeur d'au moins 5 cm de long sur une surface de travail ou une pièce immobile. Les espaces entre les lames de plancher, les segments d'une table à manger ou d'un plan de travail de cuisine conviennent bien pour cela. Vous pouvez également fabriquer votre propre canal dans un morceau de bois ou un autre matériau. Ensuite, trouvez un stylo à bille ou tout autre outil dont le bout est relativement émoussé (toute partie émoussée d'un couteau à beurre, d'une cuillère ou d'une baguette peut également fonctionner ici). 

D'une main, déplacez la feuille comme vous le feriez avec un morceau de tissu dans une machine à coudre, de l'autre main, faites passer l'outil à plusieurs reprises sur la surface du matériau dans le canal, en suivant l'une des courbes de pliage que vous avez tracées.

---

# 7B



Retournez le bouclier.

---

# 8B



Répétez l'étape 6B pour l'autre courbe de pliage.

---

# 9



En commençant à l'extrémité de la courbe de pliage, et en vous rendant vers l'autre extrémité de la courbe, pincez doucement la feuille pour la plier le long de la courbe. Si certains segments ne se plient pas facilement, répétez la procédure de pliage. 

---

# 10



Répétez l'étape 9 pour l'autre courbe, mais cette fois, pliez la feuille dans l'autre sens. 

---

# 11	



Faites passer la sangle dans les clips à friction. Faites passer les clips à friction à travers les trous du bouclier, de l'arrière vers l'avant.

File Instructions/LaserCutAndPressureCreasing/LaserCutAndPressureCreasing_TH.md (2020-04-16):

---
layout: page
title: การตัดด้วยเลเซอร์และการกดเพื่อให้เกิดรอยพับ
tagline: &nbsp <span class="instructionsTaglineEmojiLinks"> <a href = "https://youtu.be/IPKiPi-Tne8"><i class="em em-video_camera" aria-role="presentation" aria-label="VIDEO CAMERA"></i></a> <a href = "https://github.com/HappyShield/HappyShield/tree/master/Templates/LaserCutAndPressureCreasing" ><i class="em em-triangular_ruler" aria-role="presentation" aria-label="TRIANGULAR RULER"></i></a></span>
permalink: /pressure-creasing/th/
language: th
---

<script src="https://snapwidget.com/js/snapwidget.js"></script>
<iframe src="https://snapwidget.com/embed/810066" class="snapwidget-widget" allowtransparency="true" frameborder="0" scrolling="no" style="border:none; overflow:hidden;  width:100%; "></iframe>

---

## Disclaimer

---

The University of Cambridge (UC) and the University of Queensland (UQ) make no warranty of any kind, express or implied, about the design, characteristics, durability, proper use or performance of the HappyShield, including but not limited to implied warranties of merchantability and fitness for any particular purpose. The HappyShield is designed to minimise exposure to fluids and sprays, but UC and UQ do not warrant that HappyShield will protect users from COVID-19 infection or any other infectious disease. Nothing in this material constitutes medical advice, and users should seek their own medical advice about whether HappyShield is suitable for the use they intend, and whether they should use it in conjunction with any other medical or other strategies. To the fullest extent allowed by law, UC and UQ exclude all implied warranties, guarantees, terms and conditions. UC and UQ are not liable for any claims, demands, damages or injuries, including but not limited to property damage, bodily injury or illness, death, indirect, special or consequential damages (“the Claims”) arising out of using the HappyShield, and users of HappyShield release UC and UQ and their officers, employees, contractors and agents from all Claims.

---

--- 

## เครื่องมือ

---

* เครื่องตัดเลเซอร์
* เครื่องกดขนาด 10 ตัน
* คีมสามารถตัดลวดสลิงเหล็กขนาด 1 มม.
* กรรไกรหรือใบมีดโกน
* สว่านหรือไขควง

---

## วัสดุ

---

**จิ๊กกด 3 ส่วน**

* 4 มม. MDF
* เชือกลวดเหล็กขนาด 1 มม
* สกรูไม้ขนาด 6-20 มม
* เทปพลาสติกใส

**หน้ากาก**

* แผ่นพลาสติกใส Polyethylene terephthalate (PET) หรือแผ่นอะซิเตท หนาอย่างน้อย 0.5 มิลลิเมตร
* สายยางยืดถักกว้าง 20 มม. (70% โพลีเอสเตอร์ 30% ยาง)

---

---

# คำแนะนำ

---

## จิ๊กกด 3 ส่วน

---

# 1 	



ดาวน์โหลดเทมเพลตการตัดด้วยเลเซอร์สำหรับจิ๊กกด 3 ส่วนที่พอดีกับแท่นของเครื่องตัดเลเซอร์ของคุณ (ขนาดของแม่แบบการตัดจะได้รับในชื่อไฟล์) เลเซอร์ตัด MDF โดยใช้ไฟล์แม่แบบ

---

# 2



เอาจิ๊กกด 3 ส่วนออกจากเครื่องตัดเลเซอร์ ตัดลวดสลิงตามความยาวของเส้นโค้งประที่อยู่ในส่วน A และ C ของแม่แบบ

ติดเทปลวดโลหะลงบนเส้นประที่ร่องของชิ้นส่วน A และ C ของจิ๊กกด ตรวจสอบให้แน่ใจว่าไม่เบี่ยงเบนไปจากเส้นโค้งประและไม่ขยายเกินปลายของเส้นประ

---

# 3



ต่อส่วน B ด้านบน A โดยใช้สกรูไม้สั้น แนบส่วน A และ B ที่รวมกันเข้ากับบล็อกตามต้องการเพื่อกระจายแรงกดให้ทั่วพื้นผิวจิ๊ก ทำเช่นเดียวกันสำหรับส่วน C

--- 

## หน้ากาก

---

# 1



ดาวน์โหลดเทมเพลตการตัดด้วยเลเซอร์ HappyShield ที่พอดีกับแท่นของเครื่องตัดเลเซอร์ของคุณ (ขนาดของแม่แบบตัดจะได้รับในชื่อไฟล์)

---

# 2	



เลเซอร์ตัดวัสดุแผ่นพลาสติกใสโดยใช้ไฟล์แม่แบบต้องแน่ใจว่าเครื่องตัดเลเซอร์และความเร็วที่ใช้ต้องสามารถตัดผ่านความลึกของวัสดุได้อย่างดี

เมื่อตัดเสร็จแล้วให้นำหน้ากากและคลิปหนีบออกจากแท่นเครื่องตัดเลเซอร์ สามารถเช็ดขอบหน้ากากและคลิปหนีบด้วยแอลกอฮอล์หรือล้างด้วยสบู่ใด ๆ เพื่อกำจัดสิ่งตกค้างที่ตัดด้วยเลเซอร์ออกจากแผ่น

--- 

# 3



ใส่หน้ากากเข้าไปในจิ๊กกด 3 ส่วนแล้วกดเพื่อสร้างรอยพับโค้ง

---

# 4	



ตัดสายยางยืดที่มีความยาว 400 มม. ร้อยสายรัดผ่านคลิปหนีบที่ปลายทั้งสอง

---

# 5	



เสียบคลิปหนีบแบบเกลียวเข้าไปในรูในของหน้ากากจากด้านหลังไปด้านหน้า

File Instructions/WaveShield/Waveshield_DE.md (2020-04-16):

---
layout: page
title: WaveSHIELD
tagline: &nbsp <span class="instructionsTaglineEmojiLinks"> <a href = "https://github.com/HappyShield/HappyShield/tree/master/Templates/Waveshield" ><i class="em em-triangular_ruler" aria-role="presentation" aria-label="TRIANGULAR RULER"></i></a></span>
permalink: /wave-shield/de/
language: de
---

<i class="em em-timer_clock" aria-role="presentation" aria-label=""></i>: 10-15′

---

<script src="https://snapwidget.com/js/snapwidget.js"></script>
<iframe src="https://snapwidget.com/embed/812110" class="snapwidget-widget" allowtransparency="true" frameborder="0" scrolling="no" style="border:none; overflow:hidden;  width:100%; "></iframe>

---

---

## Disclaimer

---

Die University of Cambridge (UC) und die University of Queensland (UQ) übernehmen keinerlei ausdrückliche oder stillschweigende Garantie für das Design, die Eigenschaften, die Haltbarkeit, den ordnungsgemäßen Gebrauch oder die Leistung des HappyShield, einschließlich, aber nicht beschränkt auf stillschweigende Garantien der Marktgängigkeit und der Eignung für einen bestimmten Zweck. Das HappyShield ist so konzipiert, dass die Exposition gegenüber Flüssigkeiten und Sprays minimiert wird, aber UC und UQ garantieren nicht, dass das HappyShield die Benutzer vor einer COVID-19-Infektion oder einer anderen Infektionskrankheit schützt. Nichts in diesem Material stellt einen medizinischen Rat dar, und Benutzer sollten ihren eigenen medizinischen Rat darüber einholen, ob HappyShield für die beabsichtigte Anwendung geeignet ist und ob sie es in Verbindung mit anderen medizinischen oder anderen Strategien verwenden sollten. Soweit gesetzlich zulässig, schließen UC und UQ alle stillschweigenden Garantien, Gewährleistungen, Bestimmungen und Bedingungen in vollem Umfang aus. UC und UQ sind nicht haftbar für Ansprüche, Forderungen, Schäden oder Verletzungen, einschließlich, aber nicht beschränkt auf Sachschäden, Körperverletzung oder Krankheit, Tod, indirekte, besondere oder Folgeschäden ("die Ansprüche"), die sich aus der Verwendung von HappyShield ergeben, und die Benutzer von HappyShield entbinden UC und UQ und ihre leitenden Angestellten, Mitarbeiter, Auftragnehmer und Vertreter von allen Ansprüchen.

---

--- 

## Werkzeuge

---

* Schere oder Rasierklinge
* Kugelschreiber

---

## Materalien

---

**Schild**

* Mindestens 0,5 mm dicke Polyethylenterephthalat- (PET) oder Acetat-Folie 
* 20 mm breites elastisches Band (70% Polyester 30% Gummi)
* Klebeband

---

---

# Anleitung

---

# 1 



Laden Sie Ihre Vorlage herunter (A4 für A3-Schilder, Letter für Tabloid-Schilder). Wenn Sie keinen Zugang zu Druckern haben, können Sie Ihre eigene Vorlage erstellen. Unsere Vorlagen haben Abmessungen!

---

# 2



Legen Sie die transparente Folie auf die Vorlage. 

---

# 3



Markieren Sie die Position der Löcher mit einem Kugelschreiber. Machen Sie sich keine Sorgen wegen der Tinte, sie kann mit einem mit Alkohol befeuchteten Tuch entfernt werden. Markieren Sie die Linien und die unteren runden Ecken zum Ausschneiden. 

---

# 4



Schneiden Sie die Blätter mit einer Schere oder einem Cutter ab und beschneiden Sie die Ecken des Schildes.

---

# 5



Schneiden Sie die Löcher. Sie können dazu eine Papier- oder Lederstanze verwenden.

---

# 6



Kleben Sie die Mitte von Streifen 1 und 2 mit Klebeband fest, überprüfen Sie die M-Form der beiden Streifen, die beim Ausrichten der Löcher entstanden sind. Sie sollte symmetrisch sein.

---

# 7



Richten Sie die Löcher in Streifen aus. Die Reihenfolge von innen nach außen ist: 1,2,3, Gesichtsschutzschild und obere Abdeckung. Binden Sie die Blätter mit dem Gummiband zusammen. Es sollte aus dem oberen Loch herauskommen und in das untere Loch hineingehen.

---

# 8



Ihre Maske ist jetzt bereit.

---

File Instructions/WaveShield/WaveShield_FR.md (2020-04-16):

---
layout: page
title: WaveSHIELD
tagline: &nbsp <span class="instructionsTaglineEmojiLinks"> <a href = "https://github.com/HappyShield/HappyShield/tree/master/Templates/Waveshield" ><i class="em em-triangular_ruler" aria-role="presentation" aria-label="TRIANGULAR RULER"></i></a></span>
permalink: /wave-shield/fr/
language: fr
---

<i class="em em-timer_clock" aria-role="presentation" aria-label=""></i>: 10-15′

---

<script src="https://snapwidget.com/js/snapwidget.js"></script>
<iframe src="https://snapwidget.com/embed/812110" class="snapwidget-widget" allowtransparency="true" frameborder="0" scrolling="no" style="border:none; overflow:hidden;  width:100%; "></iframe>

---

---

## Décharge de responsabilité

---

L'Université de Cambridge (UC) et l'Université du Queensland (UQ) ne donnent aucune garantie d'aucune sorte, expresse ou implicite, sur la conception, les caractéristiques, la durabilité, le bon usage ou les performances du HappyShield, y compris, mais sans s'y limiter, les garanties implicites de qualité marchande et d'adéquation à un usage particulier. Le HappyShield est conçu pour minimiser l'exposition aux liquides et aux sprays, mais l'UC et l'UQ ne garantissent pas que le HappyShield protégera les utilisateurs contre l'infection par COVID-19 ou toute autre maladie infectieuse. Rien dans ce matériel ne constitue un avis médical, et les utilisateurs doivent demander leur propre avis médical pour savoir si HappyShield est adapté à l'usage qu'ils en ont l'intention, et s'ils doivent l'utiliser en conjonction avec d'autres stratégies médicales ou autres. Dans toute la mesure permise par la loi, l'UC et l'UQ excluent toutes les garanties implicites, les garanties, les termes et les conditions. L'UC et l'UQ ne sont pas responsables des réclamations, demandes, dommages ou blessures, y compris, mais sans s'y limiter, les dommages matériels, les blessures ou maladies corporelles, la mort, les dommages indirects, spéciaux ou consécutifs ("les Réclamations") découlant de l'utilisation de HappyShield, et les utilisateurs de HappyShield libèrent l'UC et l'UQ et leurs dirigeants, employés, entrepreneurs et agents de toutes les Réclamations.

---

--- 

## Outils

---

* Ciseaux ou lame de rasoir
* Stylo à bille

---

## Matériel

---

**Bouclier**

* Feuille de polyéthylène téréphtalate (PET) ou d'acétate d'au moins 0,5 mm d'épaisseur 
* Bande élastique tricotée de 20 mm de large (70% polyester 30% caoutchouc)
* Scotch

---

---

# Instructions

---

# 1 



Téléchargez le format de votre modèle de traçage (A4 pour les boucliers A3, Lettre pour les boucliers tabloïdes). Si vous n'avez pas accès à des imprimantes, vous pouvez dessiner votre propre modèle. Nos modèles de traçage ont des dimensions !

---

# 2



Placez votre feuille transparente sur le modèle. 

---

# 3



Marquez l'emplacement des trous avec un stylo à bille. Ne vous inquiétez pas pour l'encre, elle peut être enlevée avec un chiffon imbibé d'alcool. Marquez les lignes et les coins arrondis inférieurs pour la découpe. 

---

# 4



Avec des ciseaux ou un cutter, coupez les feuilles et découpez les coins du bouclier.

---

# 5



Coupez les trous. Vous pouvez utiliser un perforateur à papier ou à cuir si vous en avez un.

---

# 6



Collez du ruban adhésif au milieu des bandes 1 et 2, vérifiez la forme en M des deux bandes lorsque les trous sont alignés. Elle doit être symétrique.

---

# 7



Alignez les trous entre les bandes. L'ordre de l'intérieur vers l'extérieur est le suivant : 1,2,3, écran facial, et couvercle supérieur. Attachez les feuilles avec l'élastique. Il doit sortir du trou supérieur et entrer dans le trou inférieur.

---

# 8



Votre masque est prêt maintenant.

---

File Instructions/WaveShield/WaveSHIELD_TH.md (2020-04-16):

---
layout: page
title: WaveSHIELD
tagline: &nbsp <span class="instructionsTaglineEmojiLinks"> <a href = "https://github.com/HappyShield/HappyShield/tree/master/Templates/Waveshield" ><i class="em em-triangular_ruler" aria-role="presentation" aria-label="TRIANGULAR RULER"></i></a></span>
permalink: /wave-shield/th/
language: th
---

<i class="em em-timer_clock" aria-role="presentation" aria-label=""></i>: 10-15′

---

---

## Disclaimer

---

The University of Cambridge (UC) and the University of Queensland (UQ) make no warranty of any kind, express or implied, about the design, characteristics, durability, proper use or performance of the HappyShield, including but not limited to implied warranties of merchantability and fitness for any particular purpose. The HappyShield is designed to minimise exposure to fluids and sprays, but UC and UQ do not warrant that HappyShield will protect users from COVID-19 infection or any other infectious disease. Nothing in this material constitutes medical advice, and users should seek their own medical advice about whether HappyShield is suitable for the use they intend, and whether they should use it in conjunction with any other medical or other strategies. To the fullest extent allowed by law, UC and UQ exclude all implied warranties, guarantees, terms and conditions. UC and UQ are not liable for any claims, demands, damages or injuries, including but not limited to property damage, bodily injury or illness, death, indirect, special or consequential damages (“the Claims”) arising out of using the HappyShield, and users of HappyShield release UC and UQ and their officers, employees, contractors and agents from all Claims.

---

--- 

## เครื่องมือ 

---

* กรรไกรหรือใบมีดโกน
* ปากกาลูกลื่น

---

## วัสดุ

---

**หน้ากาก**

* แผ่นพลาสติกใส Polyethylene terephthalate (PET) หรือแผ่นอะซิเตท หนาอย่างน้อย 0.5 มิลลิเมตร
* สายยางยืดถักกว้าง 20 มม. (70% โพลีเอสเตอร์ 30% ยาง)
* เทป

---

---

# คำแนะนำ

---

# 1 



ดาวน์โหลดรูปแบบลายเทมเพลตของคุณ (ขนาด A4 สำหรับ หน้ากากขนาด A3, ขนาด Letter สำหรับหน้ากากขนาด Tabloid) หากคุณไม่มีเครื่องพิมพ์
คุณสามารถวาดเทมเพลตของคุณเอง 

---

# 2



วางแผ่นหลาสติกใสของคุณบนแม่แบบ

---

# 3



ทำเครื่องหมายตำแหน่งเป็นจุดด้วยปากกาลูกลื่น ไม่ต้องกังวลเกี่ยวกับหมึกสามารถลบได้ด้วยผ้าชุบแอลกอฮอล์ ลากเส้นและมุมรอบล่างสำหรับการตัด

---

# 4



ใช้กรรไกรหรือใบมีดตัดแผ่นและมุมของหน้ากาก

---

# 5



เจาะรู โดยใช้ที่เจาะกระดาษหรือที่เจาะหนัง

---

# 6



สอดยางยืดลงไปในรู จัดให้สวยงาม

---

# 7



จัดแนวรูแถบให้ชิดกัน คำสั่งจากภายในสู่ภายนอกคือ: 1,2,3, แผ่นป้องกันหน้าและปกด้านบน มัดแผ่นด้วยแถบยางยืด มันควรจะออกมาจากรูด้านบนและเข้าไปในรูด้านล่าง

---

# 8



หน้ากากของคุณพร้อมแล้ว

---

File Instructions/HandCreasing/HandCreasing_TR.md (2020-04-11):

---
layout: page
title: Elle Katlama
tagline: &nbsp <span class="instructionsTaglineEmojiLinks"> <a href="https://youtu.be/8RvlrtrebBE"><i class="em em-video_camera" aria-role="presentation" aria-label="VIDEO CAMERA"></i></a> <a href = "https://github.com/HappyShield/HappyShield/tree/master/Templates/HandCreasing" ><i class="em em-triangular_ruler" aria-role="presentation" aria-label="TRIANGULAR RULER"></i></a></span>
permalink: /hand-creasing/tr/
language: tr
---

<i class="em em-timer_clock" aria-role="presentation" aria-label=""></i>: 10-15′

---

<script src="https://snapwidget.com/js/snapwidget.js"></script>
<iframe src="https://snapwidget.com/embed/810064" class="snapwidget-widget" allowtransparency="true" frameborder="0" scrolling="no" style="border:none; overflow:hidden;  width:100%; "></iframe>

---

---

## Sorumluluk Reddi

---

Cambridge Üniversitesi (UC) ve Queensland Üniversitesi (UQ), HappyShield'ın tasarımı, özellikleri, dayanıklılığı, uygun kullanımı veya performansı hakkında, satılabilirlik ve belirli bir amaca uygunluk hakkındaki zımni garantiyle sınırlı kalmamak üzere, açık veya zımni hiçbir garanti vermemektedir.  HappyShield, sıvılara ve spreylere maruz kalmayı en aza indirecek şekilde tasarlanmıştır, ancak UC ve UQ, HappyShield'ın kullanıcıları COVID-19 enfeksiyonundan veya başka bulaşıcı hastalıklardan koruyacağını garanti etmez. Bu materyaldeki hiçbir şey tıbbi tavsiye oluşturmaz ve kullanıcılar HappyShield'in amaçladıkları kullanıma uygun olup olmadığı ve diğer tıbbi veya başka türden stratejilerle birlikte kullanmaları gerekip gerekmediği konusunda kendi tıbbi tavsiyelerini takip etmelidirler. Yasaların izin verdiği azami ölçüde, UC ve UQ tüm zımni garantileri, güvenceleri, şartları ve koşulları hariç tutar. UC ve UQ, HappyShield'ın kullanımından kaynaklanan mülki hasar, bedensel yaralanma veya hastalık, ölüm, dolaylı, özel veya buna bağlı zararlar (“Talepler”) dahil ancak bunlarla sınırlı olmamak üzere herhangi bir hak, talep, hasar veya yaralanmadan sorumlu değildir, ve HappyShield kullanıcıları UC ve UQ'yu ve memurlarını, çalışanlarını, yüklenicilerini ve temsilcilerini tüm Taleplerden muaf tutar.

---

--- 

## Araçlar

---

* Makas ya da maket bıçağı
* Tükenmez kalem
* Cetvel
* Yemek bıçağı
* Yazıcı

---

## Malzemeler

---

**Siperlik**

* 0.5 mm kalınlığında polietilen tereftalat (PET) ya da asetat kağıdı 
* 20 mm genişliğinde elastik kayış (%70 polyester %30 kauçuk)
* Bant

---

---

# Talimatlar

---

# 1 



Kopyalama şablonunu indirin. A4 boyutundaki şablonlar A3 boyutundaki siperlikler içindir. Letter boyutundaki şablonlar Tabloid boyutundaki siperlikler içindir. Eğer yazıcıya erişim imkanınız yoksa, şablonda gösterilen boyutlara göre kendi şablonunuzu çizebilirsiniz.

---

# 2



Şeffaf levhayı şablonun üzerine yerleştirin. Kaleminizle kayış deliklerini işaretleyin. Mürekkep konusunda endişelenmeyin, alkol damlatılmış bir parça bezle çıkarılabilir. 

---

# 3



Kesmek için siperliğin sınırlarının üzerinden geçin. 

---

# 4



Makas veya maket bıçağı yardımıyla siperliğin dış sınırlarını kesin. Kayış deliklerini kesip çıkartın. Bunun için bir delgeç de kullanabilirsiniz.

Daha sonra maket bıçağı yardımıyla kayış tutacaklarını çıkartın.

Şimdi o surata bir gülücük yerleştirelim!

---

## Katlama Yöntemi A

---

# 5A



Şeffaf levhanızı şablonun üzerine yerleştirin. İzleri düzgün takip edebilmek için klips ya da bantla sabitleyin.

---

# 6A



Bir cetvel kullanarak ve basınç uygulayarak, sayfada görünür bir girinti görene kadar gerekirse 2-3 defa üstünden geçerek birbirini izleyen her nokta arasındaki düz parçaların üzerinden geçin.

---

# 7A



Şeffaf levhayı ters çevirin. Şablonu levhaya tekrar sabitleyin.

---

# 8A



İkinci eğrinin üzerinden de **6A** adımında olduğu gibi geçin.

---

## Katlama Yöntemi B

---

# 5B	



Tükenmez kalemle katlama eğrilerinin üzerinden geçin (burda ek basınç uygulamaya gerek yoktur). İsterseniz levhayı şablona klips ya da bant yardımıyla sabitleyebilirsiniz.

---

# 6B



Sabit bir çalışma yüzeyi ya da malzeme üzerinde en az 5 cm uzunluğunda 2-5 mm genişliğinde 2-3 mm derinliğinde bir oluk bulun. Döşeme tahtalarının ya da yemek masasının veya mutfak tezgahının birleşen parçaları arasındaki boşluklar işe yarayabilir. Alternatif olarak, kendi oluğunuzu bir parça tahta veya başka bir malzemeyle yapabilirsiniz. Ardından, bir tükenmez kalem veya nispeten küt bir uca sahip başka bir araç bulun (yemek bıçağının, kaşık veya çatalın herhangi bir küt kısmı iş görür).

Bir elinizle dikiş makinesinde bir parça bezi ilerletir gibi levhayı hareket ettirirken, öteki elinizle çizdiğiniz eğrilerden birini bulduğunuz araçla takip ederek tekrar tekrar oluğun üzerinden geçin. 

---

# 7B



Levhayı ters çevirin.

---

# 8B



6B adımını diğer eğri için tekrar edin.

---

# 9



Katlama eğrisinin bir ucundan başlayıp eğrinin diğer ucuna doğru ilerleyerek, eğri boyunca katlamak için levhayı yavaşça sıkıştırın. Bazı kısımlar kolayca katlanmıyorsa, katlama prosedürünü tekrarlayın. 

---

# 10



9. adımı diğer eğri için tekrar edin ancak bu sefer levhayı öteki yönde katlayın. 

---

# 11	



Kayışı tutacaklardan geçirin. Tutacakları siperliğin arka tarafından ön tarafına doğru deliklerden içeri sokun.

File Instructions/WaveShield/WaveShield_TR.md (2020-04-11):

---
layout: page
title: WaveSHIELD
tagline: &nbsp <span class="instructionsTaglineEmojiLinks"> <a href = "https://github.com/HappyShield/HappyShield/tree/master/Templates/Waveshield" ><i class="em em-triangular_ruler" aria-role="presentation" aria-label="TRIANGULAR RULER"></i></a></span>
permalink: /wave-shield/tr/
language: tr
---

<i class="em em-timer_clock" aria-role="presentation" aria-label=""></i>: 10-15′

---

<script src="https://snapwidget.com/js/snapwidget.js"></script>
<iframe src="https://snapwidget.com/embed/812110" class="snapwidget-widget" allowtransparency="true" frameborder="0" scrolling="no" style="border:none; overflow:hidden;  width:100%; "></iframe>

---

---

## Sorumluluk Reddi

---

Cambridge Üniversitesi (UC) ve Queensland Üniversitesi (UQ), HappyShield'ın tasarımı, özellikleri, dayanıklılığı, uygun kullanımı veya performansı hakkında, satılabilirlik ve belirli bir amaca uygunluk hakkındaki zımni garantiyle sınırlı kalmamak üzere, açık veya zımni hiçbir garanti vermemektedir. HappyShield, sıvılara ve spreylere maruz kalmayı en aza indirecek şekilde tasarlanmıştır, ancak UC ve UQ, HappyShield'ın kullanıcıları COVID-19 enfeksiyonundan veya başka bulaşıcı hastalıklardan koruyacağını garanti etmez. Bu materyaldeki hiçbir şey tıbbi tavsiye oluşturmaz ve kullanıcılar HappyShield'in amaçladıkları kullanıma uygun olup olmadığı ve diğer tıbbi veya başka türden stratejilerle birlikte kullanmaları gerekip gerekmediği konusunda kendi tıbbi tavsiyelerini takip etmelidirler. Yasaların izin verdiği azami ölçüde, UC ve UQ tüm zımni garantileri, güvenceleri, şartları ve koşulları hariç tutar. UC ve UQ, HappyShield'ın kullanımından kaynaklanan mülki hasar, bedensel yaralanma veya hastalık, ölüm, dolaylı, özel veya buna bağlı zararlar (“Talepler”) dahil ancak bunlarla sınırlı olmamak üzere herhangi bir hak, talep, hasar veya yaralanmadan sorumlu değildir, ve HappyShield kullanıcıları UC ve UQ'yu ve memurlarını, çalışanlarını, yüklenicilerini ve temsilcilerini tüm Taleplerden muaf tutar.

---

--- 

## Araçlar

---

* Makas ya da maket bıçağı
* Tükenmez kalem

---

## Malzemeler

---

**Siperlik**

* 0.5 mm kalınlığında polietilen tereftalat (PET) ya da en azından asetat levha 
* 20 mm genişliğinde elastik bant (%70 polyester %30 kauçuk)
* Bant

---

---

# Talimatlar

---

# 1 



Şablon biçiminizi indirin (A3 siperlikler için A4, Tabloid siperlikler için Letter). Yazıcıya erişiminiz yoksa kendi şablonunuzu çizebilirsiniz. Şablonlarımızın boyutları mevcut!

---

# 2



Şeffaf levhanızı şablonun üzerine yerleştirin. 

---

# 3



Deliklerin yerini tükenmez kalemle işaretleyin. Mürekkep için endişelenmeyin, alkol damlatılmış bir parça bezle silebilirsiniz. Çizgileri ve alttaki eğri köşeleri kesmek üzere işaretleyin. 

---

# 4



Makas ya da maket bıçağı yardımıyla levhaları kesin ve köşelerini düzeltin.

---

# 5



Delikleri kesin. Elinizde varsa kağıt ya da deri delgeci kullanabilirsiniz.

---

# 6



1 ve 2 nolu şeritleri ortadan bantlayın, delikleri aynı hizaya geldiğinde şeritlerin M şeklini oluşturduğundan emin olun. Simetrik olması lazım.

---

# 7



Şeritlerin deliklerini hizalayın. İçeriden dışarıya doğru sıralama şu şekilde olmalıdır: 1,2,3, yüz siperliği ve üst örtü. Şeritleri elastik bant ile bağlayın. Bantın üst delikten dışarıya doğru çıkması ve alt delikten içeriye doğru girmesi gerekiyor.

---

# 8



Maskeniz şu anda hazır.

---

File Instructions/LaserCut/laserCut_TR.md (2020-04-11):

---
layout: page
title: Lazer Kesim 
tagline: &nbsp <span class="instructionsTaglineEmojiLinks"><a href = "https://github.com/HappyShield/HappyShield/tree/master/Templates/LaserCut" ><i class="em em-triangular_ruler" aria-role="presentation" aria-label="TRIANGULAR RULER"></i></a></span>
permalink: /laser-cut/tr/
---

<script src="https://snapwidget.com/js/snapwidget.js"></script>
<iframe src="https://snapwidget.com/embed/811086" class="snapwidget-widget" allowtransparency="true" frameborder="0" scrolling="no" style="border:none; overflow:hidden;  width:100%; "></iframe>

---

## Sorumluluk Reddi

---

Cambridge Üniversitesi (UC) ve Queensland Üniversitesi (UQ), HappyShield'ın tasarımı, özellikleri, dayanıklılığı, uygun kullanımı veya performansı hakkında, satılabilirlik ve belirli bir amaca uygunluk hakkındaki zımni garantiyle sınırlı kalmamak üzere, açık veya zımni hiçbir garanti vermemektedir. HappyShield, sıvılara ve spreylere maruz kalmayı en aza indirecek şekilde tasarlanmıştır, ancak UC ve UQ, HappyShield'ın kullanıcıları COVID-19 enfeksiyonundan veya başka bulaşıcı hastalıklardan koruyacağını garanti etmez. Bu materyaldeki hiçbir şey tıbbi tavsiye oluşturmaz ve kullanıcılar HappyShield'in amaçladıkları kullanıma uygun olup olmadığı ve diğer tıbbi veya başka türden stratejilerle birlikte kullanmaları gerekip gerekmediği konusunda kendi tıbbi tavsiyelerini takip etmelidirler. Yasaların izin verdiği azami ölçüde, UC ve UQ tüm zımni garantileri, güvenceleri, şartları ve koşulları hariç tutar. UC ve UQ, HappyShield'ın kullanımından kaynaklanan mülki hasar, bedensel yaralanma veya hastalık, ölüm, dolaylı, özel veya buna bağlı zararlar (“Talepler”) dahil ancak bunlarla sınırlı olmamak üzere herhangi bir hak, talep, hasar veya yaralanmadan sorumlu değildir, ve HappyShield kullanıcıları UC ve UQ'yu ve memurlarını, çalışanlarını, yüklenicilerini ve temsilcilerini tüm taleplerden muaf tutar.

---

--- 

## Aletler

---

* Lazer kesici
* Makas veya maket bıçağı

---

## Malzemeler

---

**Siperlik**

* 0.5 mm kalınlığında Polyethylene terephthalate (PET) veya Asetat Sayfa
* 20 mm genişliğinde elastik bant (70% polyester 30% lastik)

---

---

# Açıklamalar

---

# 1



Şeffaf plastik levhayı şablonu kullanarak lazer kesiciyle kesin. Lazer kesici güç ve hız ayarlarının malzemeyi derinliğince tamamen kesecek şekilde ayarlandığından emin olun. 

---
# 2	



Eğriyi başından sonuna doğru sıkıştırarak eğri boyunca katlayın. 

--- 

# 3 	



2. aşamada anlatılan teknikle ikinci eğriyi de katlayın.

---

# 4	



Elastik bantı sıkıştıma klipslerinden geçirdikten sonra klipsleri sperliğin üzerindeki deliklerden arkadan öne doğru geçirin.

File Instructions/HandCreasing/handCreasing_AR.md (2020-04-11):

---
layout: page
title: الحز اليدوي
tagline: &nbsp <span class="instructionsTaglineEmojiLinks"> <a href="https://youtu.be/a7HmViDaAvk"><i class="em em-video_camera" aria-role="presentation" aria-label="VIDEO CAMERA"></i></a> <a href = "https://github.com/HappyShield/HappyShield/tree/master/Templates/HandCreasing" ><i class="em em-triangular_ruler" aria-role="presentation" aria-label="TRIANGULAR RULER"></i></a></span>
permalink: /hand-creasing/ar/
language: ar
textdirection: rtl
---

<i class="em em-timer_clock" aria-role="presentation" aria-label=""></i>: 10-15′

---

<script src="https://snapwidget.com/js/snapwidget.js"></script>
<iframe src="https://snapwidget.com/embed/810064" class="snapwidget-widget" allowtransparency="true" frameborder="0" scrolling="no" style="border:none; overflow:hidden;  width:100%; "></iframe>

---

---

## إخلاء مسؤولية (Disclaimer)

---

The University of Cambridge (UC) and the University of Queensland (UQ) make no warranty of any kind, express or implied, about the design, characteristics, durability, proper use or performance of the HappyShield, including but not limited to implied warranties of merchantability and fitness for any particular purpose. The HappyShield is designed to minimise exposure to fluids and sprays, but UC and UQ do not warrant that HappyShield will protect users from COVID-19 infection or any other infectious disease. Nothing in this material constitutes medical advice, and users should seek their own medical advice about whether HappyShield is suitable for the use they intend, and whether they should use it in conjunction with any other medical or other strategies. To the fullest extent allowed by law, UC and UQ exclude all implied warranties, guarantees, terms and conditions. UC and UQ are not liable for any claims, demands, damages or injuries, including but not limited to property damage, bodily injury or illness, death, indirect, special or consequential damages (“the Claims”) arising out of using the HappyShield, and users of HappyShield release UC and UQ and their officers, employees, contractors and agents from all Claims.

---

--- 

## الأدوات

---

* مقص أو مشرط
* قلم حبر جاف
* مسطرة
* سكين زبدة
* طابعة

---

## المواد

---

**غطاء الوجه**

* نصف مم سماكة لوح بت البولي ايثيلين تيريفثاليت,  أو لوح شفاف اسيتات
* شريط مطاطي بعرض 20 مم . 70 بوليستر 30٪ مطاط
* شريط لاصق

---

---

# التعليمات

---

# 1 



قم بتحميل المخطط الخاص بغطاء الوجه من موقعنا.  إذا لم تتمكن من الوصول إلى طابعة ، يمكنك رسم المخطط الخاص بك باستخدام الأبعاد الموضحة في الرسمات المذكورة.

---

# 2



ضع الورقة الشفافة على المخطط. ضع علامة على موقع ثقوب الشريط باستخدام قلم التحديد. لا تقلق بشأن الحبر ، يمكن إزالته لاحقاً بقطعة قماش مبللة بالكحول.

---

# 3



قم برسم حدود غطاء الوجه باستخدام القلم أيضاً

---

# 4



قص حدود الغطاء باستخدام مقص أو مشرط. قم أيضاً بفتح ثقوب الشريط المطاطي. يمكنك استخدام خرامة الثقب لعمل هذه الثقوب.
بعد ذلك ، قص المستطيلات الصغيرة والتي ستقوم بتثبيت الشريط في غطاء الوجه.
سنقوم بعد ذلك بحز منحيين لطي الغطاء

---

## طريقة الحز A

---

# 5A



ضع الورقة الشفافة على المخطط وثبتها بشريط لاصق اودبوس ورق.

---

# 6A



باستخدام القلم والمسطرة قم بحز الورقة راسما الخطوط المستقيمة والتي تشكل المنحني وذلك بالضغط على القلم. للقيام بالحز, ربما تحتاج لتعليم الخط ثلاث او اربع مرات.

---

# 7A



اقلب الورقة الشفافة وثبتها مرة أخرى.

---

# 8A



 تتبع المنحنى الثاني بنفس الطريقة كما في الخطوة  قبل السابقة

---

## طريقة الحز B

---

# 5B	



تتبع المنحنيات المرسومة باستخدام قلم. لايلزم ضغط اضافي على القلم هنا قم فقط برسم المنحني

---

# 6B



ستحتاج في هذه الطريقة لقناة (مجراية) بعمق 2-5 مم وعرض 2-3 مم وطول 5 سم. يمكنك عملها من قطعة من الخشب. كما يمكنك استخدامالفراغات الموجودة بين الواح الخشب في أرضية المنزل, او في طاولة الطعام او المطبخ, أي قناة باعاد مشابهة للتي ذكرناها سابقاً يمكن أن تعمل. 
بعد ذلك ، باستخدام اي اداة ذات حرف غير حاد, سكين زبدة أو قلم جاف, قم بتحديد وحز المنحني وذلك بتثبيت اليد التي تحمل القلم ولف الغطاء وتحريكه في اليد الأخرى.

---

# 7B



قم بقلب غطاء الوجه 

---

# 8B



كرر العملية كما في الخطوة  قبل السابقة

---

# 9



قم بطي الغطاء, ابدأ من نهاية منحني الحز, اصغط برفق على طرفي الغطاء وقم بالطي حتى النهاية الاخرى للمنحني. في حال كانت بعض الاجزاء غير سهلة في طيها, كرر اجراء الحز في هذا الجزء. 

---

# 10



كرر الخطوة 9 لمنحنى الحز الآخر ، ولكن هذه المرة ، قم بطي الورقة في الاتجاه الآخر.

---

# 11	



مرر الشريط من خلال مستطيلات التثبيت. مرر المستطيلات عبر الفتحات الموجودة في غطاء من الجانب الخلفي إلى الأمام.

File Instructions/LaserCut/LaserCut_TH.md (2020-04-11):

---
layout: page
title: เลเซอร์คัท
tagline: &nbsp <span class="instructionsTaglineEmojiLinks"><a href = "https://github.com/HappyShield/HappyShield/tree/master/Templates/LaserCut" ><i class="em em-triangular_ruler" aria-role="presentation" aria-label="TRIANGULAR RULER"></i></a></span>
permalink: /laser-cut/th/
language: th
---

<script src="https://snapwidget.com/js/snapwidget.js"></script>
<iframe src="https://snapwidget.com/embed/811086" class="snapwidget-widget" allowtransparency="true" frameborder="0" scrolling="no" style="border:none; overflow:hidden;  width:100%; "></iframe>

---

## Disclaimer

---

The University of Cambridge (UC) and the University of Queensland (UQ) make no warranty of any kind, express or implied, about the design, characteristics, durability, proper use or performance of the HappyShield, including but not limited to implied warranties of merchantability and fitness for any particular purpose. The HappyShield is designed to minimise exposure to fluids and sprays, but UC and UQ do not warrant that HappyShield will protect users from COVID-19 infection or any other infectious disease. Nothing in this material constitutes medical advice, and users should seek their own medical advice about whether HappyShield is suitable for the use they intend, and whether they should use it in conjunction with any other medical or other strategies. To the fullest extent allowed by law, UC and UQ exclude all implied warranties, guarantees, terms and conditions. UC and UQ are not liable for any claims, demands, damages or injuries, including but not limited to property damage, bodily injury or illness, death, indirect, special or consequential damages (“the Claims”) arising out of using the HappyShield, and users of HappyShield release UC and UQ and their officers, employees, contractors and agents from all Claims.

---

--- 

## เครื่องมือ

---

* เครื่องตัดเลเซอร์
* กรรไกรหรือใบมีดโกน

---

## วัสดุ

---

**หน้ากาก**

* แผ่นพลาสติกใส Polyethylene terephthalate (PET) หรือแผ่นอะซิเตท หนาอย่างน้อย 0.5 มิลลิเมตร
* สายยางยืดถักกว้าง 20 มม. (70% โพลีเอสเตอร์ 30% ยาง)

---

---

# คำแนะนำ

---

# 1



ใช้เลเซอร์ตัดวัสดุแผ่นพลาสติกใสโดยใช้ไฟล์แม่แบบ โดยต้องมั่นใจว่าการตั้งค่าพลังงานและความเร็วของเครื่อง มีความเหมาะสม และสามารถตัดแผ่นพลาสติกใสที่มีความหนาตามที่ต้องการได้

---

# 2	



ไล่พับตามรอบพับ จากมุมด้านหนึ่งไปยังมุมอีกด้านหนึ่ง จนหมดแนวโค้ง

--- 

# 3 	



พับเส้นโค้งที่สองโดยใช้ขั้นตอนเดียวกับในขั้นตอนที่ 2

---

# 4	



ร้อยยางยืดจากด้านหลังของหน้ากากไปด้านหน้าของหน้ากาก แล้วใช้คลิปหนีบไว้

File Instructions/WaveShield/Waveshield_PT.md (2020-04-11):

---
layout: page
title: Viseira Ondulada
tagline: &nbsp <span class="instructionsTaglineEmojiLinks"> <a href = "https://github.com/HappyShield/HappyShield/tree/master/Templates/Waveshield" ><i class="em em-triangular_ruler" aria-role="presentation" aria-label="TRIANGULAR RULER"></i></a></span>
permalink: /wave-shield/en/
---

<i class="em em-timer_clock" aria-role="presentation" aria-label=""></i>: 10-15′

---

---

## Aviso Legal (Disclaimer)

---

The University of Cambridge (UC) and the University of Queensland (UQ) make no warranty of any kind, express or implied, about the design, characteristics, durability, proper use or performance of the HappyShield, including but not limited to implied warranties of merchantability and fitness for any particular purpose. The HappyShield is designed to minimise exposure to fluids and sprays, but UC and UQ do not warrant that HappyShield will protect users from COVID-19 infection or any other infectious disease. Nothing in this material constitutes medical advice, and users should seek their own medical advice about whether HappyShield is suitable for the use they intend, and whether they should use it in conjunction with any other medical or other strategies. To the fullest extent allowed by law, UC and UQ exclude all implied warranties, guarantees, terms and conditions. UC and UQ are not liable for any claims, demands, damages or injuries, including but not limited to property damage, bodily injury or illness, death, indirect, special or consequential damages (“the Claims”) arising out of using the HappyShield, and users of HappyShield release UC and UQ and their officers, employees, contractors and agents from all Claims.

---

--- 

## Ferramentas

---

* Tesoura ou lâmina de corte
* Caneta esferográfica

---

## Materiais

---

**Viseira**

* Polietileno tereftalato (PET) com 0,5 mm de espessura ou como alternativa uma folha de acetato
* Fita elástica larga de 20 mm (70% poliéster 30% borracha)
* Fita Adesiva

---

---

# Instruções

---

# 1 



Descarregue o modelo para o formato pretendido (A4 para viseiras A3, "tipo carta" para viseiras "tipo tablóide"). Se não tiver acesso a uma impressora, pode desenhar o seu próprio modelo. Os nossos modelos têm dimensões!

---

# 2



Coloque a folha transparente em cima do modelo. 

---

# 3



Marque a localização dos círculos com a caneta esferográfica. Não se preocupe com a tinta, pode ser removida posteriormente com um pano embebido em álcool. Marque as linhas e os limites inferiores para cortar. 

---

# 4



Com uma tesoura ou lâmina de corte corte a folha transparente e os seus limites inferiores.

---

# 5



Cortes os círculos. Se tiver, pode usar um furador de pele ou de papel.

---

# 6



Fixe com fita adesiva o centro da faixa 1 e 2, confira a forma M que as duas faixas formam quando os círculos estão alinhados. Deve ficar simétrica.

---

# 7



Alinhe os círculos das faixas. A ordem de dentro para fora é: 1,2,3, viseira, parte superior. Segure as faixas com a banda elástica. Deve sair do círculo superior e entrar no círculo inferior.

---

# 8



A sua viseira está pronta.

---

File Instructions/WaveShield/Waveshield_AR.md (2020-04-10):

---
layout: page
title: WaveSHIELD
tagline: &nbsp <span class="instructionsTaglineEmojiLinks"> <a href="https://youtu.be/9PSss8W73v0"><i class="em em-video_camera" aria-role="presentation" aria-label="VIDEO CAMERA"></i></a> <a href = "https://github.com/HappyShield/HappyShield/tree/master/Templates/Waveshield" ><i class="em em-triangular_ruler" aria-role="presentation" aria-label="TRIANGULAR RULER"></i></a></span>
permalink: /wave-shield/ar/
language: ar
textdirection: rtl
---

<i class="em em-timer_clock" aria-role="presentation" aria-label=""></i>: 10-15′

---

---

## إخلاء مسؤولية (Disclaimer)

---

The University of Cambridge (UC) and the University of Queensland (UQ) make no warranty of any kind, express or implied, about the design, characteristics, durability, proper use or performance of the HappyShield, including but not limited to implied warranties of merchantability and fitness for any particular purpose. The HappyShield is designed to minimise exposure to fluids and sprays, but UC and UQ do not warrant that HappyShield will protect users from COVID-19 infection or any other infectious disease. Nothing in this material constitutes medical advice, and users should seek their own medical advice about whether HappyShield is suitable for the use they intend, and whether they should use it in conjunction with any other medical or other strategies. To the fullest extent allowed by law, UC and UQ exclude all implied warranties, guarantees, terms and conditions. UC and UQ are not liable for any claims, demands, damages or injuries, including but not limited to property damage, bodily injury or illness, death, indirect, special or consequential damages (“the Claims”) arising out of using the HappyShield, and users of HappyShield release UC and UQ and their officers, employees, contractors and agents from all Claims.

---

--- 

## الادوات

---

* مقص أو مشرط
* قلم حبر جاف

---

## المواد

---

**غطاء الوجه**

* نصف مم سماكة لوح بت البولي ايثيلين تيريفثاليت,  أو لوح شفاف اسيتات
* شريط مطاطي بعرض 20 مم . 70 بوليستر 30٪ مطاط
* شريط لاصق

---

---

# التعليمات

---

# 1 



قم بتحميل المخطط الخاص بغطاء الوجه من موقعنا.  إذا لم تتمكن من الوصول إلى طابعة ، يمكنك رسم المخطط الخاص بك باستخدام الأبعاد الموضحة في الرسمات المذكورة.

---

# 2



ضع الورقة الشفافة على المخطط. وثبتها 

---

# 3



ضع علامة على موقع الثقوب بقلم حبر جاف. لا تقلق بشأن الحبر ، يمكن إزالته بقطعة قماش مبللة بالكحول. ضع علامة على الخطوط والزوايا السفلية لقصها لاحقاً.

---

# 4



باستخدام المقص أو المشرط قم بقطع الالواح وتقليم زوايا الغطاء. سيتنج لديك خمس اواح 

---

# 5



قم بقطع الثقوب. يمكنك استخدام مثقب الورق أو الجلد إذا كان لديك.

---

# 6



ثبت بالشريط اللاصق اللوحين 1 و 2. تحقق من الشكل المشابه للموجة للوحين عند محاذاة الثقوب فيها. يجب أن يكون هذا الشكل متناظر قد الامكان.

---

# 7



ثبت بيدك كل الالواح مع بعضها. الترتيب من الداخل إلى الخارج: 1 ثم 2 ثم 3 ثم غطاء الوجه ثم الغطاء اعلوي. قم بمحاذاة الثقوب معًا. اربط الالواح بشريط مطاطي. يجب أن يدخل من الثقوب في المنطقة العلوية ويخرج من الثقوب في المنطقة السفلية.

---

# 8



كرر في الجانب المقابل. 

---

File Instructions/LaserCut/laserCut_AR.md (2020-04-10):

---
layout: page
title: القص بالليزر 
tagline: &nbsp <span class="instructionsTaglineEmojiLinks"><a href = "https://github.com/HappyShield/HappyShield/tree/master/Templates/LaserCut" ><i class="em em-triangular_ruler" aria-role="presentation" aria-label="TRIANGULAR RULER"></i></a></span>
permalink: /laser-cut/ar/
language: ar
textdirection: rtl
---

<script src="https://snapwidget.com/js/snapwidget.js"></script>
<iframe src="https://snapwidget.com/embed/811086" class="snapwidget-widget" allowtransparency="true" frameborder="0" scrolling="no" style="border:none; overflow:hidden;  width:100%; "></iframe>

---

## إخلاء مسؤولية (Disclaimer)

---

The University of Cambridge (UC) and the University of Queensland (UQ) make no warranty of any kind, express or implied, about the design, characteristics, durability, proper use or performance of the HappyShield, including but not limited to implied warranties of merchantability and fitness for any particular purpose. The HappyShield is designed to minimise exposure to fluids and sprays, but UC and UQ do not warrant that HappyShield will protect users from COVID-19 infection or any other infectious disease. Nothing in this material constitutes medical advice, and users should seek their own medical advice about whether HappyShield is suitable for the use they intend, and whether they should use it in conjunction with any other medical or other strategies. To the fullest extent allowed by law, UC and UQ exclude all implied warranties, guarantees, terms and conditions. UC and UQ are not liable for any claims, demands, damages or injuries, including but not limited to property damage, bodily injury or illness, death, indirect, special or consequential damages (“the Claims”) arising out of using the HappyShield, and users of HappyShield release UC and UQ and their officers, employees, contractors and agents from all Claims.

---

---

## الادوات
---

* قاطع ليزري
* مقص او مشرط

---

## المواد

---

**غطاء الوجه**

* نصف مم سماكة لوح بت البولي ايثيلين تيريفثاليت,  أو لوح شفاف اسيتات
* شريط مطاطي بعرض 20 مم . 70 بوليستر 30٪ مطاط

---

---

# التعليمات

---

# 1



قم بتنزيل مخطط قص الليزر من موقعنا.  قم بقص اللوح البلاستيكي الشفاف باستخدام بالليزر ، تأكد أن إعدادات طاقة وسرعة القاطع بالليزر مناسبة لعمق ونوع المادة. 

---

# 2	



قم بطي الغطاء, ابدأ من نهاية منحني الحز, اصغط برفق على طرفي الغطاء وقم بالطي حتى النهاية الاخرى للمنحني 

--- 

# 3 	



كرر الخطوة 9 لمنحنى الحز الآخر ، ولكن هذه المرة ، قم بطي الورقة في الاتجاه الآخر

---

# 4	



مرر الشريط من خلال مستطيلات التثبيت. مرر المستطيلات عبر الفتحات الموجودة في غطاء من الجانب الخلفي إلى الأمام.

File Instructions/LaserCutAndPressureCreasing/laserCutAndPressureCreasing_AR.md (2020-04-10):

---
layout: page
title: مكبس مع مقص ليزري
tagline: &nbsp <span class="instructionsTaglineEmojiLinks"> <a href = "https://youtu.be/cbJfRK5AS-o"><i class="em em-video_camera" aria-role="presentation" aria-label="VIDEO CAMERA"></i></a> <a href = "https://github.com/HappyShield/HappyShield/tree/master/Templates/LaserCutAndPressureCreasing" ><i class="em em-triangular_ruler" aria-role="presentation" aria-label="TRIANGULAR RULER"></i></a></span>
permalink: /pressure-creasing/ar/
language: ar
textdirection: rtl
---

<script src="https://snapwidget.com/js/snapwidget.js"></script>
<iframe src="https://snapwidget.com/embed/810066" class="snapwidget-widget" allowtransparency="true" frameborder="0" scrolling="no" style="border:none; overflow:hidden;  width:100%; "></iframe>

---

## إخلاء مسؤولية (Disclaimer)

---

The University of Cambridge (UC) and the University of Queensland (UQ) make no warranty of any kind, express or implied, about the design, characteristics, durability, proper use or performance of the HappyShield, including but not limited to implied warranties of merchantability and fitness for any particular purpose. The HappyShield is designed to minimise exposure to fluids and sprays, but UC and UQ do not warrant that HappyShield will protect users from COVID-19 infection or any other infectious disease. Nothing in this material constitutes medical advice, and users should seek their own medical advice about whether HappyShield is suitable for the use they intend, and whether they should use it in conjunction with any other medical or other strategies. To the fullest extent allowed by law, UC and UQ exclude all implied warranties, guarantees, terms and conditions. UC and UQ are not liable for any claims, demands, damages or injuries, including but not limited to property damage, bodily injury or illness, death, indirect, special or consequential damages (“the Claims”) arising out of using the HappyShield, and users of HappyShield release UC and UQ and their officers, employees, contractors and agents from all Claims.

--- 

---

## الادوات

---

* قاطع ليزري
* مكبس 10 طن
* كماشة قادرة على قطع حبل أسلاك الفولاذ 1 مم
* مقص أو مشرط
* مثقاب أو مفك البراغي

---
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

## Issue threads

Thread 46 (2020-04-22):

Update Hand Creasing template to HS-00-00-01 Design

aurimas-bukauskas, 2020-04-22:
The HS-00-00-01 design is 335 mm wide, meaning it exceeds the width of a single A4 sheet. We'll need to redesign the template printout files to accommodate this.

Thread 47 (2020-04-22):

Update Laser-cut and Pressure Creasing instruction to reflect latest methods used for HS-00-00-01.

aurimas-bukauskas, 2020-04-22:
There have been a few modifications to the 3-part jig construction process for HS-00-00-01 - happy to discuss with whoever tackles these updates! : )

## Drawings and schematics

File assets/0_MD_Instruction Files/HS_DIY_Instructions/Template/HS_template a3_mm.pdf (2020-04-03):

24 | 25

25

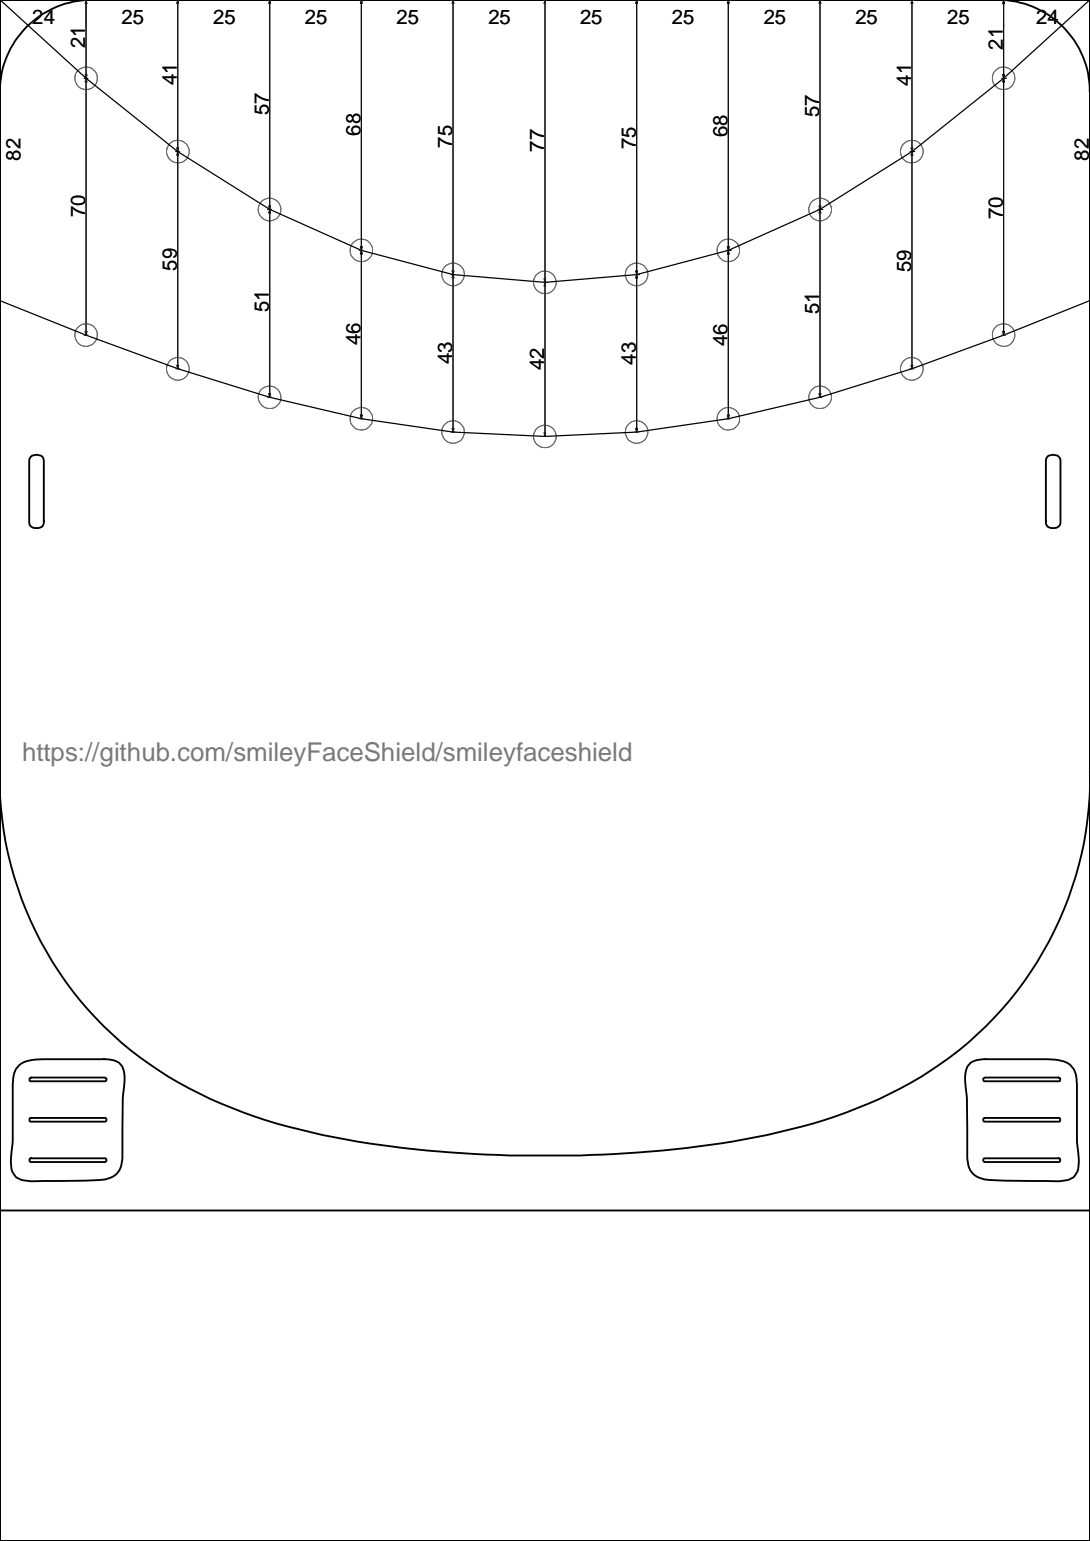
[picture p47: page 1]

https://github.com/smileyFaceShield/smileyfaceshield

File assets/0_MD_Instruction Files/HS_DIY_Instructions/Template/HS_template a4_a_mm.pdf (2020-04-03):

25

25

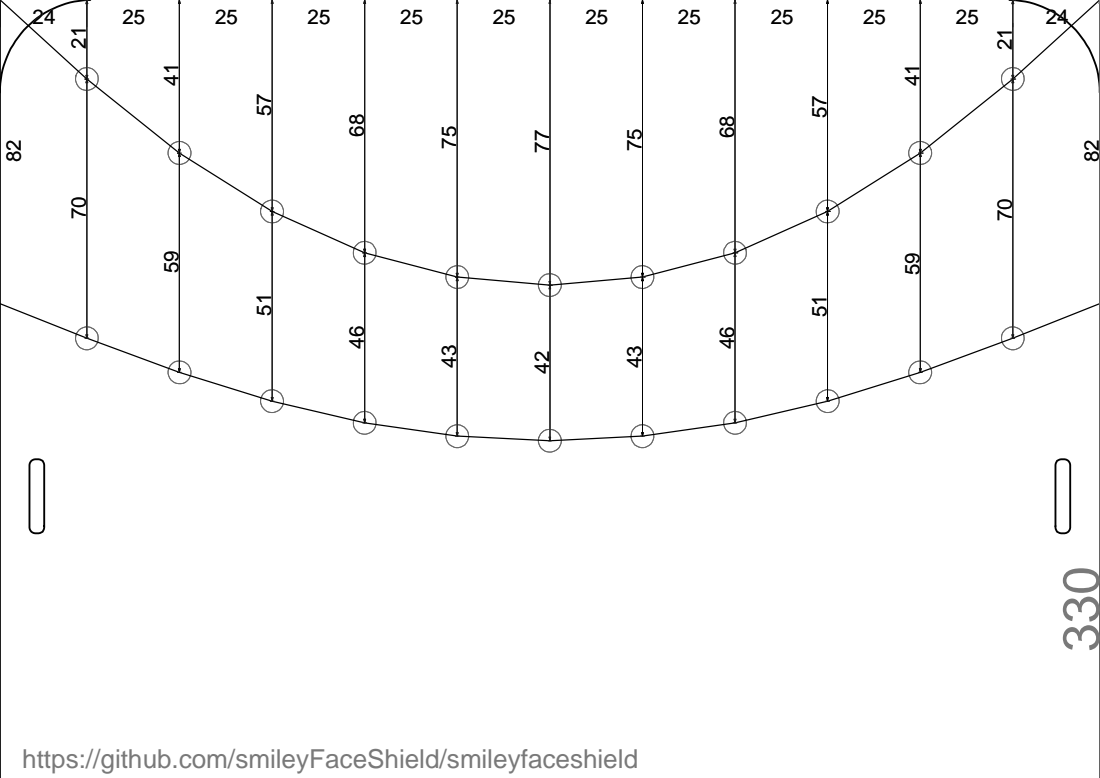
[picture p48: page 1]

https://github.com/smileyFaceShield/smileyfaceshield

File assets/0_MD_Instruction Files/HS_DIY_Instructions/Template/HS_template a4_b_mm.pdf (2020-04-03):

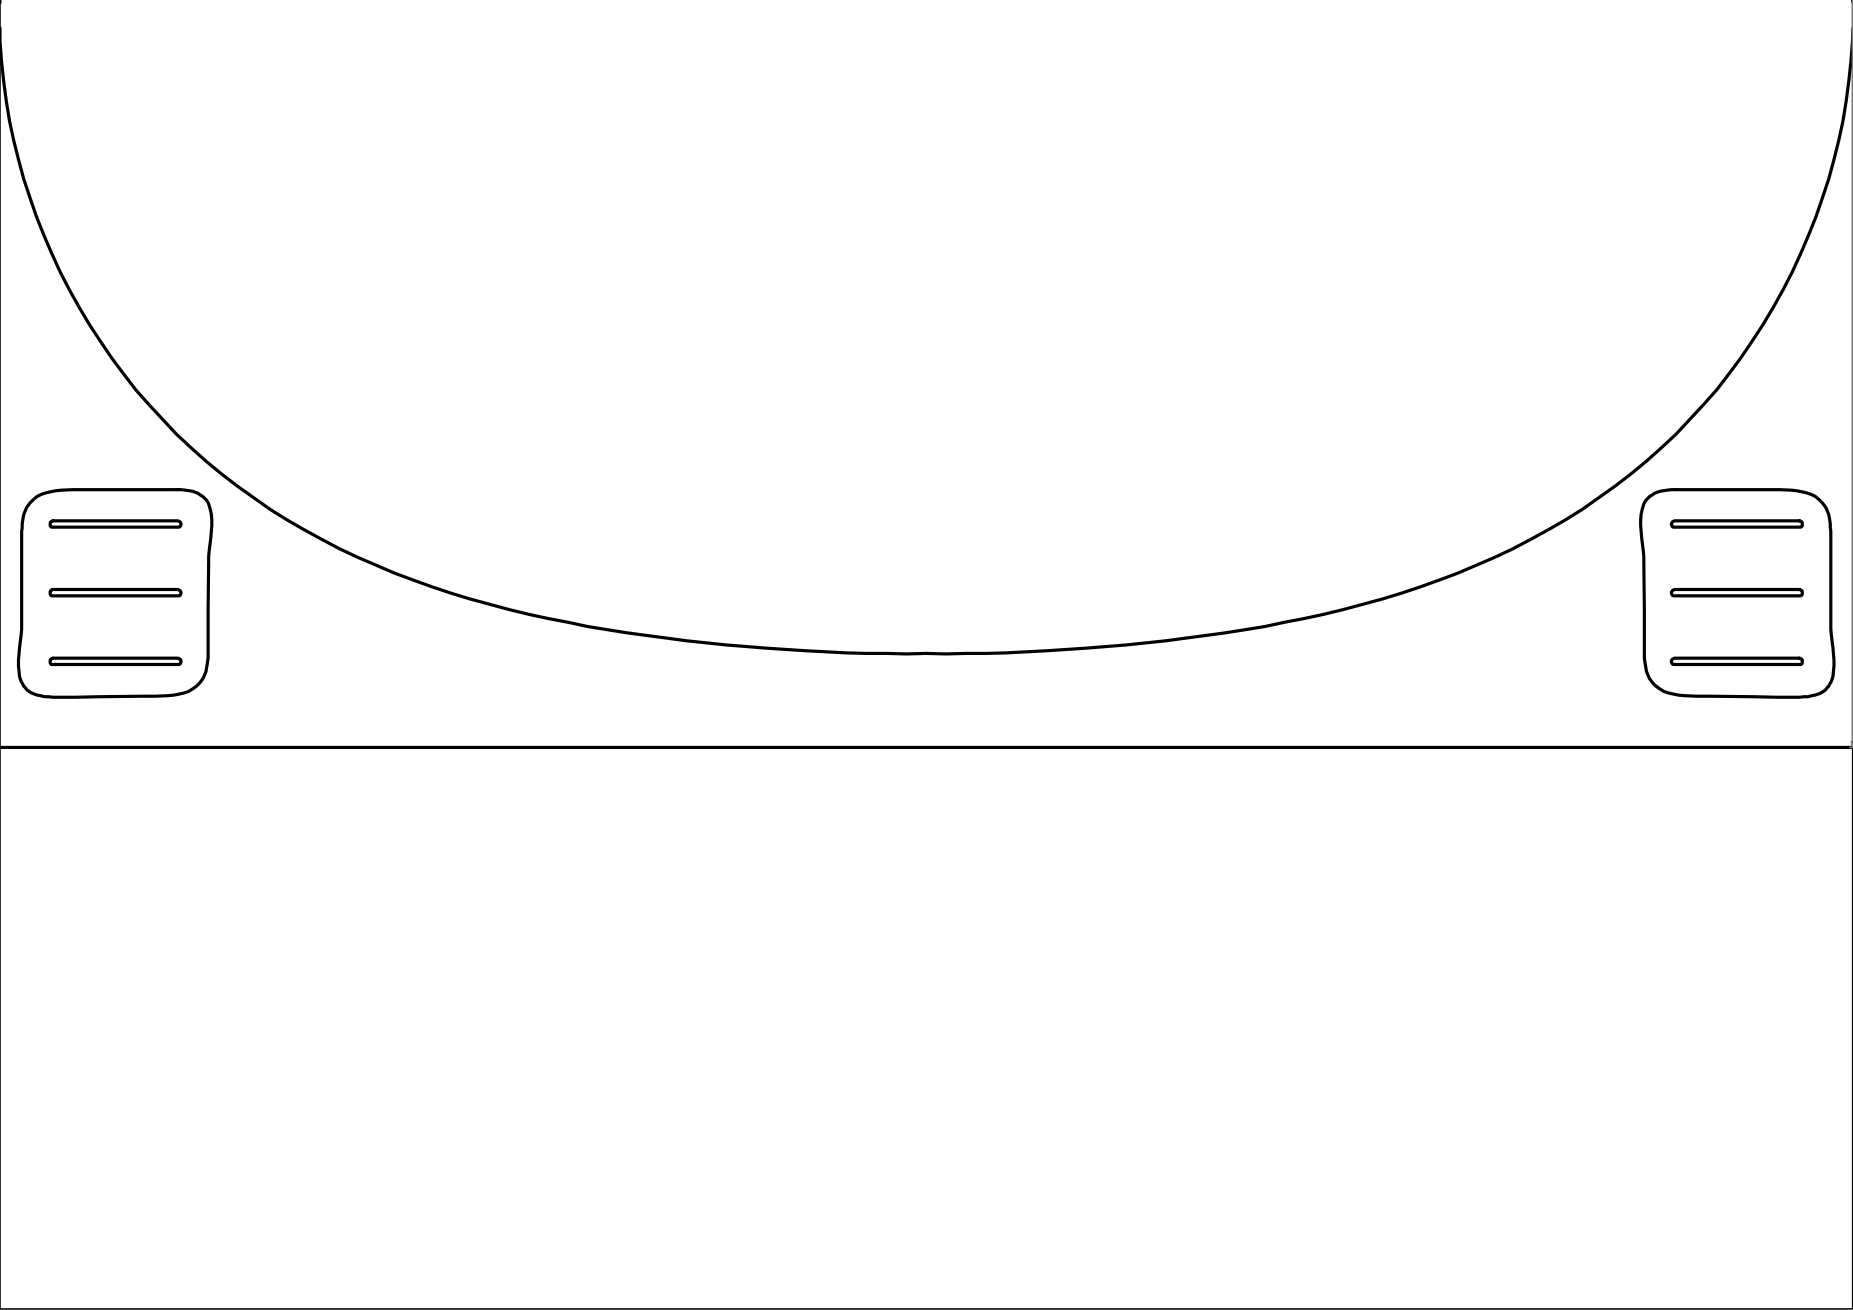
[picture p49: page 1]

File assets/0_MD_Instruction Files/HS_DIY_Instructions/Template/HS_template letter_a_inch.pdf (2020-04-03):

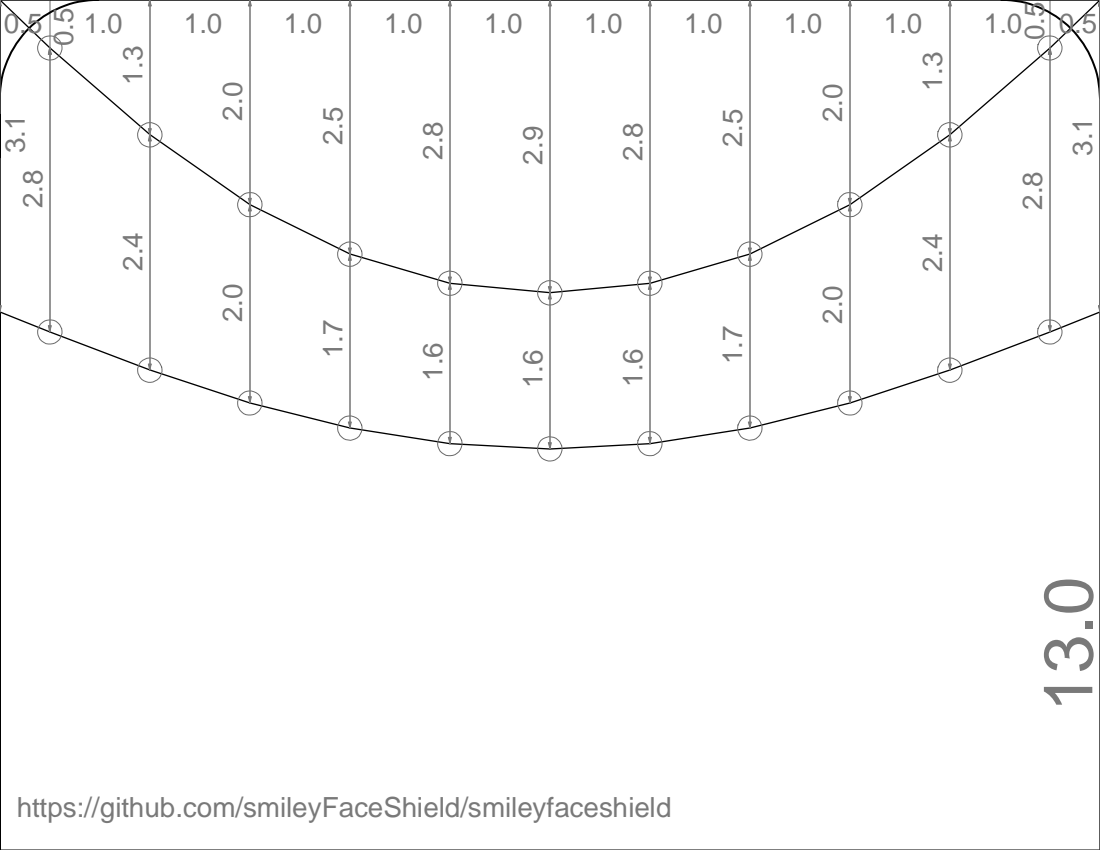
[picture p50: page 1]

https://github.com/smileyFaceShield/smileyfaceshield

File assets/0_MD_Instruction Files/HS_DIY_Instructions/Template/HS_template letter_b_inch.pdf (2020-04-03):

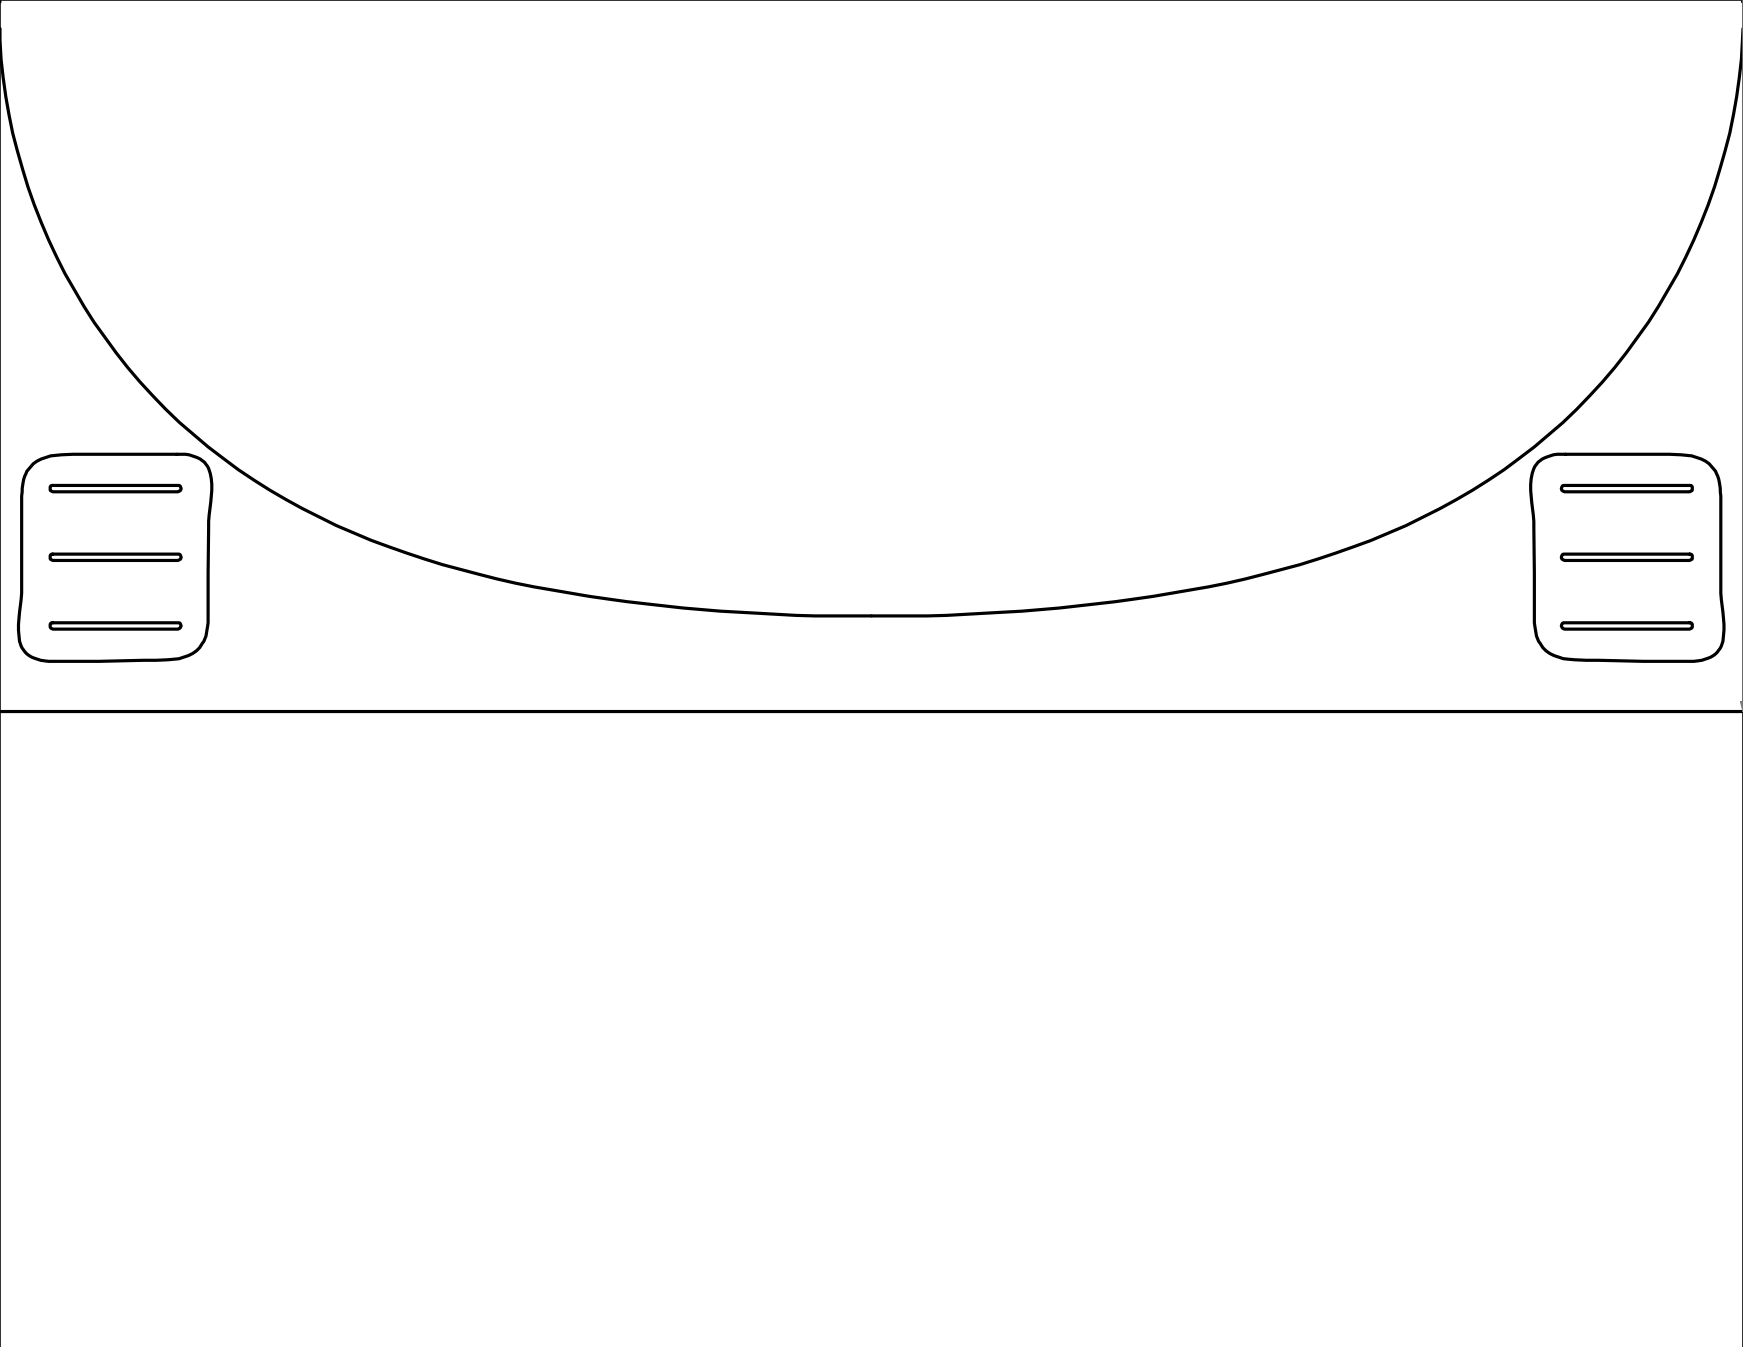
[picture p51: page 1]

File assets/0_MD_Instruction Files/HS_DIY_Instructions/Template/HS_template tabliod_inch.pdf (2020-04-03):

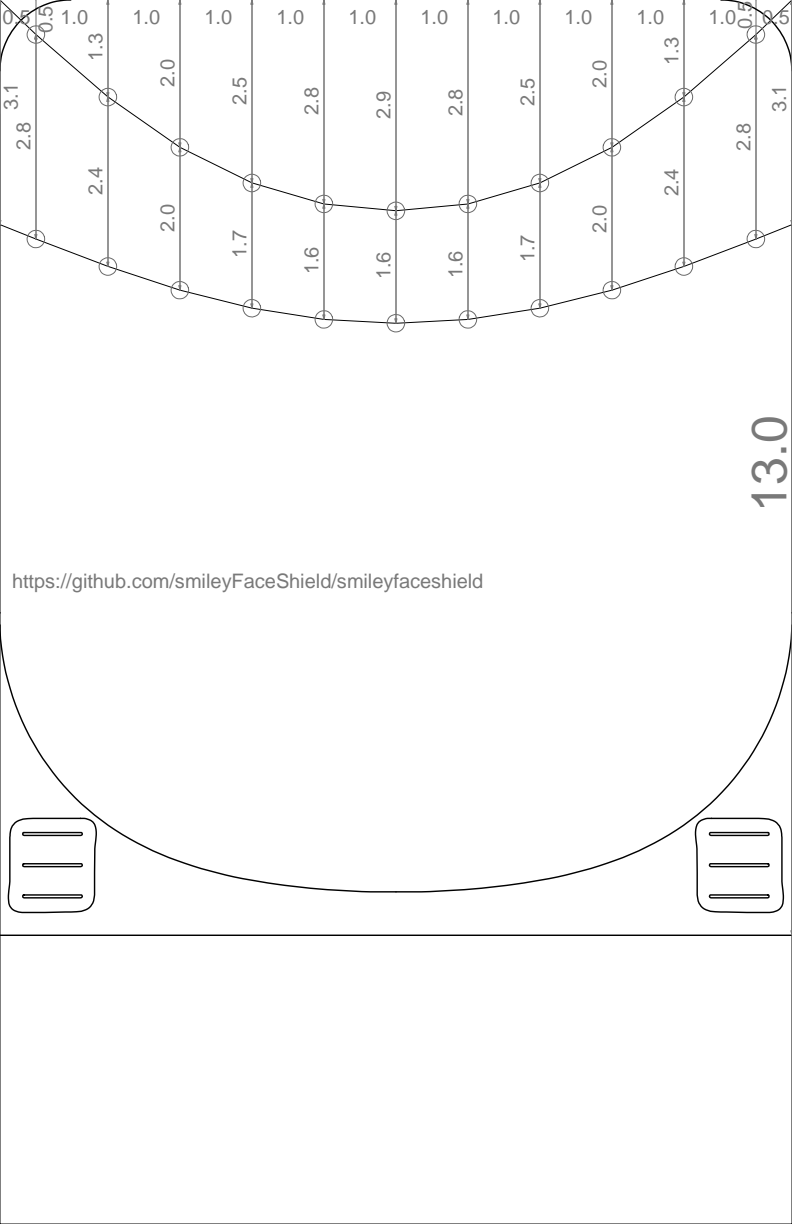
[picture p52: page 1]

https://github.com/smileyFaceShield/smileyfaceshield

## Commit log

2020-04-02 try adding boom symbol for laser cutter
2020-04-02 try adding parantheses around printer meaning optional
2020-04-03 add instructions content
    [List of graphic materials.xlsx]
2020-04-03 update instructions assets
    [3PartPressJigTemplate_400x400mm.dwg, 3PartPressJigTemplate_800x200mm.dwg, List of graphic materials.xlsx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]
2020-04-03 add helper file
    [instructionsTable_EN.csv]
2020-04-03 switch to tagline instead
2020-04-03 remove columns for materials and tools
2020-04-03 switch link URLS
2020-04-03 remove tools and materials columns actually
2020-04-03 add dash to lasercut
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2020-04-03 add link to print version of hand creasing : straight line
2020-04-03 fix bracket placement for link in instructions table
2020-04-04 try update snapwidget - don't know why cut off
2020-04-04 switch from markdown to html syntax for tagline link
2020-04-04 add video camera link to tagline of hand creasing
2020-04-04 add spacer before video camera and template links
2020-04-04 tweak style of instructions timer
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2020-04-04 try to fix positioning of video camera and template link
2020-04-04 add pressure creasing version
2020-04-04 add link to .pdf instructions for pressure creasing
2020-04-04 add pressure creasing link
2020-04-04 fix link to pressure creasing .pdf
2020-04-04 update title on pressure creasing
2020-04-04 add laser cut web instructions
2020-04-05 working on minor clarity edits to lasercut + pressure creasing
2020-04-06 update laser-cut + pressure creasing diagrams
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2020-04-06 update links to step diagrams in laser cut and pressure creasing
2020-04-06 add new step diagram links to laser cut instructions
2020-04-06 Update laserCutAndPressureCreasing_EN.md
    Test for text editing - Antiopi
    Update text step 1
2020-04-06 Update laserCutAndPressureCreasing_EN.md
    clean up formatting in step 1 of laser cut and pressure creasing
2020-04-06 add place holder disclaimer text and materials and tools text
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2020-04-06 clean up materials and tools formatting
2020-04-06 try fixing print docs link
2020-04-06 try to fix case sensitive URLs
2020-04-06 correct laser cut instructions
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2020-04-06 add template links for lasercut and pressure creasing and lasercut
2020-04-06 add spacer before email?
2020-04-06 try to get social media buttons on one line
2020-04-06 remove youtube button for now
2020-04-07 add links to templates and video for lasercut pressure creasing
2020-04-07 correct materials typo
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2020-04-07 update links to corrected laser-cut and press video
2020-04-07 cleanup root directory
    [instructionsTable_EN.csv]
2020-04-08 Create laserCutAndPressureCreasing_TR.md
    Created a file for Turkish translation
2020-04-08 Update laserCutAndPressureCreasing_TR.md
    starting to translate
2020-04-09 Arabic files and translation
    We might have trouble to the right to left format in Arabic, hebrew etc. I did a light googling https://stackoverflow.com/questions/2258028/rtl-in-markdown
    Here is one seems-to-simple suggestion:
    """Actually as my friend Aevyz reminded me, Markdown parses HTML in it.
    You won't need to change your parser. The quickest path to solve that I could think of is this:
    <div dir="rtl">
    سلام دنیا
    مرحبا العالم
    שלום בעולם
    ہیلو دنیا
    </div>
    So you need to add literally two lines to turn a whole document RTL, and by the way it will be better compatible than an own script. So i think this is an answer to the question.""""
2020-04-09 add instructions page for laser cut with plastic strap
2020-04-09 Update laserCut_AR.md
    add AR language tags to permalink and language variable
2020-04-09 Update laserCutAndPressureCreasing_AR.md
    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
2020-04-09 Update and rename laserCut_CHI.md to laserCut_ZH.md
2020-04-09 Update and rename laserCutAndPressureCreasing_CHI.md to laserCutAndPressureCreasing_ZH.md
2020-04-09 Create laserCut_PT.md
    Created doc for PT translation
2020-04-09 Update laserCut_PT.md
    Finished PT translation
2020-04-09 Create laserCutAndPressureCreasing_PT.md
    Created a PT translation
2020-04-09 Update laserCutAndPressureCreasing_PT.md
    Translated to PT until "Materials"
2020-04-10 Create LaserCut_TH.md
    Created Thai translation file
2020-04-10 Update LaserCut_TH.md
    Translated text in Thai
2020-04-10 Update laserCutAndPressureCreasing_PT.md
    Completed PT translation
2020-04-10 Update laserCutAndPressureCreasing_PT.md
    Finished and corrected PT translation
2020-04-11 Create laserCut_TR.md
    Created a file for turkish translation
2020-04-11 Update laserCut_TR.md
    First Turkish Translation
2020-04-11 Update laserCut_TR.md
    updated translation
2020-04-13 Create LaserCutAndPressureCreasing_TH
    Create File for thai translation
    Complete the thai translation
2020-04-13 Create laserCutAndPressureCreasing_JA.md
    Created a file for the Japanese translation
2020-04-13 Create WaveSHIELD_TH.md
    Create thai translation file
    Insert translated text
2020-04-13 correct accidental turkish translation of step 8 of pressure creasing : )
2020-04-13 Update laserCutAndPressureCreasing_JA.md
    Translation in Japanese done
2020-04-13 Create laserCutWithPlasticStrap_JA.md
    Created the file for Japanese
2020-04-13 Update laserCutWithPlasticStrap_JA.md
    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
2020-04-13 Update laserCutWithPlasticStrap_JA.md
    modified the title
2020-04-13 Update laserCutAndPressureCreasing_JA.md
    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
2020-04-13 Create LaserCut_JA.md
    created the file for Japanese
2020-04-13 Update LaserCut_JA.md
    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
2020-04-13 Delete laserCutWithPlasticStrap_JA.md
    I found the original file is yet to be done
2020-04-13 Update LaserCut_JA.md
    I had forgotten to translate the section "tools", so dealt with it
2020-04-13 Create laserCut_DE.md
    Created new file and translated into german
2020-04-13 Create laserCutAndPressureCreasing_DE.md
    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
2020-04-15 LaserCut in French
    French translation for the LaserCut instructions
2020-04-15 Create LaserCutAndPressureCreasing French
    Tranlsation to French of the instructions for laser cut and pressure creasing
2020-04-15 Create laserCut_ES.md
    Created the ES file
2020-04-15 Create LaserCutAndPressureCreasing_ES.md
    created the ES file
2020-04-15 Create LaserCutWithPlasticStrap_ES.md
    Created ES file
2020-04-16 Update LaserCutAndPressureCreasing_TH.md
    adding language key : )
